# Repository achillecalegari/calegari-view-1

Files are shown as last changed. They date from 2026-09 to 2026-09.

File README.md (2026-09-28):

# Calegari View 1

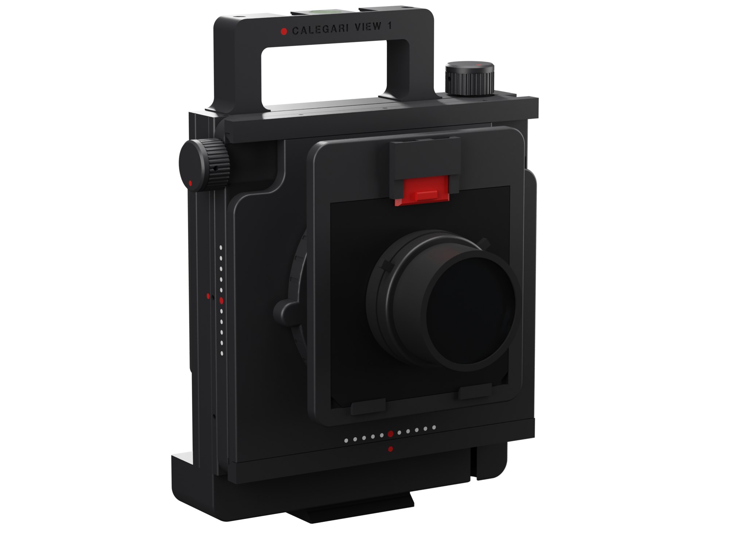
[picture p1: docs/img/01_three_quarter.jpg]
Calegari View 1


A rigid 6x7 architecture camera you can print at home. Screw-driven rise and shift on two axes, helicoid focusing, Mamiya RB67 film backs, large-format wide-angle lenses on Linhof Technika boards.

**[Project page](https://achillecalegari.github.io/calegari-view-1/)** · [Shopping list](docs/bom.md) · [Printing](docs/printing.md) · [Assembly](docs/assembly.md) · [Calibration and tests](docs/calibration.md) · [Using the camera](docs/using.md) · [Design notes](docs/design.md)

## Why I made it

I have wanted a view camera for years. The rigid kind, compact, built for architecture: you put it on the tripod, raise the lens a couple of centimetres and the verticals stay vertical, straight on the negative, with nothing to fix afterwards.

The problem is the price. A new Arca-Swiss or Silvestri costs thousands before you add a lens, and the used market is not much kinder. So I designed my own, around what I already had: a Bambu Lab P1S, the Mamiya RB67 backs you can find everywhere for little money, and a used large-format wide angle.

This repository is the whole camera: the files to print, the parametric model they come from, the shopping list with links, and step-by-step instructions written for someone who has never held a view camera. Every hole of every printed part is shown in a picture with a letter, and a table says what goes into it. Without back and lens, the parts cost about 350 EUR, much of it in packs of screws and inserts that will outlast the camera.

## What it is

| | |
|---|---|
| Format | 6x7 (56 x 69.5 mm); the gate also clears 6x8 |
| Back | Mamiya RB67 Pro, Pro-S, Pro-SD on a Graflok-type interface; Mercury Works Graflok 23 ground glass. The back turns a quarter turn for portrait, with a click at both positions |
| Lens | 65 mm large-format wide angle in Copal 0 (Super-Angulon 65/8, Nikkor-SW 65/4, Grandagon-N 65/4.5) on a Linhof Technika 99 x 96 board |
| Movements | rise and fall +/-25 mm, lateral shift +/-25 mm, on printed dovetail ways with gibs; M6 lead screws, 1 mm per turn, hard stops, zero detents |
| Focus | M65 helicoid 17-31 on a metal flange, 116 mm focus ring with a tab and a hidden infinity stop, infinity to 0.47 m |
| Tripod | one Arca-Swiss plate under the body; the camera stays upright for portrait, only the back turns |
| Lens change | every lens on its own board: a spring latch, no tools, ten seconds; printed shims put every lens at infinity on the same stop |
| Handle | one top handle with the engraved name, two ISO 518 accessory shoes and a bull's-eye level; the rise knob sits on the body top beside it |
| Size | 185 x 247 mm front (170 mm body, handle and knobs included), 161 mm deep with back and lens |
| Weight | about 1.2 kg without back and lens (about 830 g of printed ASA, 360 g of metal); about 2.1 kg ready to shoot (estimate) |

The body, the Y plate and the lens panel are flat slabs that slide face to face on printed dovetail ways, like the standards of a technical camera. Every plate covers the opening of the one behind it with at least 13 mm of black velvet at every shift position: that is how it stays light-tight without a bellows. The back sits on a round rotator that turns in the body's rear face, sealed by a labyrinth and a ring of velvet: for vertical pictures you turn the back, and the tripod, the level and the knobs stay where they are. No screw head shows on the front or the sides.

| | | |
|---|---|---|
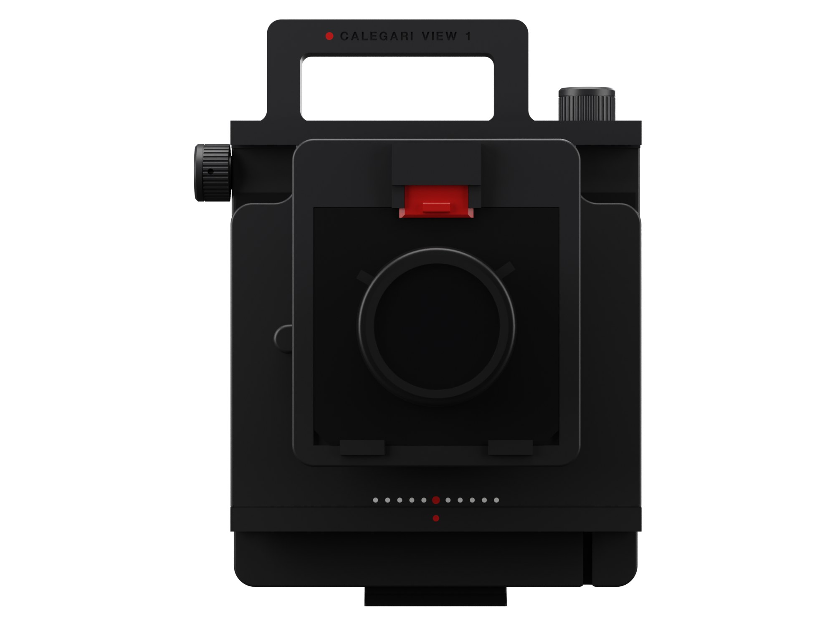
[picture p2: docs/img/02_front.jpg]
front
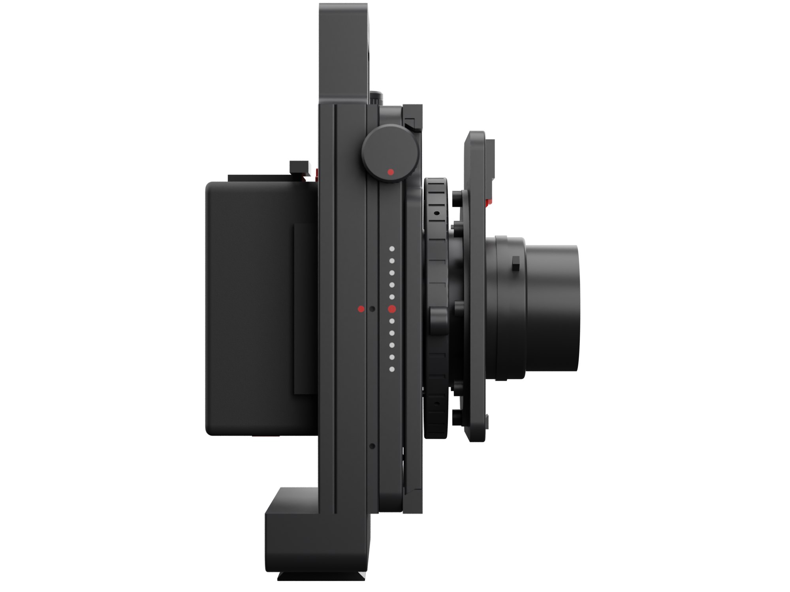
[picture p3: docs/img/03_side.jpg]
side
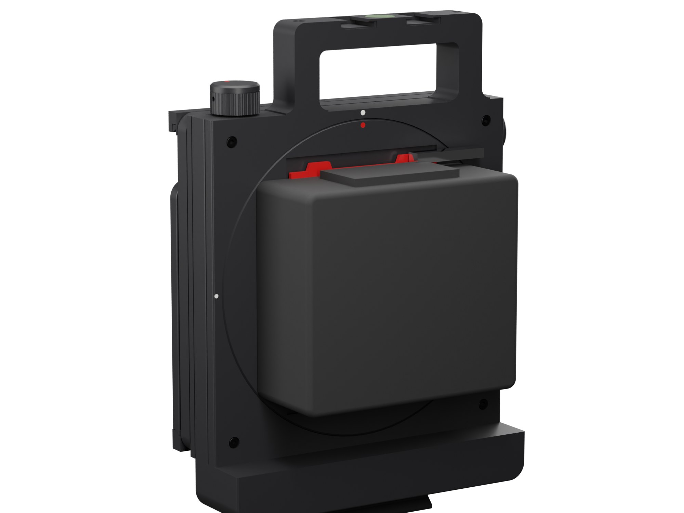
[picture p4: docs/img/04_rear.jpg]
rear
|  |  |  |
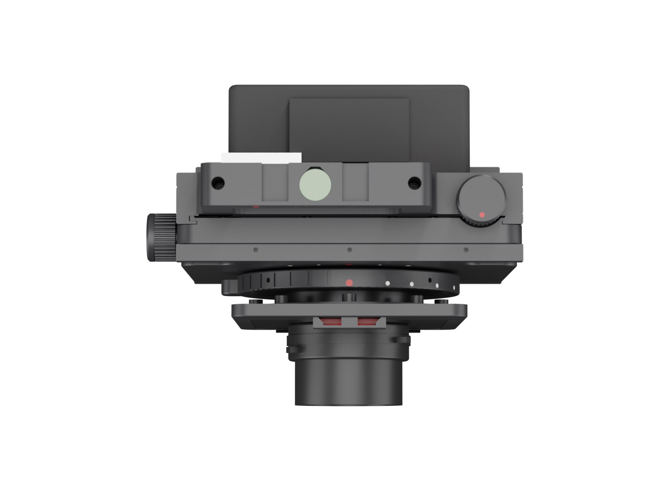
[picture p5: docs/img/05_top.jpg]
top
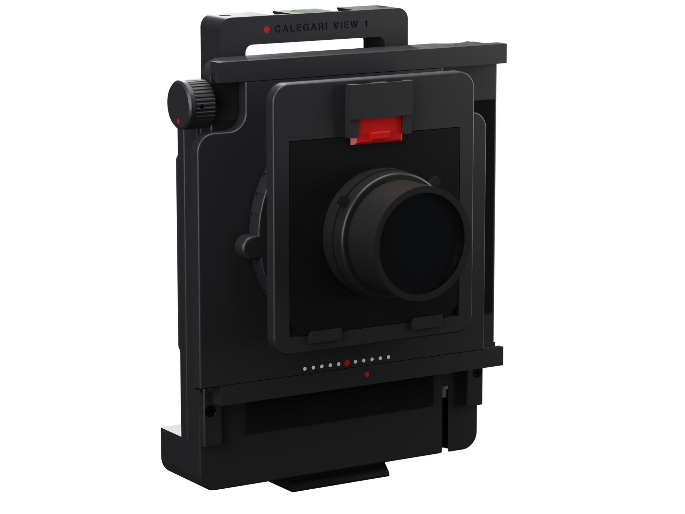
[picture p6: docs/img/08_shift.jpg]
rise and shift
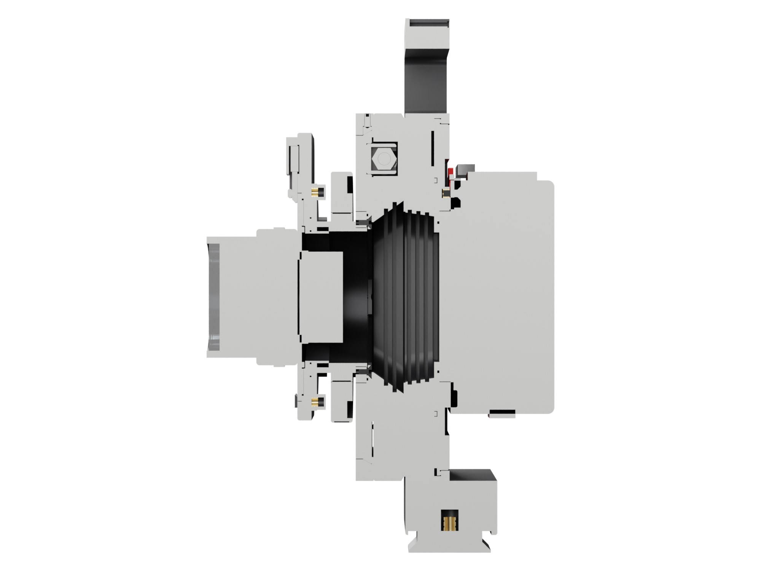
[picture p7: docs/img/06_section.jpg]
section
|  |  |  |

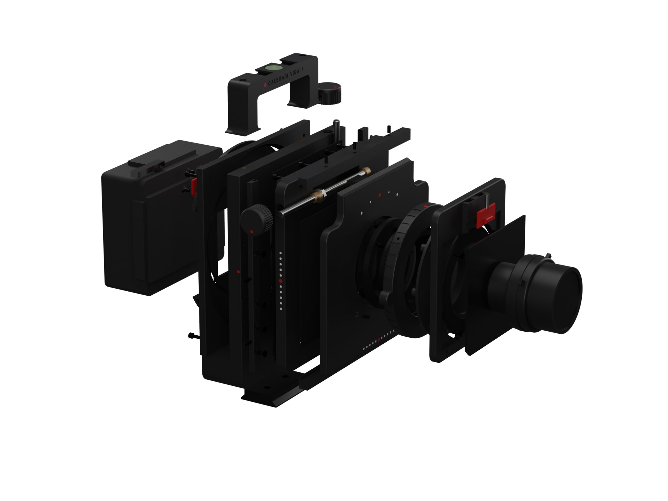
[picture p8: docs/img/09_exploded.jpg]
exploded


## Status

The design is complete and checked in software, not yet proven in the hand.

- `cad/check.py`: no interference between any of the components, screws against the bottom of their holes included, at home and at the four shift extremes, with the Graflok blade and the board latch both closed and open, with the back in landscape, in portrait and halfway between. Every printed part is a single solid.
- `cad/seal_check.py`: the velvet seal is at least 13 mm wide at both sliding interfaces, at every shift position in 5 mm steps.
- `cad/optics_check.py`: a ray trace from the lens to the corners of the frame, with the back in landscape and in portrait. Single movements up to 25 mm are clean at f/22 and f/8 at infinity. Combined rise and shift are clean up to 19 + 19 mm at infinity at f/22, 17 + 17 at f/8, 13 + 13 at 0.7 m and 9 + 9 at the closest focus (0.47 m): the 61 mm bore of the helicoid's rear stub is the limit.
- `print/PRINTABILITY.txt`: overhangs and bridges of every part in its print orientation. No part needs supports.
- Before the first print the design went through three rounds of independent review: mechanics, light and optics, printability, assembly and use. What changed is in the [design notes](docs/design.md).

What only the first physical build can prove is listed in [calibration and tests](docs/calibration.md). It starts with about four hours of test prints: the shrinkage of your ASA, the rotator on your RB67 back, and slices of the dovetail ways to slide by hand. They come before the body.

## The model

Everything is generated from Python with [build123d](https://github.com/gumyr/build123d). All dimensions live in `cad/params.py`: change a value (a lens with a different flange distance, a helicoid that turns a different angle, a tighter or looser fit) and rebuild the whole camera.

```bash
python -m venv .venv && .venv/bin/pip install -r requirements.txt
cd cad
../.venv/bin/python check.py          # interference, single-solid and clamp checks
../.venv/bin/python seal_check.py     # velvet seal widths over the whole shift range
../.venv/bin/python optics_check.py   # ray trace: vignetting at shift, aperture and focus (about 15 minutes)
../.venv/bin/python export.py         # STEP, oriented STL, AMS inlays, P1S plates, test prints
../render/gen_all.sh                  # product and overview images in docs/img (needs Blender)
../render/figures.sh                  # figures for every guide, docs/img/asm, cal, use and bom (needs Blender)
../.venv/bin/python plate_figs.py && ../render/figures.sh $(ls ../out/figs | grep ^p_)   # the print plates
../.venv/bin/python ../render/diagrams.py   # the flat calibration diagrams
```

The STEP files in `print/step` open in Fusion, FreeCAD or any CAD.

## Credits

The RB67 interface was measured from two open designs that take the same backs: [Super-67](https://github.com/DamienHazard/Super-67) by Damien Hazard, and the [RB67 pinhole body](https://www.thingiverse.com/thing:7270507) by bogdanbogvzyan, tested with Pro-S and Pro-SD backs. Lens data come from the Schneider, Nikon, Rodenstock and Fujinon catalogues and the Mercury lens database; Graflok 23 figures from Mercury Camera's guide.

## License

[CC BY-NC-SA 4.0](LICENSE). Build it, change it, share it with credit; do not sell it.

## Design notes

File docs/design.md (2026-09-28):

# Design notes

[Back to the project](../README.md)

## Architecture

The camera is a stack of flat slabs on the optical axis, from the film forward:

Exploded view

1. **Rotator** (printed): the round seat of the back. The back's nose pocket, the fixed bottom rail that hooks the back and releases the Pro-S dark-slide interlock, and the red clamp blade with two tongues. It turns a quarter turn for portrait.
2. **Rear frame** (printed): screwed to the body with four M3, it holds the rotator's flange over a ring of velvet.
3. **Body** (printed, one piece, 170 mm square): the round seat of the rotator with a labyrinth ridge, the stepped gate, the two vertical dovetail rails, the rise screw, and the Arca plate underneath.
4. **Y plate** (printed): rises and falls between the vertical rails, carries the two horizontal dovetail rails and the shift screw.
5. **Lens panel** (printed): shifts left and right, carries a metal M65 flange.
6. **Optics on the flange:** the helicoid, the printed adapter ring, the Technika board holder and the lens.

Section

The light seal is the flatness of these faces. Each plate covers the opening of the one behind it, and the band of black velvet between them is at least 13 mm wide at every shift position (`cad/seal_check.py`, swept every 5 mm). The thin flanges of the dovetail rails set the 0.8 mm gap and the velvet is compressed in it, so the velvet never carries load.

## Choices and why

| Choice | Why |
|---|---|
| 6x7 with RB67 backs | backs are common and cheap; the Graflok-type interface is simple enough to print; the gate also clears 6x8 |
| 65 mm lenses in Copal 0 | 33 mm equivalent on 6x7, cheap used, image circles of 153 to 170 mm for large shifts |
| Technika 99 x 96 boards | the most common board: lenses often come mounted on one, and it swaps with 4x5 field cameras |
| One board per lens, spring latch | a lens changes in ten seconds without tools; the red latch slides in a printed dovetail, held by two screws from the back, so nothing shows on the front; printed shims under the shutter (0.4 to 1.2 mm) let every lens reach infinity on the same stop |
| Metal M65 flange on the lens panel | a printed thread carrying the lens and the focusing torque was the weakest point of the first design |
| Printed adapter ring as the calibration part | if infinity is out of reach, reprint a thinner 20-minute part instead of a plate |
| Printed dovetail ways with a gib | the way view cameras have always done it: nothing to buy, nothing to align, play taken up by three grub screws. The rails print as separate parts, so the sliding flanks come from the printer's perimeters, not from stair-stepped layers; test coupons prove the fit on your printer before the big parts |
| Front standard assembled on the bench, then slid in from the top | the Y plate's front overhangs the vertical rails (the shift screw passes over them), so it goes in like a drawer; the rise nut turret is screwed on afterwards through the plate |
| M6 threaded rod and brass nut, 1 mm per turn | fine control, self-locking under gravity, parts from any hardware shop; the nut floats 0.5 mm so the rod never binds. The rise rod ends in a plain M6 nut and washer, fixed on the bench and hidden under the camera. The shift rod shows nothing on the left: it ends in a blind seat, and a washer and a nut locked inside the channel hold it against the knob side. No hardware in sight on the front or the sides |
| All small hardware in M3 | one insert size (M3 x 3 x 5) for every insert, socket heads in three lengths, countersunk in two (only where a head must sit flush: the flange, the Graflok blade, the thin vertical rails and the board holder), one grub size. Four assortments and an M6 set buy the whole camera; three hex keys build it |
| Shift nut turret keyed into the lens panel | the hard stops push on the pocket walls, not on the glue |
| O-ring drag instead of lock wheels | lock wheels moved the composition as you tightened them; constant drag holds the plate and never shifts it |
| Ball-plunger detents | you feel zero without looking; the rise and shift plungers sit in through holes, so they are set from behind and then sealed; the third one clicks the back at landscape and portrait |
| Rise and fall +/-25, the same as lateral shift | the base under the body is 25 mm tall so that at full fall the Y plate stays clear of a clamp's jaws; the two scales read the same way |
| Rotating back instead of an L bracket | for portrait the camera stays on its plate: the level, the handle and the knobs keep their meaning and the tripod head does not have to flop over. The rotator turns in the body's rear face on a velvet ring held by a screwed rear frame; a labyrinth (a ridge on the body in a groove of the rotator) keeps light out while it turns; a POM ball plunger clicks at landscape and portrait, and a grub screw in an arc groove stops it just past both. Plunger and grub go in from the front, under the Y plate, so nothing shows |
| Square body, 170 mm | the rotator needs a circle of 165 mm around the back, and a square body is the calmest shape around a circle; the window gets 12 mm corners so the labyrinth fits around it |
| One top handle, bolted, as deep as the body | feet flared into the body, 9 mm of finger room to the rise knob beside it; nothing overhangs the film back's advance lever; room on top for two ISO 518 accessory shoes and a bull's-eye level, and on its front for the engraved name |
| One bull's-eye level | a tubular vial reads one direction only; the one that keeps verticals vertical is front to back. The camera never goes on its side, so one level serves both orientations |
| Hidden infinity stop | a pin on the lens panel runs in a groove under the focus ring and meets one solid block at infinity; you set it by turning the ring on the helicoid, no adjusting screw |
| Recessed dot scales, red only for zeros, infinity and release controls | print cleanly in multi-material; red means "this is the reference" or "this lets go" |

## Design reviews

The design went through three rounds of independent review before the first print: mechanics and tolerances, light and optics, printability, and assembly and use by someone who has never built a camera. Each finding was measured in the CAD, fixed, and checked again. The main ones:

| Area | Found | Fix |
|---|---|---|
| RB67 interface | the dark slide could not come out; the latch bars had no tongues; nothing released the Pro-S interlock | Graflok seat rebuilt on the scheme of a body tested with Pro-S and Pro-SD, dark-slide passage open to the right |
| Mechanics | industrial linear guides were overkill and made the build long | printed dovetail ways with gibs, test coupons |
| Assembly | the Y plate could not go on once the rails were fixed; the rod nuts could not be tightened inside the camera | the plate slides in from the top; the rise end nut is fixed on the bench, the shift thrust nut before the lens panel goes on |
| Assembly | the board holder's screws were unreachable under the focus ring | they now go in from the front, under the board, into eight inserts in the adapter |
| Mechanics | the Graflok wheel did not turn its screw; screws too long in six places; the detent balls never touched the plate | screw head glued in the wheel; every screw length checked against its hole; balls 1.0 mm proud with a 0.3 mm seat |
| Mechanics | the shift hard stop loaded a glued joint | the turret sits in a 2.5 mm pocket |
| Optics | the lens panel bore cut the corner at large combined shifts | flare lobes on the diagonals; single movements reach 25 mm clean at infinity |
| Optics | the ray trace left out the helicoid's rear stub, whose 61 mm bore is the narrowest opening | stub modelled (5.2 mm, the lens panel relieved behind the flange); combined movements are clean to 19 + 19 at infinity (f/22), 17 + 17 at f/8, 13 + 13 at 0.7 m, 9 + 9 at the closest focus (0.47 m) |
| Light | screw holes and a detent hole could carry light around the velvet | velvet discs over the turret screws, the detent moved outside both velvets, black paint in the flange's unused holes, light-trap grooves in the seat and the flange pocket |
| Printing | knife edges, a hood printed in the air, thin walls under inserts | chamfers and lands on every bed edge that mates, a hood bridging rail to rail, thicker walls |
| Use | tubular levels could not show the tilt that bends verticals | a bull's-eye level on the handle |

## Automated checks

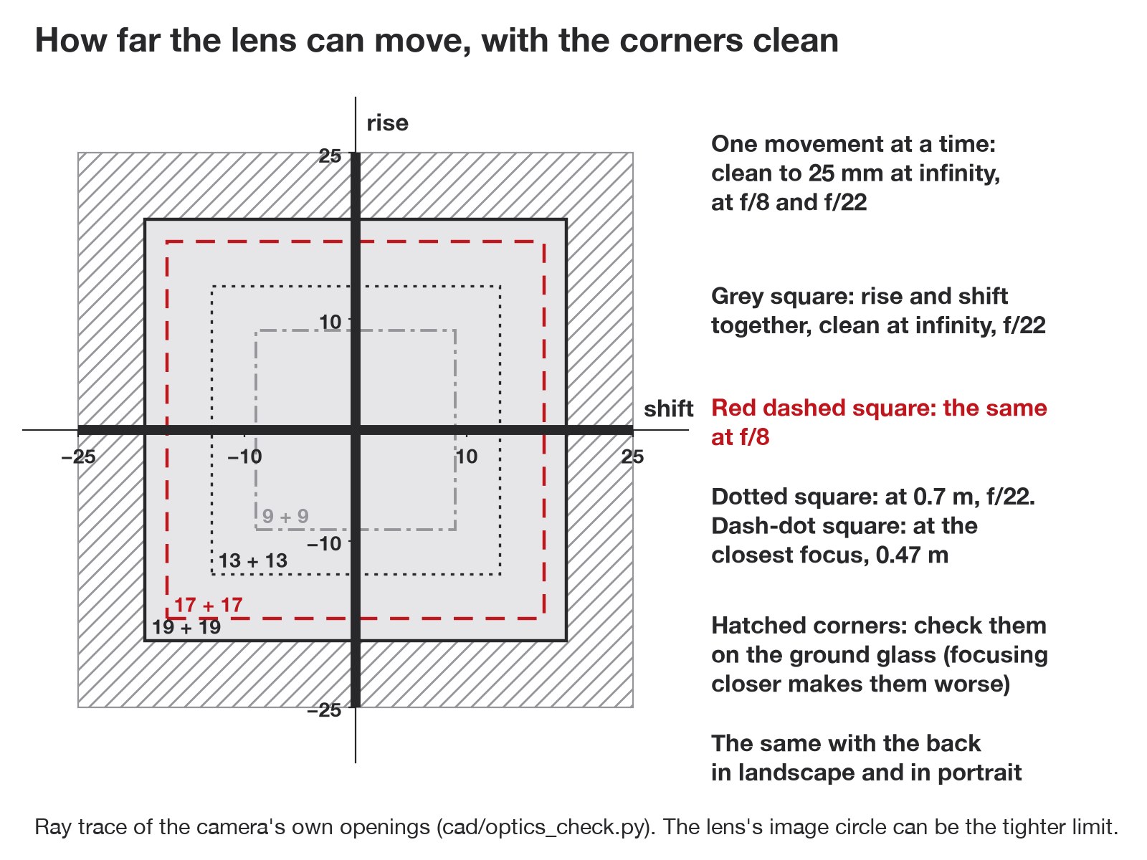
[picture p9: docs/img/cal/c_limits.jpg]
Shift limits from the ray trace


| Script | What it proves |
|---|---|
| `cad/check.py` | every printed part is one solid; no two parts intersect (threshold 0.3 mm3) at home and at the four shift extremes, with the blade and the board latch closed and open, with the back in landscape, in portrait and halfway, including every screw against the bottom of its hole |
| `cad/seal_check.py` | minimum width of the velvet band around the light path at both sliding interfaces, at every shift position in 5 mm steps |
| `cad/optics_check.py` | rays from the lens pupil to the four corners of the frame, through every part, at the shift, aperture and pupil positions listed in the script, with the back in landscape and in portrait |
| `cad/export.py` | `print/PRINTABILITY.txt`: overhangs and bridges of every part in its print orientation |

## Open points

- **RB67 interface.** It is derived from reference designs and has not yet been fitted on a real back. The RB67 model used by the checks has no lips or slots, so the back-to-rotator fit is not part of the automated check: it is test print #1 ([calibration](calibration.md#1-before-printing-the-body-test-prints)).
- **Wind-stop coupling.** Not implemented: after each frame, press the back's own release lever, as on the Mamiya Press. A plunger at the top-left corner of the rotator is the planned v2 feature (M7 in the calibration list).
- **Lens tilt.** The board can be squared in rotation through the holder's arc slots, but it cannot be adjusted in tilt. Parallelism relies on flat prints: check it with the procedure in calibration.
- **Focus scale.** It is correct only once `HELI_ROT` and `FOCUS_DIR` are measured on your helicoid.

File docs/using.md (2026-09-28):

# Using the camera

[Back to the project](../README.md)

A first-timer's guide, from the bag to the negative. If a word is new, [the camera in five minutes](calibration.md#the-camera-in-five-minutes) explains it.

## What to bring

- The camera, with a lens on its board in the holder.
- The ground glass and one or more RB67 backs, loaded, dark slides in.
- A loupe (4x to 8x), a dark cloth, a cable release that screws into the shutter.
- A light meter, or a meter app on the phone.
- A tripod with an Arca-Swiss clamp.
- Other lenses on their own boards, rear caps on.

## 1. Set up

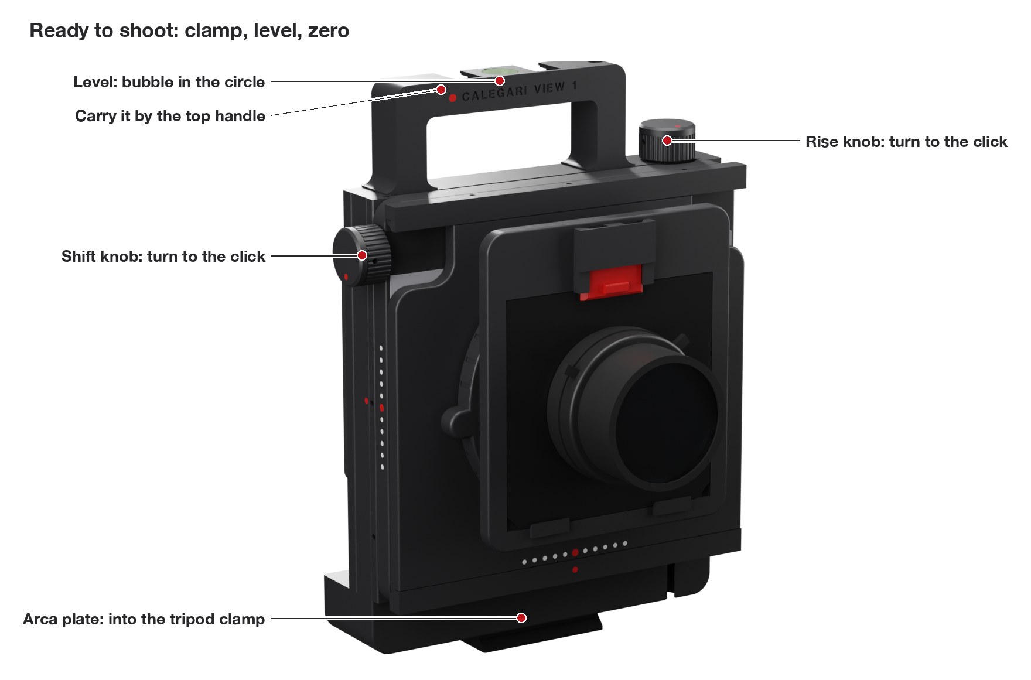
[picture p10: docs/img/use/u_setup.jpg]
Ready to shoot


1. **Clamp the camera** by its Arca plate. It stays upright for vertical pictures too: you turn the back, not the camera. Carry it by the top handle.
2. **Level it.** Adjust the tripod head until the bubble on top of the handle is in the middle of its circle. It reads both directions, and it stays right when you turn the back. The one that matters most is front to back: a camera tilted up or down makes the vertical lines of a building lean. This is the whole point of the camera, so do not skip it.
3. **Set both movements to zero.** Turn each knob until it clicks.
4. **Horizontal or vertical.** Take hold of the back (or the ground glass) with both hands and turn it a quarter turn: anticlockwise from landscape to portrait, as you look at it from behind. It clicks at both ends and stops just past them. The red dot on the back's rim sits on the big white dot at the top for landscape, on the small one on your left for portrait. The rise knob still raises the lens, whichever way the picture is.

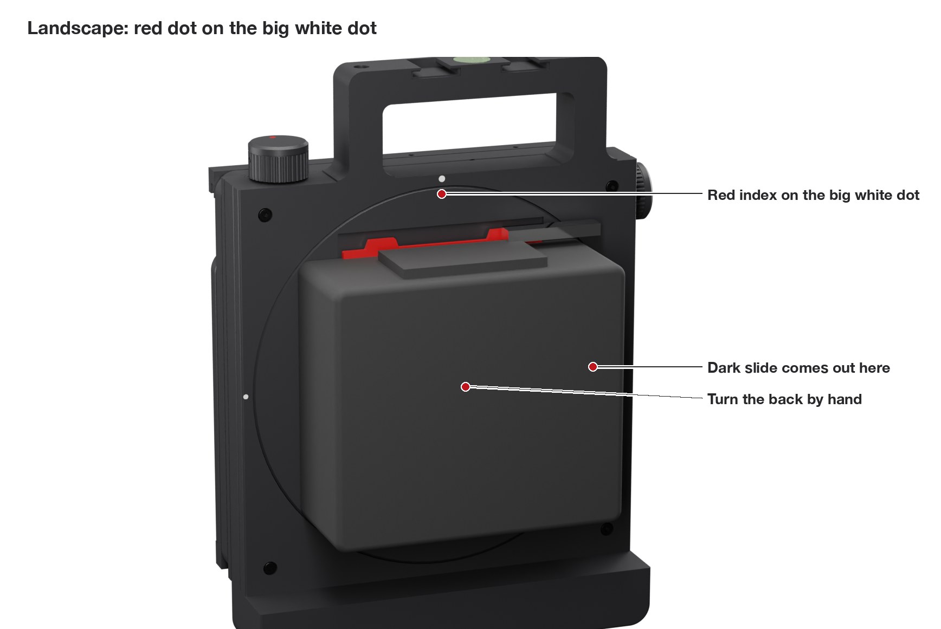
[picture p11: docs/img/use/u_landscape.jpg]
Landscape


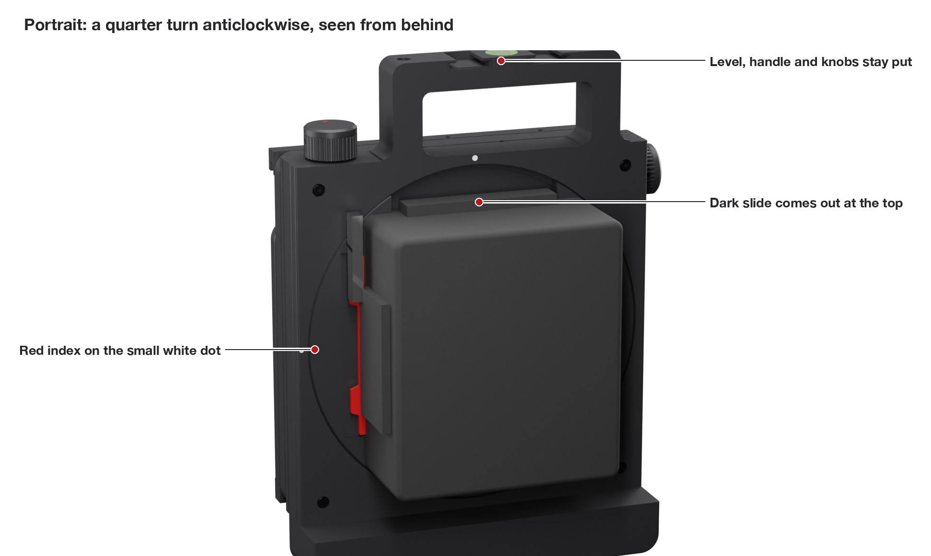
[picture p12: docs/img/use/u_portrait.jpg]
Portrait


## 2. Compose on the ground glass

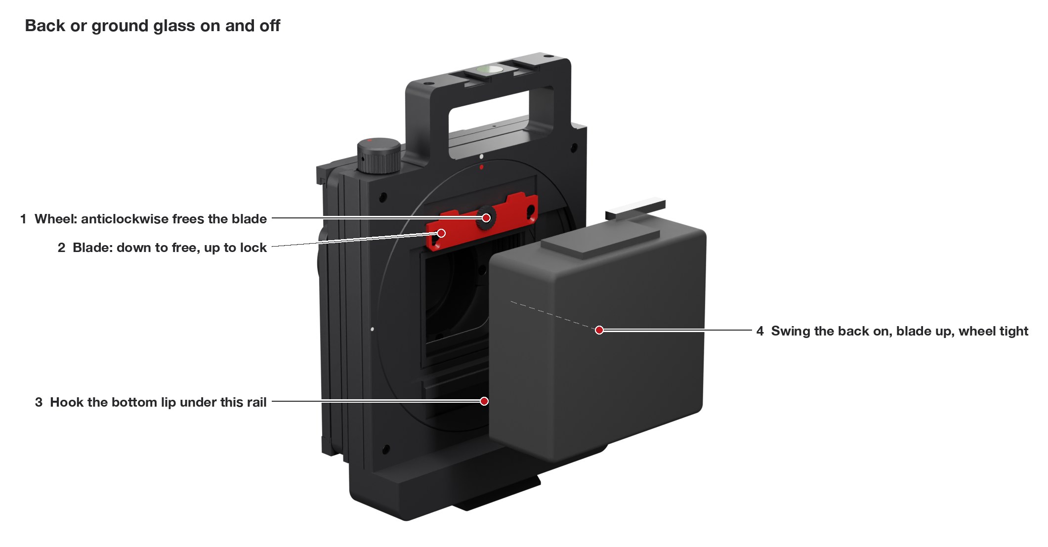
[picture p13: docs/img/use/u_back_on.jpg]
Back or ground glass on and off


1. **Ground glass on.** If a back is mounted, check its dark slide is in, then take it off: loosen the wheel, slide the red blade down, lift the back off the bottom rail. Mount the ground glass the same way in reverse.
2. **Open the shutter.** Set the speed dial to **T** or **B** and fire, or push the *press focus* lever. Turn the aperture to its largest opening.
3. **Look.** Cloth over your head and the camera. The image is upside down and mirrored left to right: after ten minutes you will stop noticing. The glass shows a little more than the film: compose inside the 6x7 marks (the Mercury glass has them; with another glass, mark the 69.5 x 56 mm frame with a fine pen during calibration).
4. **Use the movements instead of pointing the camera.** The top of the building is cut off? Do not tilt the camera up: turn the top knob to raise the lens (rise). Too much of the left side? Turn the side knob to shift the lens sideways. The picture slides across the glass while the verticals stay vertical.

**Reading the movements.** Each knob turn moves the lens 1 mm; the red dot on the knob top helps count turns. For bigger moves, read the dots on the plates:

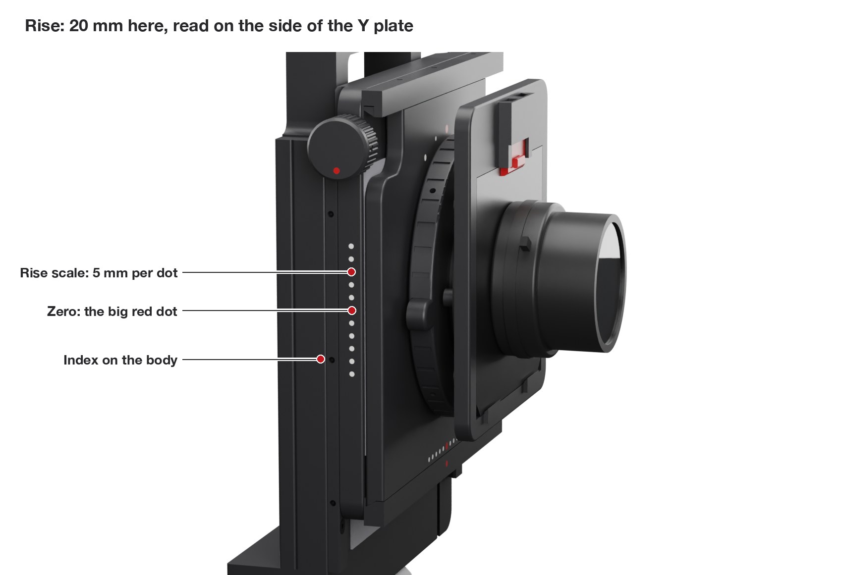
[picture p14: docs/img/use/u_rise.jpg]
Rise


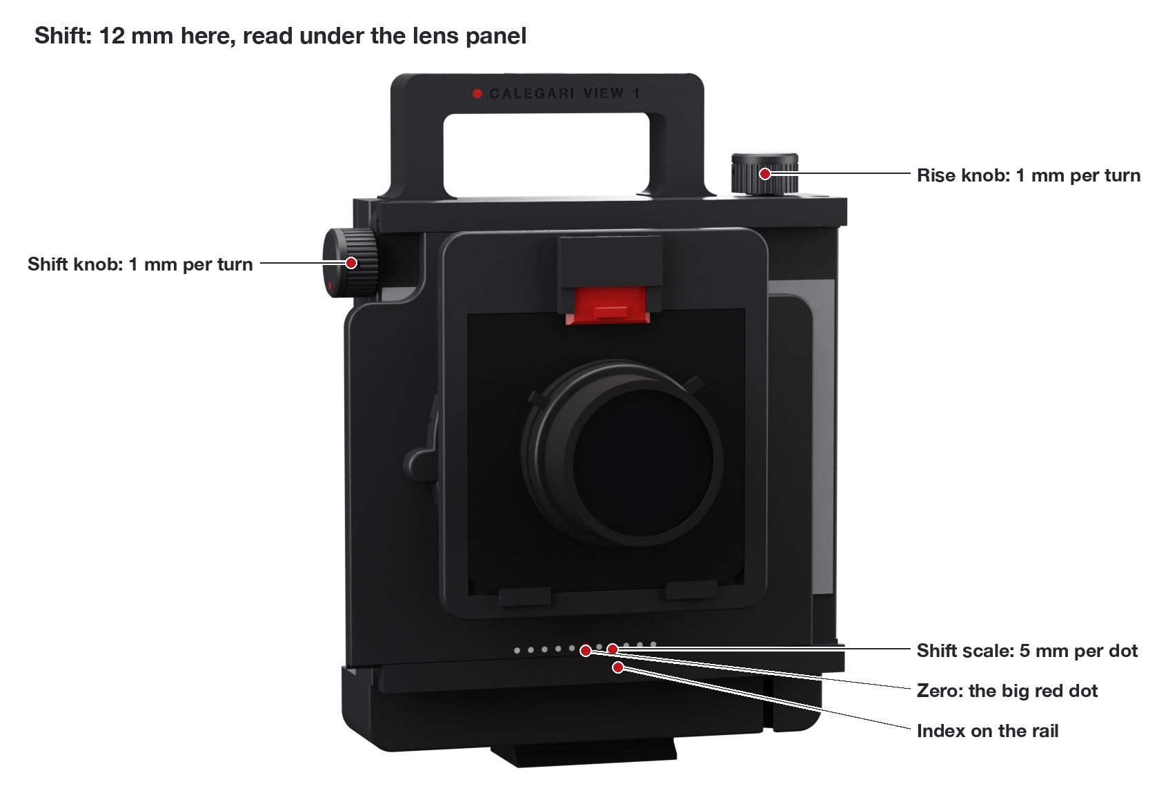
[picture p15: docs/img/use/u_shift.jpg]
Shift


- **rise and fall:** the dots on the right edge of the Y plate (as you stand behind the camera) pass a red dot on the body. Every dot is 5 mm; the big one is zero.
- **shift:** the dots along the bottom of the lens panel's front pass a red dot on the bottom rail, again 5 mm apart; the big red one is zero.

**How far can you go?** 25 mm in every direction, one movement at a time. Rise and shift together reach about 19 + 19 at infinity (17 + 17 at f/8), 13 + 13 at 0.7 m, 9 + 9 at the closest focus (0.47 m), and less with a lens with a smaller image circle: see [the limits](calibration.md#9-limits-worth-knowing). To check, look into each corner of the ground glass from a hand's width away, toward the lens: if you see the whole round aperture, the corner is covered.

## 3. Focus

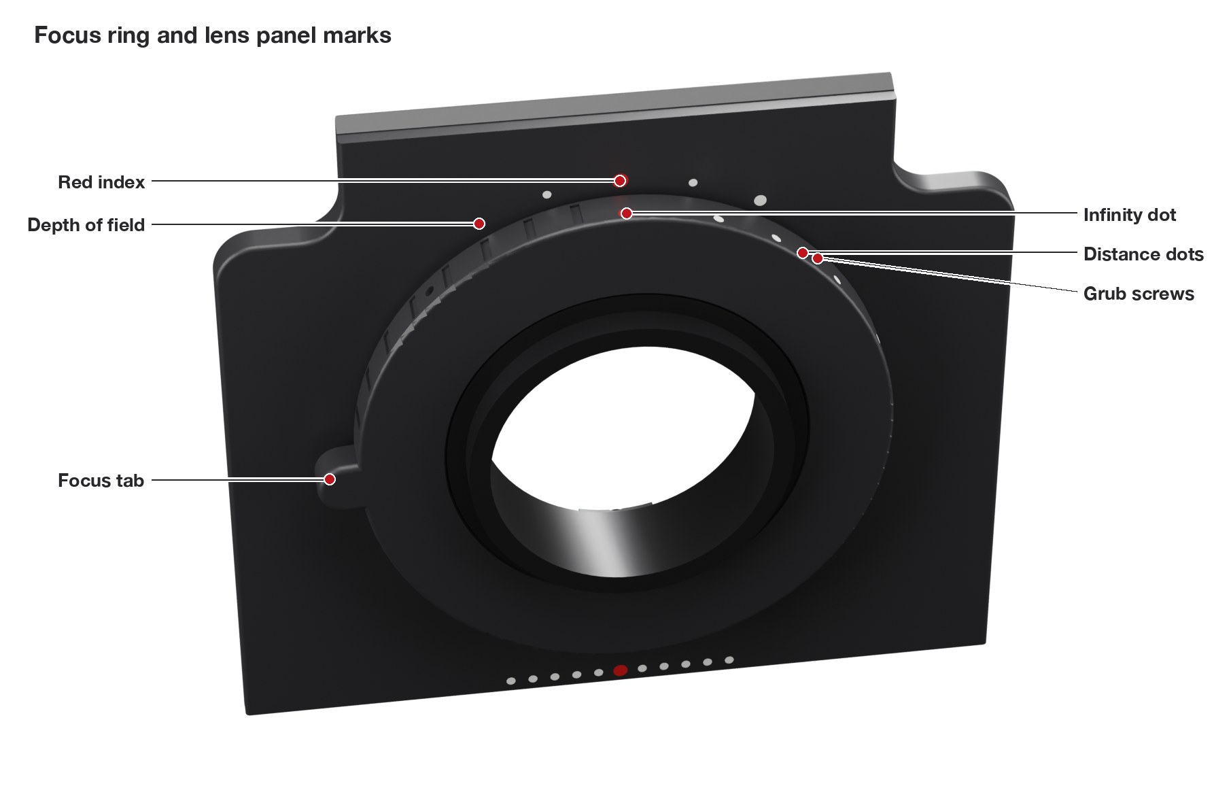
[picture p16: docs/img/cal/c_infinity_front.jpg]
Focus ring and marks


- **With the ground glass.** Put the loupe on the glass over the part that matters most and move the focus lever until it is sharp. Go past and come back.
- **Without it.** Move the lever until the white distance dot you want faces the red dot on the lens panel (the big red dot is infinity; the white ones are 5, 3, 2, 1.5, 1 and 0.7 m). The pairs of white dots either side of the red one show what is sharp: the small pair at f/11, the big pair at f/22.

## 4. Take the picture

1. **Close the shutter.** Set the speed you metered (out of T or B), and release the press-focus lever if you used it. The shutter must be closed before the next step.
2. **Set the aperture** you metered, **cock** the shutter lever, screw in the cable release.
3. **Swap the ground glass for the back.** Wheel loose, blade down, glass off. Hook the back under the bottom rail, swing it on, blade up, wheel tight. Push the back with your hand: it must not move.
4. **Pull the dark slide** out: toward the right in landscape, upward in portrait. Keep it in a pocket, not on the ground.
5. **Fire** with the cable release, without touching the camera.
6. **Push the dark slide back in.** Only now can the back come off.
7. **Advance the film.** Press the back's wind-stop release by hand, then turn its advance lever until it stops. The camera does not do this for you.

## 5. Change the lens (ten seconds)

Each lens stays on its own board; you change the board, not the lens.

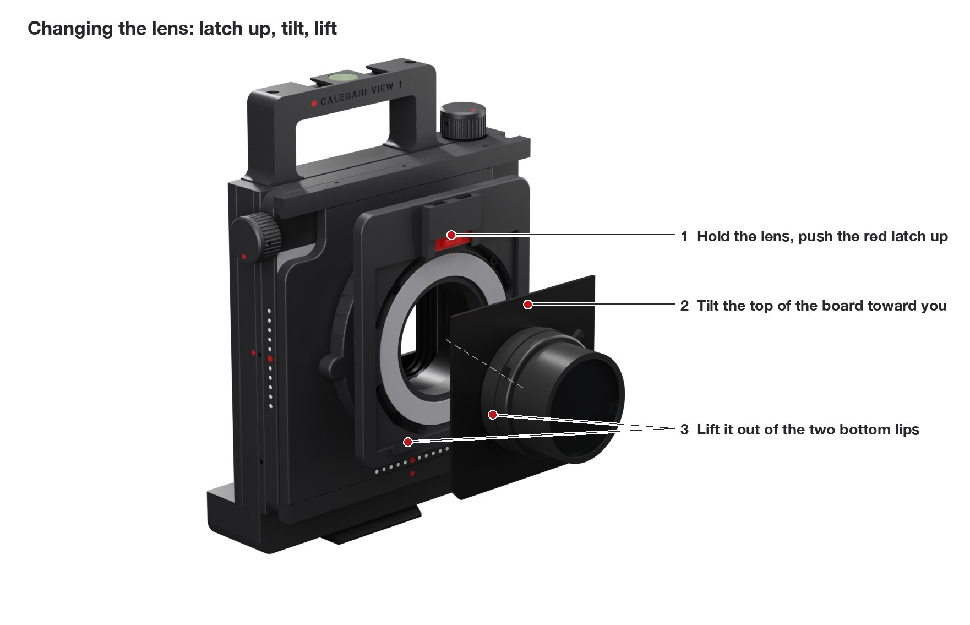
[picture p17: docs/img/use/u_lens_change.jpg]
Changing the lens


1. **Protect the film.** Close the shutter. If a back is on, its dark slide must be in.
2. **Hold the lens.** Put one hand around the lens first: with the latch up, only the two bottom lips hold the board, and the lens's weight tips it forward.
3. **Unlatch.** Push the red latch above the board up with your thumb.
4. **Lift out.** Tilt the top of the board toward you and lift it out of the two lips at the bottom. Put the rear cap on it.
5. **Put the other one in.** Rear cap off, bottom edge under the two lips, lift the latch with your thumb, press the top in and let the latch go: it drops over the board.
6. **Check.** The board does not move when you push it.

If every board has its shim (see [calibration, section 4](calibration.md#4-more-lenses-one-stop-for-all-of-them)), infinity is still on the stop and the distance dots still read right. Without shims, focus on the ground glass.

## 6. Pack up

- Movements back to zero (the knobs click), focus to infinity.
- Dark slides in, backs off or on as you like.
- Lens cap on, or the board out and capped.
- The top handle is also where a strap and the dark cloth hang from.

## 7. Care

- The dovetails like a light spray of dry PTFE once a year, spread by running each plate end to end. If a plate starts to rock, turn its three gib grub screws in a little, evenly.
- Keep the velvet clean: a strip of tape lifts dust from it.
- ASA does not mind a hot car or the sun, but do not clean it with acetone.
- If a knob gets stiff or loose over time, see [calibration, section 8](calibration.md#8-if-something-is-wrong).

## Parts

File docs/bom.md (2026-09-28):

# Shopping list

[Back to the project](../README.md)

Everything to buy for one camera, with links (checked on 2026-09-27 and 28; prices are what the page showed, VAT included, shipping extra). Several listings sell a family of sizes: pick the size in the **Spec** column. Shops come and go: the spec is what matters, the link is one place that had it.

Most items come in packs: the quantities below are what the camera uses.

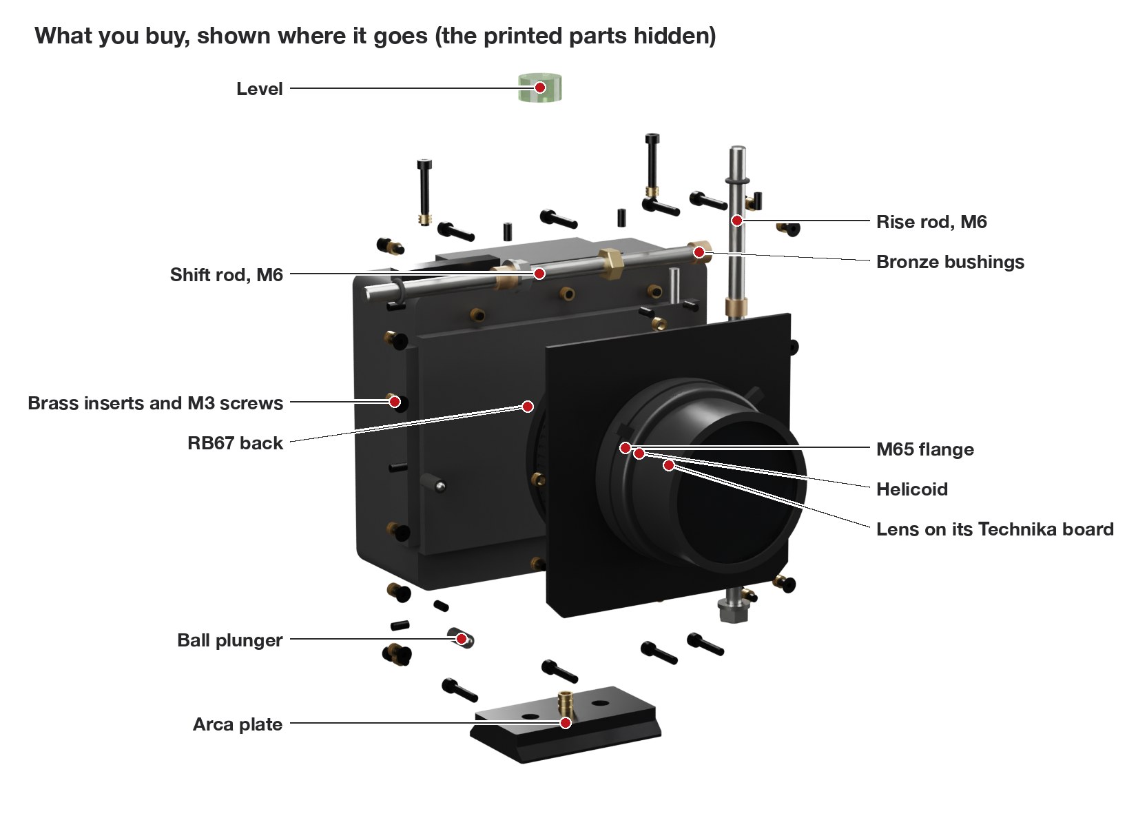
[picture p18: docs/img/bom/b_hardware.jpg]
What you buy, shown where it goes


The AliExpress column is a cheaper second source, found on 28/09/2026. AliExpress blocks automated page checks, so those links were matched from the listing titles, not from the product pages: open each one and pick the variant written next to it before ordering. The inserts' outer diameter matters most (the holes are drawn for the sizes in the Spec column).

## Drive

The two movements slide on printed dovetail ways: there are no linear guides to buy.

| Item | Spec | Qty | Link | AliExpress | Price seen | Notes |
|---|---|---|---|---|---|---|
| M6 threaded rod | stainless A2, DIN 976, 1 m | 1 | [Amazon.it](https://www.amazon.it/dp/B09MMFZBV2) | [AliExpress](https://it.aliexpress.com/item/1005006143432046.html): M6 x 500 (or two of 300) | 7.61 EUR | select M6; cut 178 mm (rise) and 138 mm (shift), deburr the ends |
| M6 hex nut, brass | 10 mm across flats | 2 | [Amazon.it](https://www.amazon.it/dp/B0F6V4BLQG) | [AliExpress](https://it.aliexpress.com/item/32854183955.html): M6 | 11.29 EUR / 15 | the two drive nuts |
| M6 hex nut, stainless | DIN 934, A2 | 4 | [Amazon.it](https://www.amazon.it/dp/B0B6BYB1CN) | [AliExpress](https://it.aliexpress.com/item/1005006277948812.html): M6 | 10.19 EUR / 50 | two pressed into the knobs, two end the rods (the shift rod's thrust nut, the rise rod's end nut) |
| M6 washer | DIN 125, A2 | 2 | [Amazon.it](https://www.amazon.it/dp/B087QLYDLB) | [AliExpress](https://it.aliexpress.com/item/4000174460068.html): M6 | pack of 50 | one under each end nut |
| Self-lubricating bushing | 6 x 8 x 6 mm, sintered bronze or wrapped | 4 | [Amazon.it](https://www.amazon.it/dp/B0C3H8R1YG) | [AliExpress](https://it.aliexpress.com/item/1833939865.html): 0606 (composite) | pick 6x8x6 | pressed into the ends of the two screw channels |
| M5 ball spring plunger | M5 x 10 or 12, hex socket at the back, POM (plastic) ball; a steel ball also works | 3 | [Amazon.de](https://www.amazon.de/dp/B0CD1XP9H9) | [AliExpress](https://it.aliexpress.com/item/32993163855.html): M5 x 10 | 12.20 EUR / 30 | the rise and shift zero clicks, and the click of the rotating back at landscape and portrait. A POM ball clicks softer and never marks the printed plate: search "POM ball plunger M5" |
| O-ring | NBR 70, 6 x 1.5 mm | 2 | [Amazon.it](https://www.amazon.it/dp/B0F7DXPHTC) | [AliExpress](https://it.aliexpress.com/item/1005004891402236.html): OD 9 (= 6 x 1.5) | pick 6 x 1.5 | knob drag |
| Compression spring | 4 mm OD x 15 mm, light | 1 | [Amazon.it](https://www.amazon.it/dp/B0CTJVH96W) | [AliExpress](https://it.aliexpress.com/item/1005009455656166.html): OD 4, L 15 | pick 4 mm x 15 mm | board latch |
| Dry PTFE lubricant | spray, dries to a film | 1 | [Amazon.it](https://www.amazon.it/dp/B07C7H4PLS) | buy locally | 400 ml | a light coat on the dovetails; candle wax also works |

## Fasteners and inserts

All the small hardware is M3 stainless, and one insert fits every hole that has one: four assortments cover the camera.

| Item | Spec | Qty | Link | AliExpress | Price seen | Notes |
|---|---|---|---|---|---|---|
| Heat-set insert M3 | 3 mm long, 5 mm OD ("M3 x 3 x 5") | 29 | [Amazon.it](https://www.amazon.it/dp/B0FQTNZ6TP) | [AliExpress](https://it.aliexpress.com/item/1005004856964661.html): M3 x 3, check OD 5 | 7.99 EUR / 50 | every insert in the camera; the holes are drawn for this size |
| M3 socket head kit | ISO 4762, stainless, 4 to 20 mm | 1 | [Amazon.de](https://www.amazon.de/dp/B0DPWZ53X4) | [AliExpress](https://it.aliexpress.com/item/32810872544.html): stainless | 8.39 EUR / 1160 | uses x 10 (6: rear frame, rise turret), x 16 (8: horizontal rails), x 20 (2: top handle) |
| M3 countersunk kit | ISO 10642, stainless, 6 to 30 mm | 1 | [Amazon.de](https://www.amazon.de/dp/B0GFDNBLK2) | [AliExpress](https://www.aliexpress.us/item/2255799859561116.html): M3 x 6 and x 8 | 8.99 EUR / 1292 | uses x 6 (6: flange and Graflok blade), x 8 (14: vertical rails, board holder, Graflok wheel) |
| M3 x 6 grub screw | stainless, cup or cone point | 16 | [Amazon.it](https://www.amazon.it/dp/B09BMYYF9H) | [AliExpress](https://it.aliexpress.com/item/1005010543403767.html): M3 x 6 | assortment | gib strips (6), knobs (2), focus ring (4), stop pin (1), board latch (2), stop of the rotating back (1) |

## Tripod and levels

| Item | Spec | Qty | Link | AliExpress | Price seen | Notes |
|---|---|---|---|---|---|---|
| Arca-Swiss plate | 60 x 38 x 10 mm, aluminium, with a 1/4" slot | 1 | [Amazon.it](https://www.amazon.it/dp/B0C6F573TH) | [AliExpress](https://it.aliexpress.com/item/32832491053.html): PU60, check the slot | 14.99 EUR / 2 | under the body; remove the rubber pad; one screw in the middle, the pocket stops it turning. The camera never goes on its side: the back turns |
| 1/4"-20 screw | socket or flat head, 1/2" (12.7 mm) | 1 | usually supplied with the plate | [AliExpress](https://it.aliexpress.com/item/1005001191062013.html): 1/2" | | |
| Heat-set insert 1/4"-20 | short, 6.4 mm | 1 | [Amazon.it](https://www.amazon.it/dp/B07YZSFMMD) | [AliExpress](https://it.aliexpress.com/item/1005008591642074.html): L 6 | pack of 20 | the Arca pocket |
| Bull's-eye level | 15 mm diameter, 8 mm high | 1 | [Amazon.it](https://www.amazon.it/dp/B07TSWKTZ1) | [AliExpress](https://it.aliexpress.com/item/32788502229.html): 15 x 8 | 5 pieces | on top of the handle; it serves both orientations |

## Light seal

| Item | Spec | Qty | Link | AliExpress | Price seen | Notes |
|---|---|---|---|---|---|---|
| Black adhesive velvet | self-adhesive velour, about 1 mm | 1 roll | [Amazon.it](https://www.amazon.it/dp/B005FWUK44) | [AliExpress](https://it.aliexpress.com/item/1005001719038195.html): check 0.9 to 1.2 mm | 12.97 EUR | pieces V1, V2 and the ring V5 of the rotating back, cut with the templates in `print/templates`; measure it: it must be 0.9 to 1.2 mm to be compressed in the 0.8 mm gap |
| optical flocking (global) | Protostar Hi-Tack | 15" | [Protostar](https://www.fpi-protostar.com/hitack.htm) | | 0.50 USD / inch | better light absorption, ships from the US |
| Adhesive felt | black, 1 mm, A4 | 1 | [Amazon.it](https://www.amazon.it/dp/B089NZG3Q3) | [AliExpress](https://it.aliexpress.com/item/1005006910004507.html): black; check 1 mm | 11.39 EUR / 10 | rings V3 and V4 in the board holder, cut with `print/templates/V3_V4_felt_rings.svg` |

## Optics and back

| Item | Spec | Qty | Link | AliExpress | Price seen | Notes |
|---|---|---|---|---|---|---|
| Lens flange | RafCamera, M65 x 1 female, 79 mm, 5 mm, 8 holes (4 x M3) | 1 | [RafCamera EU](https://raf.camera/products/lens-board-lens-flange-with-m65x1-female-thread-79mm-8-screw-holes-m2-5-m3) · [US](https://rafcamera.com/board-m65x1f-8holes) | the AliExpress M65 flanges are 4 mm thick: not a drop-in | 33.00 EUR / 27.50 USD | |
| Focusing helicoid | M65 x 1 to M65 x 1, 17 to 31 mm | 1 | [RafCamera EU](https://raf.camera/products/m65x1-focusing-helicoid-with-17-31mm-extension-range) · [AliExpress](https://it.aliexpress.com/item/1005007466119142.html) | [AliExpress](https://it.aliexpress.com/item/1005007466119142.html): m65-m65 17-31 | 70.80 EUR / 39.29 EUR | on AliExpress pick "m65-m65 17-31". No listing states whether the front rotates: check it on arrival |
| Lens board | Linhof Technika 99 x 96, flat, Copal 0 hole (35 mm) | 1 | [Ausgeknipst](https://ausgeknipst.de/en/products/graflex-4x5-lens-board-for-copal-00-0-1-2-3-compur-models-copy) | [AliExpress](https://it.aliexpress.com/item/1005004990862138.html): Copal #0 | 24.95 EUR | pick "Copal #0 35 mm"; often comes with the lens |
| Film back (example) | Mamiya RB67 Pro-S 120, 6x7 | 1 | [Kamerastore](https://kamerastore.com/en-eu/products/mamiya-120-6x7-pro-s-roll-film-holder-mamiya-rb67-t127062) | | 329 EUR (restored) | much cheaper unrestored on eBay |
| or (example) | Mamiya RB67 Pro 120 (no interlocks) | 1 | [Kamerastore](https://kamerastore.com/en-eu/products/mamiya-120-6x7-pro-roll-film-holder-mamiya-rb67-t128950) | | 249 EUR (restored) | |
| Ground glass | Mercury Works Graflok 23 6x9, RS-0 | 1 | [Mercury Works](https://mercuryworks.store/products/graflok-23-6x9-ground-glass-back) | | 75 USD | sold out on the day of checking |
| Lens (example) | Schneider Super-Angulon 65/8, Copal/Compur 0 | 1 | [Kamerastore](https://kamerastore.com/en-eu/products/schneider-kreuznach-65mm-f8-super-angulon-technika-shutter-large-format-t151355) | | 262 EUR | cheapest; dim ground glass at f/8 |
| or (example) | Nikon Nikkor-SW 65/4, Copal 0 | 1 | [eBay](https://www.ebay.it/itm/287544040830) | | 449.99 USD | two stops brighter |
| or (example) | Rodenstock Grandagon-N 65/4.5 | 1 | [eBay](https://www.ebay.it/itm/820154272059) | | 399 EUR | two stops brighter |

The ground glass is sold out at Mercury at the time of writing. Any Graflok 23 ground glass back should fit the same way; check it with the test print ([calibration, section 1](calibration.md#1-before-printing-the-body-test-prints)).

## Filament and consumables

| Item | Spec | Qty | Link | AliExpress | Price seen | Notes |
|---|---|---|---|---|---|---|
| Filament | Bambu Lab ASA, 1 kg: black, plus red and white | 1 or 2 black, small amounts of red and white | [Bambu Lab EU](https://eu.store.bambulab.com/products/asa-filament) | | 24.99 EUR each | about 830 g black plus 120 g of tests; a few grams of red and white |
| Threadlocker | Loctite 243, medium, 10 ml | 1 | [Amazon.it](https://www.amazon.it/dp/B0D8L2RR6S) | buy locally: fakes are common | 15.15 EUR | the two nuts that end the rods; metal to metal only: anaerobic threadlockers can crack ASA |
| Epoxy | UHU Plus Endfest 300, 2 parts | 1 | [Amazon.it](https://www.amazon.it/dp/B000KJP0QK) | buy locally | 10.90 EUR | bonds the shift nut turret, the level and the wheel screw; seals the rise and shift plungers |
| Threadlocker, low strength | Loctite 222 | 1 | [Amazon.it](https://www.amazon.it/dp/B00AGG6Y30) | buy locally: fakes are common | 10 ml | helicoid into the flange, Graflok blade guide screws (into brass inserts), the infinity stop pin |

## Cost

| Group | About |
|---|---|
| Drive: rod, nuts, bushings, plungers, O-rings, spring, PTFE lubricant | 80 EUR |
| Inserts and screws | 45 EUR |
| Arca plate, level, velvet, felt | 45 EUR |
| Metal flange and helicoid (AliExpress helicoid) | 70 EUR |
| Lens board | 25 EUR |
| ASA (black; red and white optional) | 25 to 75 EUR |
| Threadlockers and epoxy | 35 EUR |
| **Camera without back, ground glass and lens** | **about 350 EUR** |

Much of it is packs of screws, inserts and nuts that will outlast the camera: what the camera itself consumes is closer to 170 EUR. The back, the ground glass and the lens are extra: 150 to 350 EUR for a back, 75 USD for the ground glass, 260 to 450 EUR for a lens.

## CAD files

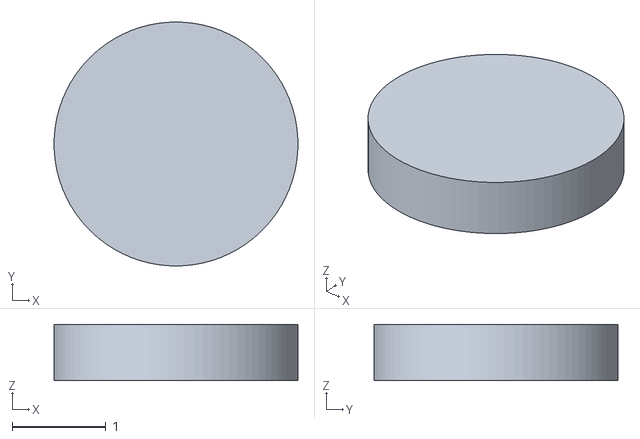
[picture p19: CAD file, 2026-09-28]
print/inlays/rotator__red.stl
2.60 x 2.60 x 0.6

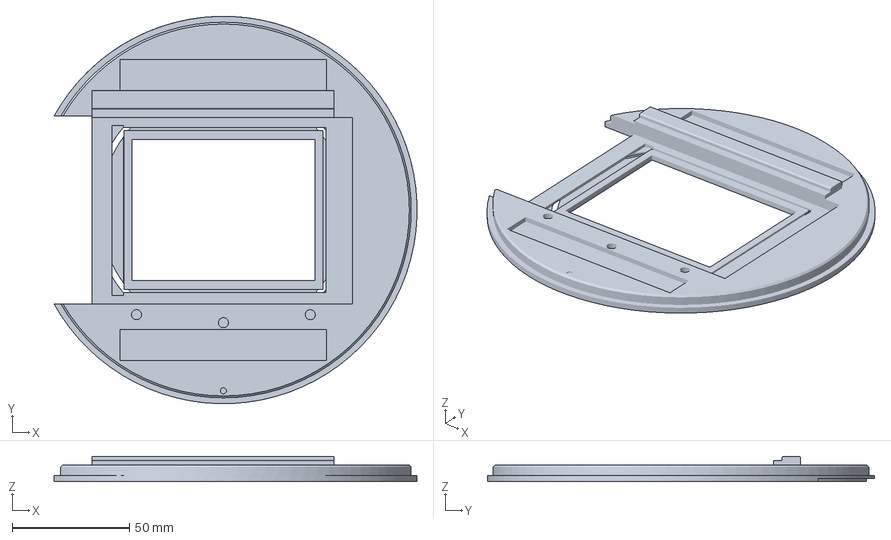
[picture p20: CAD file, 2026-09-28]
print/plates/plate_05_black.3mf
154.6 x 165.0 x 10.8 mm

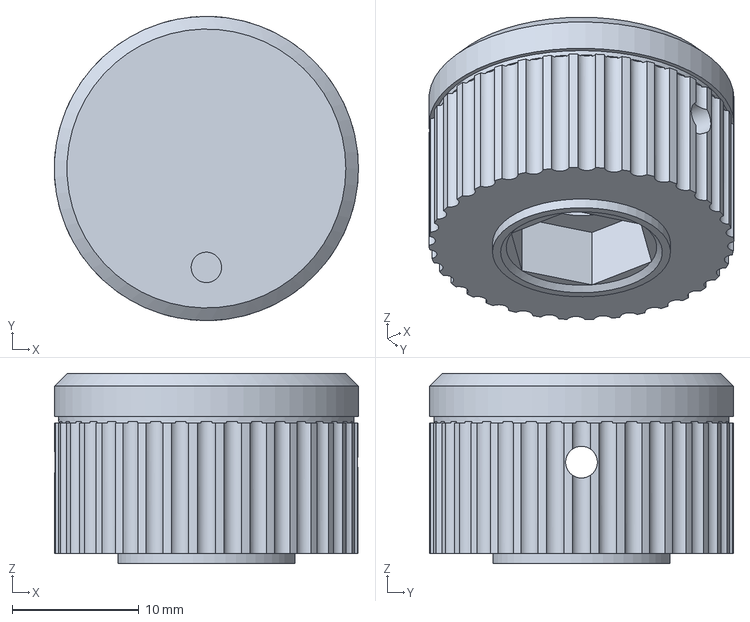
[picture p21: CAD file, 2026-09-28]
print/step/knob.step
24.0 x 24.0 x 15.0 mm

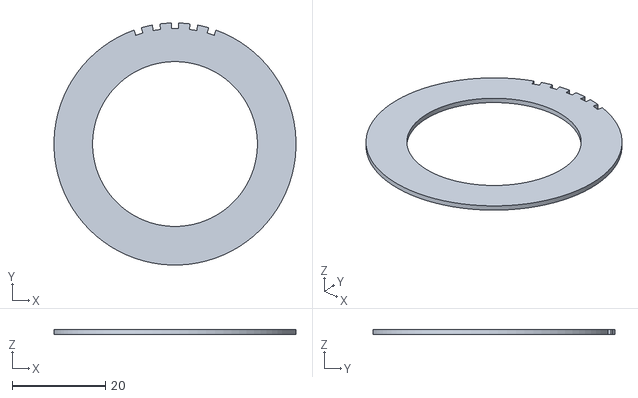
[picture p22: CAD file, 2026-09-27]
print/stl/copal0_shim_1.0mm.stl
52.0 x 52.0 x 1.00

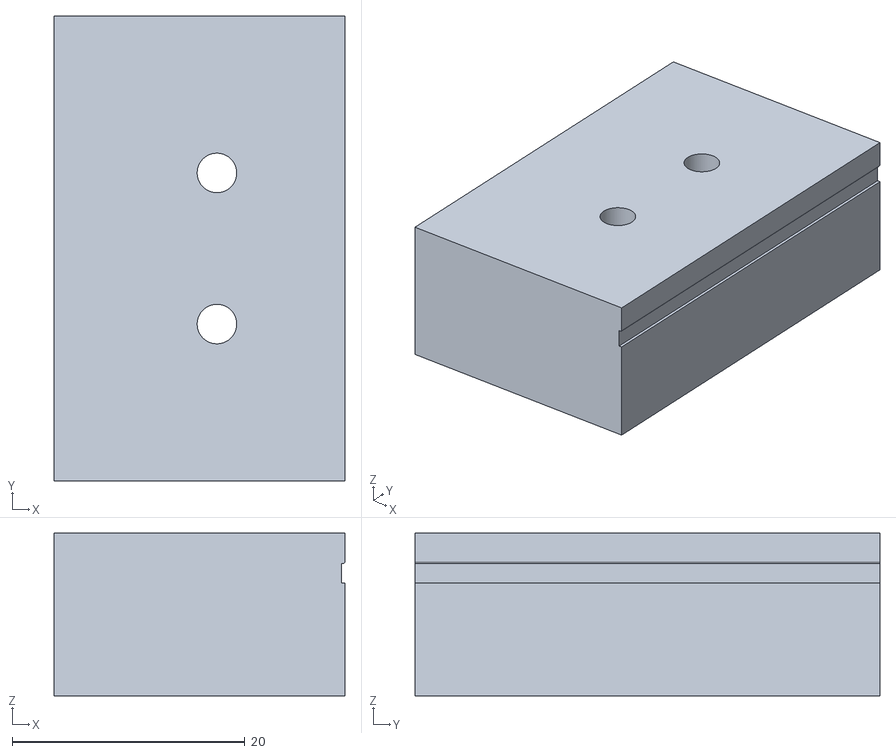
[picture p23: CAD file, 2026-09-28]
print/test/coupon_lip_y_left.stl
25.0 x 40.0 x 14.0

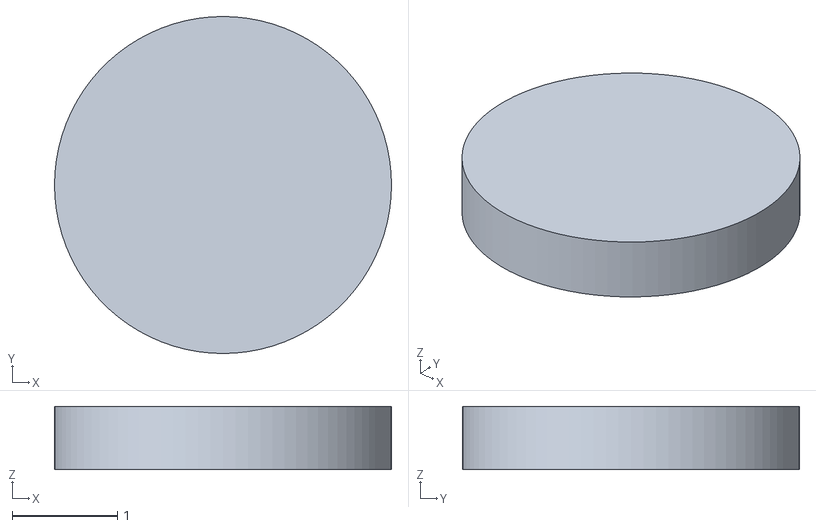
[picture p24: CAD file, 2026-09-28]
print/inlays/top_handle__red.stl
3.20 x 3.20 x 0.6

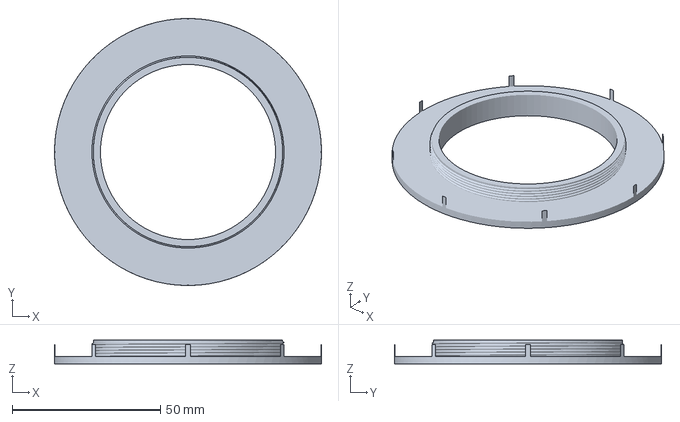
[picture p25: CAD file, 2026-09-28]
print/plates/plate_00c_test_thread_0.12mm_layers.3mf
90.0 x 90.0 x 8.00 mm

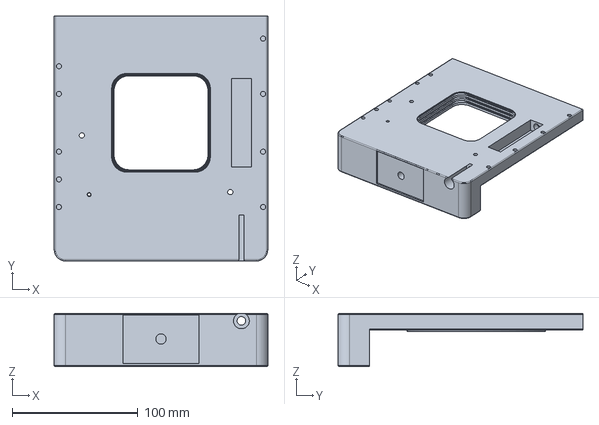
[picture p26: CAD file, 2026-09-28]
print/step/body.step
170.0 x 195.0 x 42.5 mm

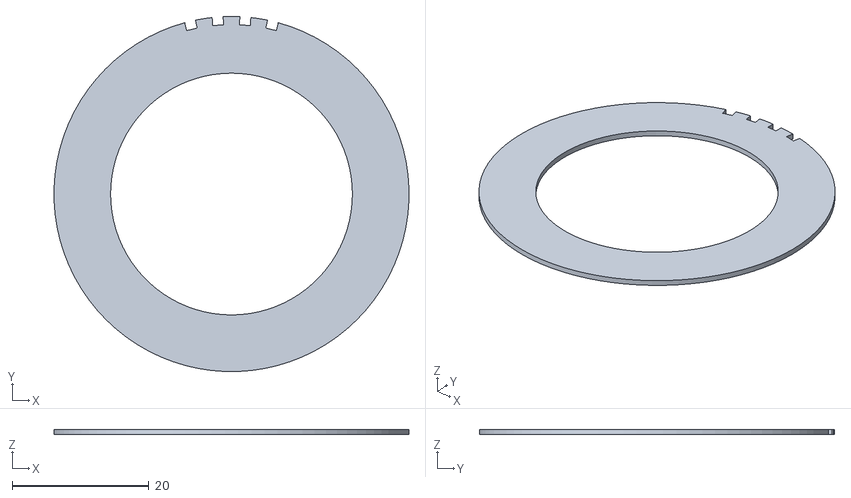
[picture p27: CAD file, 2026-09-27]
print/stl/copal0_shim_0.8mm.stl
52.0 x 52.0 x 0.8

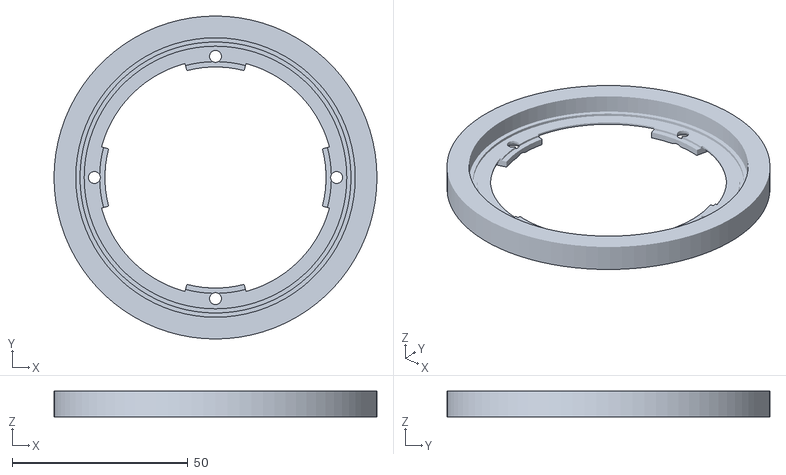
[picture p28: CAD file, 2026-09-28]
print/test/flange_pocket_coupon.stl
92.0 x 92.0 x 7.40

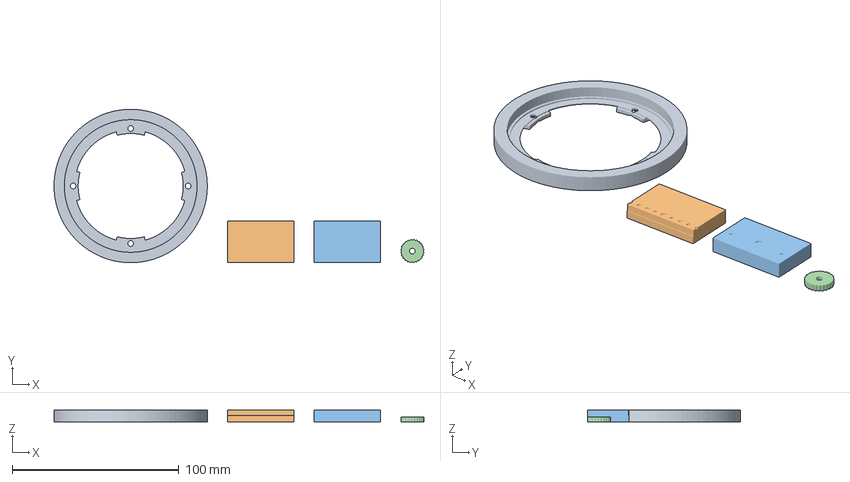
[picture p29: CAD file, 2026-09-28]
print/plates/plate_00b_test_2.3mf
221.9 x 92.0 x 7.40 mm
flange_pocket_coupon
coupon_lip_x_bottom
coupon_lip_x_top
graflok_wheel

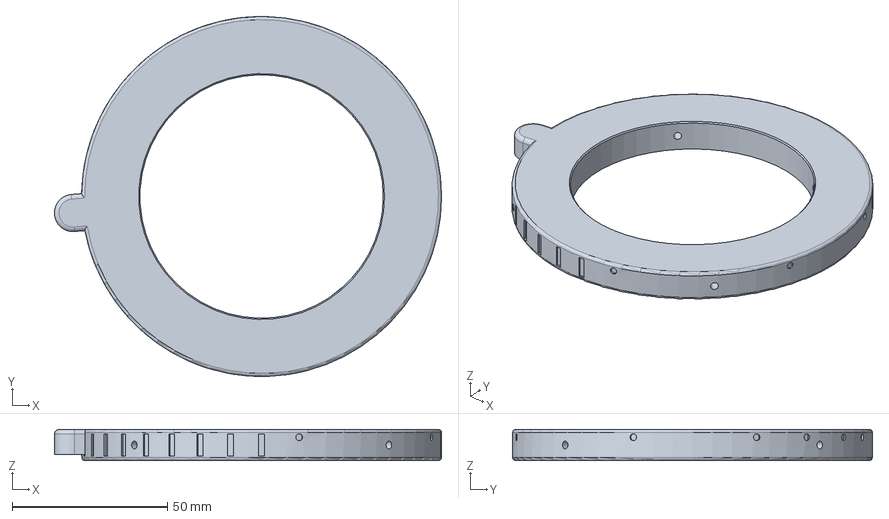
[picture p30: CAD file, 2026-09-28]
print/step/focus_ring.step
124.8 x 116.0 x 10.0 mm

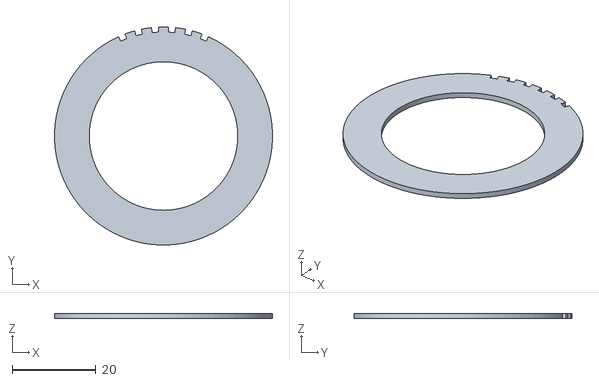
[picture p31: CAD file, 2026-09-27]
print/stl/copal0_shim_1.2mm.stl
52.0 x 52.0 x 1.20

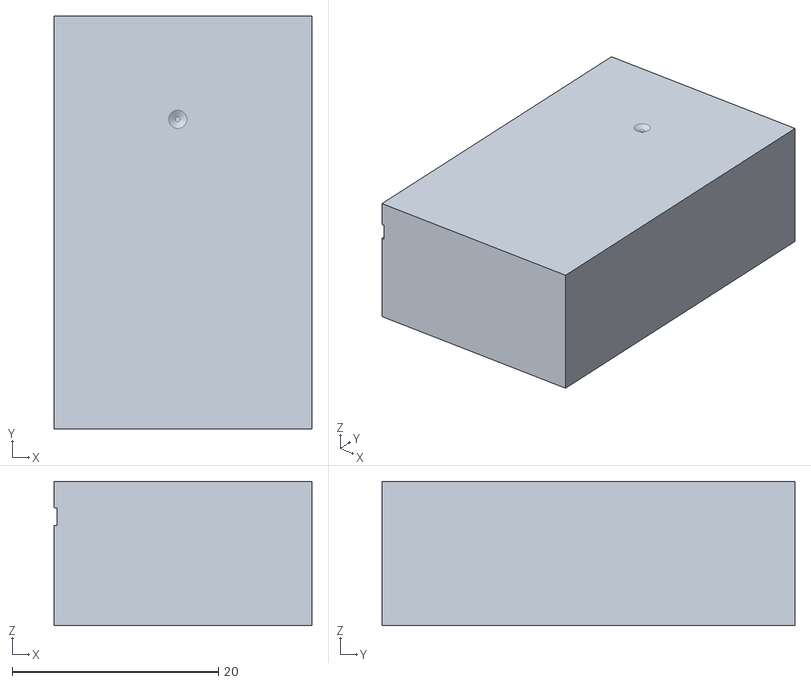
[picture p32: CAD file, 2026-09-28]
print/test/coupon_lip_y_right.stl
25.0 x 40.0 x 14.0

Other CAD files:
print/inlays/way_x_fixed__red.stl
print/inlays/x_plate__white.stl
print/plates/plate_06_black.3mf
print/step/way_y_gib.step
print/inlays/bezel__white.stl
print/inlays/knob__red.stl
print/inlays/x_plate__red.stl
print/plates/plate_00a_shrink_gauge.3mf
print/plates/plate_00b_test_1.3mf
print/plates/plate_01_black.3mf
print/plates/plate_02_black.3mf
print/plates/plate_03_black.3mf
print/plates/plate_04_black.3mf
print/plates/plate_07_black_0.12mm_layers.3mf
print/plates/plate_07_shims_0.2mm_layers.3mf
print/plates/plate_red_1.3mf
print/step/adapter_ring.step
print/step/bezel.step
print/step/board_holder.step
print/step/gib_x.step
print/step/gib_y.step
print/step/graflok_blade.step
print/step/graflok_wheel.step
print/step/holder_latch.step
print/step/rotator.step
print/step/top_handle.step
print/step/way_x_fixed.step
print/step/way_x_gib.step
print/step/way_y_fixed.step
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

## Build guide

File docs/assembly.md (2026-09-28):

# Assembly

[Back to the project](../README.md)

This guide assumes you have never built anything like it. Each of the nine steps is split into short sub-steps. Every picture shows what is already built in place and only the parts of that sub-step pulled out along the way they go in, with a dashed line to where they go; the red letters match the table under the picture. Follow the steps in order: the order was checked part by part, and some screws cannot be reached later.

Allow a day for the first build: about five hours of work, plus waiting for epoxy and threadlocker to cure.

## Words used in this guide

- **Front** is the lens side, **rear** is the film side.
- **Photographer's left and right** are as you stand behind the camera looking at the ground glass. A picture taken from the front shows them mirrored: the photographer's left is on the right of the picture.
- **Insert** means a brass heat-set insert: a small threaded sleeve melted into the plastic so a metal screw has metal threads to bite. Sizes are written M3 x 3 (thread x length).
- **Proud** means sticking out above a surface; **flush** means level with it.
- The **Y plate** moves up and down (rise and fall). The **lens panel** moves left and right (shift) and carries the lens. Together they are the **front standard**.
- A **dovetail way** is a printed rail with a slanted edge; the plate's slanted edge (its **lip**) slides under it. One rail of each pair is fixed; the other holds a **gib strip**, a thin printed bar pushed by three grub screws to take up the play.

## Before you start

1. **Print and check the parts.** Everything in [printing](printing.md), including the checks under *After printing*.
2. **Do the tests first.** Section 1 of [calibration](calibration.md) tells you whether your RB67 back fits and whether the dovetails slide, before you spend a day assembling.
3. **Sort the hardware.** Put a strip of masking tape on the table and lay out the screws by size. Every step starts with a *You need* list.
4. **Clean the holes.** Pull out any stringing with a hook or a drill turned by hand.

### Tools

| Tool | Used for |
|---|---|
| Soldering iron with heat-set tips for M3 and 1/4" | inserts |
| Hex keys 1.5, 2 and 2.5 mm, one of them long (at least 30 mm of shaft) | grub screws, countersunk and socket-head M3 screws |
| M3 and M5 taps with a small tap wrench | threads cut into the plastic |
| 8 mm drill bit (turned by hand) | reaming the bushing seats |
| 10 mm spanner | the M6 nuts |
| A small vice or a clamp, a flat piece of wood | pressing bushings and nuts |
| Steel ruler or straightedge, caliper | flatness and heights |
| Feeler gauge 1.0 mm (or ten sheets of 80 g printer paper) | ball plunger height |
| Sharp scissors, a new craft blade | velvet and felt |
| Loctite 243 and 222, two-part epoxy, isopropyl alcohol, cotton buds, black acrylic paint | as listed in the steps |

### Five techniques you will use

**1. Heat-set inserts.** This is most of the work, so practise on a test coupon first.

1. Set the iron to 230 C (ASA). Put the right tip on and let it heat for a minute.
2. Drop the insert into the hole with its **narrow end down**. It sits on the rim of the hole.
3. Put the tip into the insert and let it sink under its own weight plus a light push, straight down, for 5 to 10 seconds. Do not force it: if it does not move, wait.
4. Stop when the insert is 0.2 mm below the surface. Pull the tip straight out.
5. While the plastic is still soft, press a cold flat steel part (the side of a spanner) on the insert for five seconds: it comes out square and never proud.
6. Check: lay the straightedge across the hole. It must rock on nothing. An insert standing proud of a sliding face or of the back's seat leaks light or tilts the back.

Every insert in the camera is the same M3 x 3 x 5, 29 of them, plus one of 1/4" for the Arca plate. The 1/4" ones take 15 to 20 seconds: go slowly and keep the iron vertical.

**2. Tapping a thread into the plastic.** Used for the three ball plungers (M5) and for every M3 hole without an insert: the grub holes, the stop of the rotating back, the eight holes in the base of the horizontal rails and the two latch holes of the board holder. The holes are printed at the right size.

1. Put the tap in the wrench and start it straight, looking from two sides.
2. Turn half a turn in, a quarter turn back, and repeat. The plastic chips must break off.
3. Go only as deep as the hole. Blow the chips out.

**3. Pressing.** Bushings and the knob nuts are press fits. Use the vice or a clamp, never a hammer: ASA cracks. Put a flat piece of wood on the printed side.

**4. Threadlocker.** Anaerobic threadlockers attack ASA and can crack it. Use them only where metal meets metal: Loctite 243 on the two nuts that end the rods (steel on steel), Loctite 222 on the helicoid thread and on the Graflok blade screws (steel into brass inserts). One small drop, never on the plastic.

**5. Velvet and felt.** The camera has no bellows: light is kept out by sliding faces 0.8 mm apart with self-adhesive velvet between them. The pieces are V1, V2 (with two small discs), the ring V5 of the rotating back, and the felt rings V3 and V4.

1. Print the templates in `print/templates/` at 100 %. Measure the 100 mm bar on the sheet: if it is not 100 mm, fix the printer scaling first.
2. Tape the template on the back of the velvet (the paper side), and cut through both with scissors for the outer edge and a craft blade against a ruler for the window.
3. Measure the velvet thickness with the caliper, pressing lightly: it must be 0.9 to 1.2 mm.
4. Degrease the plastic with alcohol. Peel off the backing, align one edge, and lay the velvet down from that edge like a screen protector. Press it all over with your thumb.
5. The velvet must never cover a ball plunger, a rail, or a hole a screw still has to reach (except where this guide says so).

---

## 1. Body

**You need:** the body, 15 M3 inserts, one 1/4"-20 insert, one M5 ball plunger, two 6 x 8 x 6 bushings, the M3 and M5 taps, epoxy.

### 1a. Inserts in the rear face

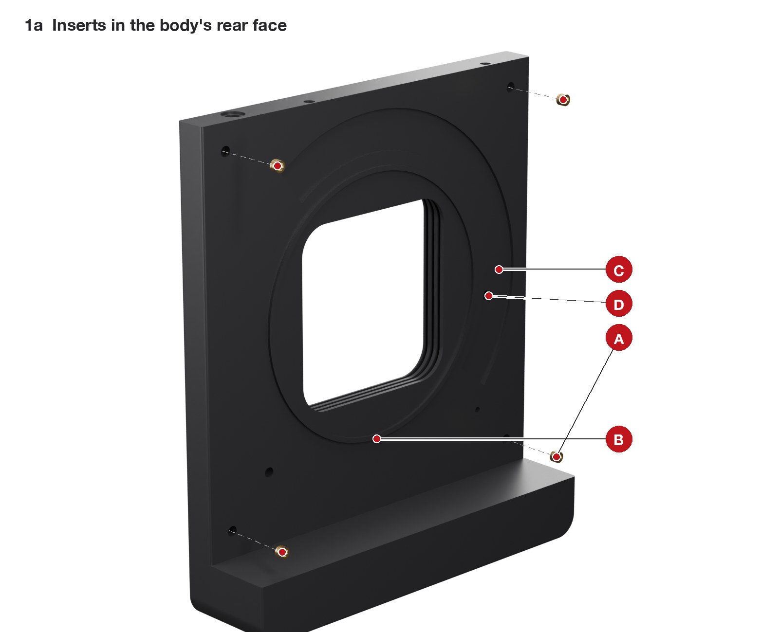
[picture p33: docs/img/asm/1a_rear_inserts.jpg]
1a


| | What | Qty | How |
|---|---|---|---|
| **A** | M3 x 3 insert | 4 | in the four corners of the rear face, for the rear frame |
| **B** | nothing | | the round ridge of the light trap: the rotator's groove runs over it. Keep it clean and sharp |
| **C** | nothing | | the curved pocket on the photographer's right: the dark-slide handle and the back's hooks turn in it |
| **D** | the back of the rise plunger | | you set its height from here in 1c |

Lay the body front face down on a towel and press the four inserts A. Check with the straightedge: the rear face is the reference for the film plane, so no insert may stand proud.

### 1b. Inserts along the front edges

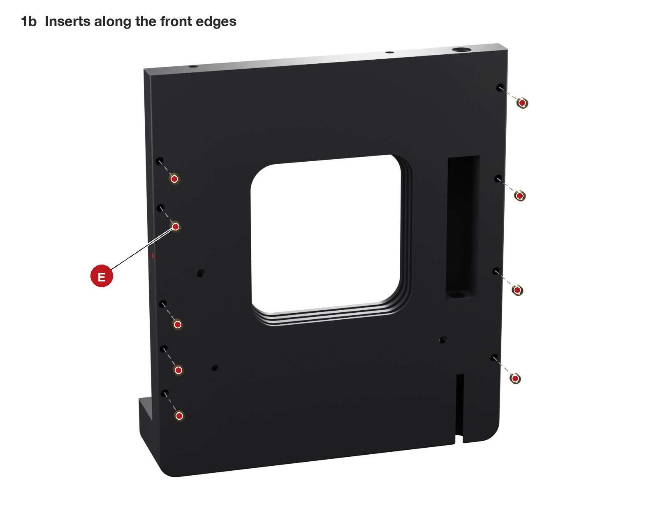
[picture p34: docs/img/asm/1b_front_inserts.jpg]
1b


| | What | Qty | How |
|---|---|---|---|
| **E** | M3 insert | 9 | along the two side edges of the front face: 5 on the photographer's right (left in the picture), 4 on the left |

Turn the body over and press the nine inserts E. They carry the vertical rails in step 4.

### 1c. Rise plunger and bushings

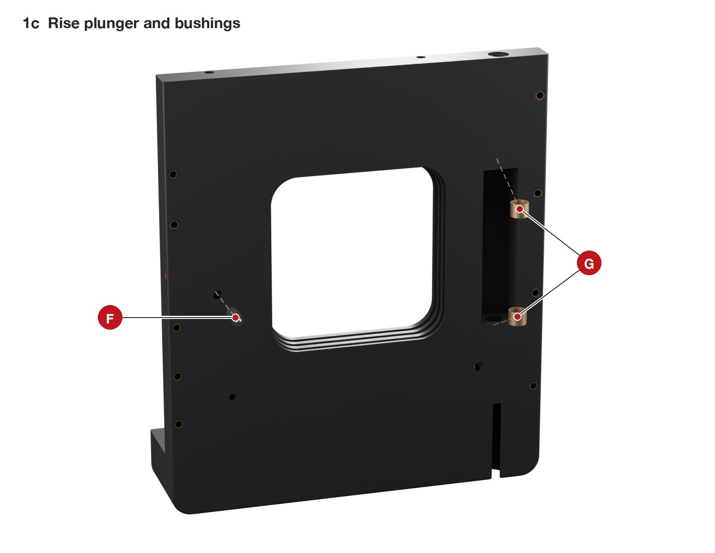
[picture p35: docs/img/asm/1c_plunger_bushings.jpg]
1c


| | What | Qty | How |
|---|---|---|---|
| **F** | M5 ball plunger (POM ball) | 1 | tap M5 through, screw in from the front, set from behind (D) |
| **G** | bronze bushing 6 x 8 x 6 | 2 | one in each end wall of the screw channel |

1. **F.** Tap M5 through the small hole beside the window. Screw the plunger in from the front, ball toward you, until its hex is inside. From behind (D), turn it with a hex key until the ball stands **1.0 mm** proud of the front face: lay the feeler gauge on the face next to it and a ruler across both, and stop when the ball touches the ruler. A small drop of epoxy on the thread at the back, scraped flush with the floor of the curved pocket C (the back's hooks sweep over it), locks the plunger and seals the hole.
2. **G.** Ream the two bushing seats with the 8 mm drill turned by hand. Drop a bushing into the screw channel and push it sideways into the round seat in the end wall until it is flush; a 6 mm bolt through its bore keeps it square. Do the other one the same way.
3. **For step 2.** Near the bottom corners of the front face are two more holes that go through to the rear: tap M5 through the one on the photographer's left (right as you look at the front), and M3 into the narrow rear end of the one on the photographer's right, reaching through its wide bore. They take the click and the stop of the rotating back in 2d; the rotator will cover their rear ends.

### 1d. Handle inserts on top

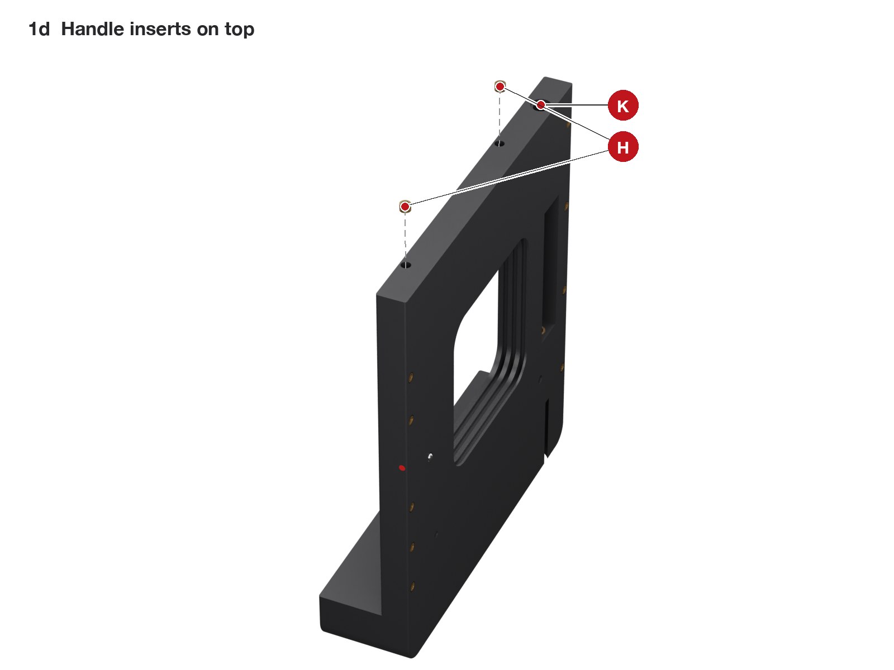
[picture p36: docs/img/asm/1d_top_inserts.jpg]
1d


| | What | Qty | How |
|---|---|---|---|
| **H** | M3 insert | 2 | in the top face, for the top handle |
| **K** | nothing yet | | the rise rod comes out here (6f) |

### 1e. Tripod insert underneath

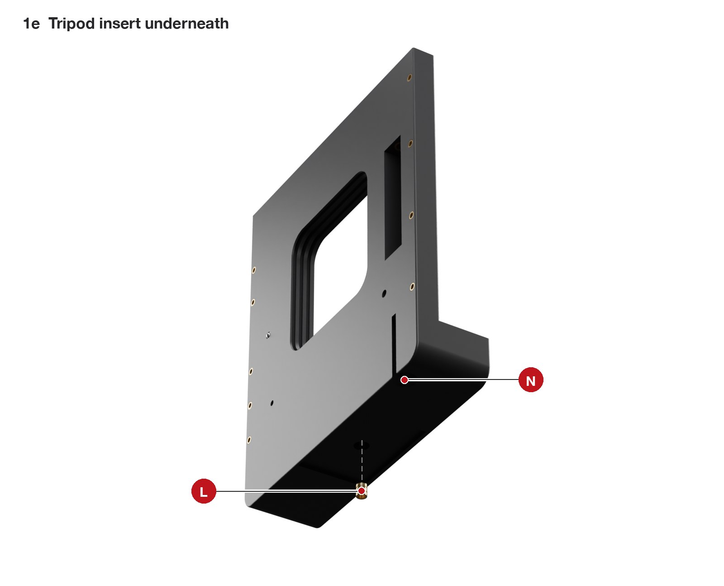
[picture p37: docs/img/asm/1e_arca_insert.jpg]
1e


| | What | Qty | How |
|---|---|---|---|
| **L** | 1/4"-20 insert | 1 | in the middle of the Arca pocket |
| **N** | nothing yet | | the recess of the rise rod's end nut (6b) |

The 1/4" insert takes 15 to 20 seconds: go slowly and keep the iron vertical.

**Check.** No insert is proud on any face. Press the plunger ball with a fingertip: it springs back.

## 2. Rotating back and rear frame

The film back does not sit on the body: it sits on the **rotator**, a round plate that turns a quarter turn in the body's rear face. For vertical pictures you turn the back, not the camera, and the tripod, the handle and the level stay where they are. A **rear frame** screwed to the body holds the rotator's flange over a ring of velvet; a ball plunger clicks at the two positions and a grub screw stops it past them.

**You need:** the rotator, the blade, the wheel, the rear frame, 3 M3 inserts, 4 M3 x 10 socket heads, 2 M3 x 6 countersunk, 1 M3 x 8 countersunk, 1 M3 x 6 grub, one M5 ball plunger, velvet ring V5, a long hex key, Loctite 222, epoxy, dry PTFE.

If the rotator from the test plate fitted your back, use that one.

### 2a. Inserts in the rotator

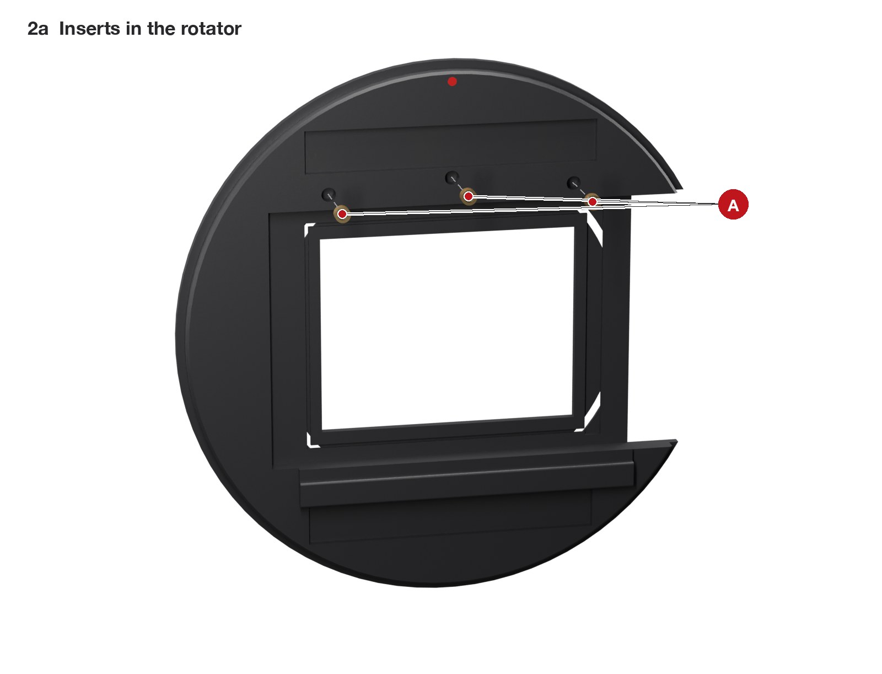
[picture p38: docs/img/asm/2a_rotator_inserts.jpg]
2a


| | What | Qty | How |
|---|---|---|---|
| **A** | M3 x 3 insert | 3 | in the shallow recess along the top of the rear face: two for the blade, the middle one for the wheel |

### 2b. Blade and wheel on the rotator

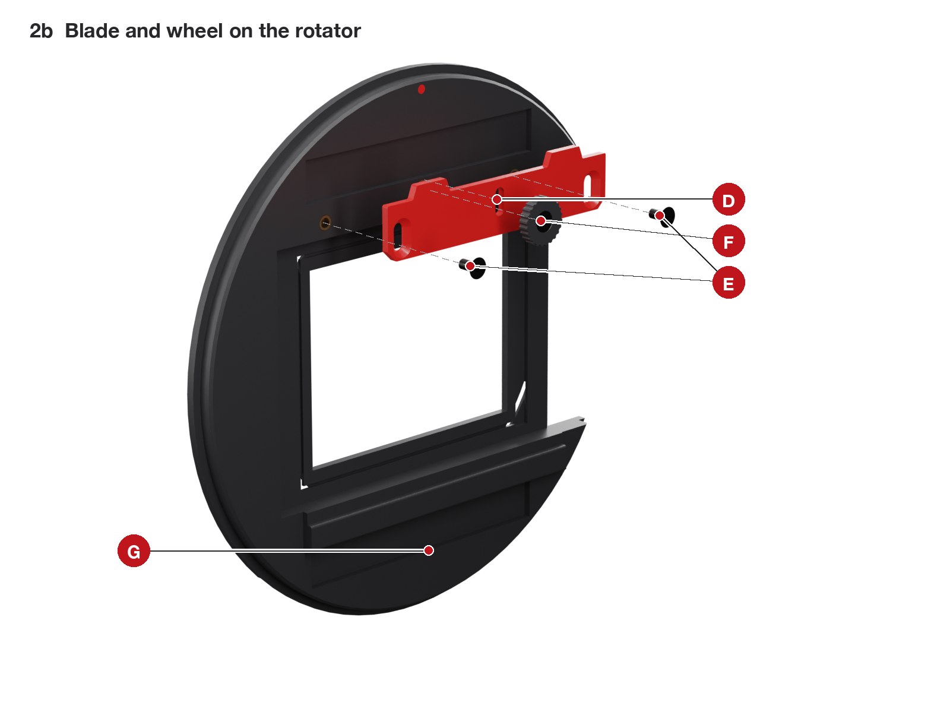
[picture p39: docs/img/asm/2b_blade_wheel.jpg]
2b


| | What | Qty | How |
|---|---|---|---|
| **D** | the red blade | 1 | in the recess, tongues pointing up |
| **E** | M3 x 6 countersunk | 2 | through the blade slots into the outer inserts, with Loctite 222 |
| **F** | wheel with an M3 x 8 countersunk | 1 | into the middle insert |
| **G** | nothing | | the fixed bottom rail: the back hooks under it |

1. **D and E.** Lay the blade in the recess. Put a small drop of Loctite 222 on the two screws E, screw them through the blade slots until they just touch, then back them off a quarter turn: the blade must slide up and down under its own weight. Leave the threadlocker to set for an hour: the screws then stay where they are.
2. **F.** Put a drop of epoxy in the cone at the back of the wheel and press the screw head into it, so the screw turns with the wheel. Once it has set, put the wheel over the U-slot of the blade and screw it in. Clockwise clamps the blade; anticlockwise frees it.

**Check.** With the wheel loose, the blade slides the full length of its slots. With the wheel tight, it does not move.

### 2c. Rotator, velvet ring and rear frame

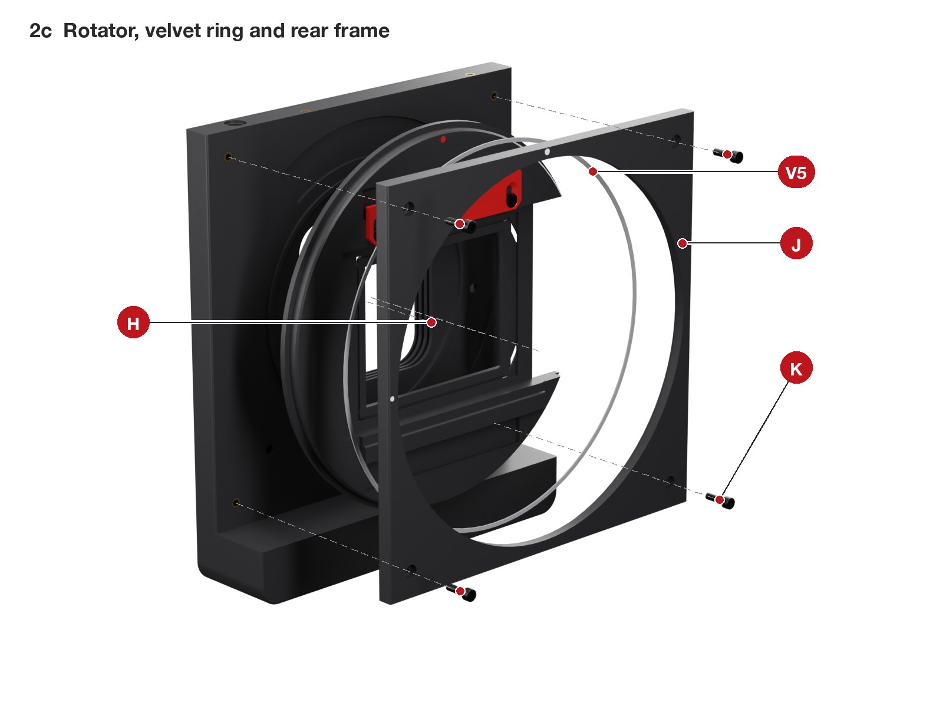
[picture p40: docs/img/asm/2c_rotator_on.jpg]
2c


| | What | Qty | How |
|---|---|---|---|
| **H** | the rotator | 1 | into the round seat in the body's rear face, red dot at the top |
| **V5** | velvet ring | 1 | on the floor of the step inside the rear frame |
| **J** | the rear frame | 1 | over the rotator's flange, the big white dot at the top |
| **K** | M3 x 10 socket head | 4 | through the frame's corners into the inserts A of 1a |

1. **H.** Lay the body front face down. Wipe a thin film of dry PTFE on the ring of the rear face and on the rotator's front face. Put the rotator in with its red dot at the top: the groove on its front face drops over the ridge B, and it turns freely.
2. **V5.** Cut the ring with `print/templates/V5_velvet_rotator_ring.svg` and stick it on the floor of the step inside the frame, velvet up.
3. **J and K.** Lay the frame over the rotator, its white dots on the photographer's left and at the top, and screw it down with the four screws K, a little at a time in a cross, until the heads sit in their counterbores.

**Check.** The rotator turns with an even, velvety drag and has no play front to back. If it binds, the velvet is too thick: peel V5 and use a thinner one.

### 2d. Click and stop, from the front

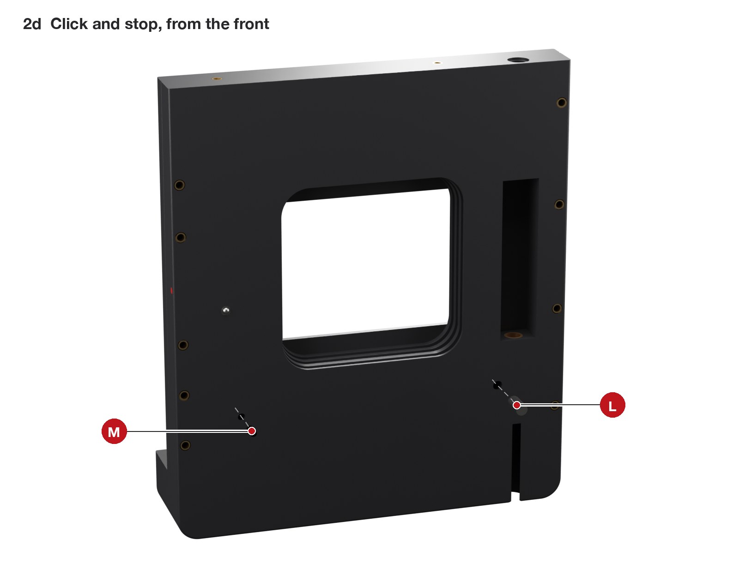
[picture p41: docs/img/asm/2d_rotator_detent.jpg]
2d


| | What | Qty | How |
|---|---|---|---|
| **L** | M5 ball plunger (POM ball) | 1 | in the hole at the bottom on the photographer's left (right in the picture) |
| **M** | M3 x 6 grub | 1 | in the hole at the bottom on the photographer's right (left in the picture) |

Stand the body on its bottom, front toward you. Both holes go through to the rotator.

1. **L.** Screw the plunger into its hole (tapped in 1c) from the front, ball first, with the rotator at landscape (red dot at the top). When the ball touches the rotator, give it half a turn more. Turn the rotator: it clicks into place at landscape and at portrait. Firmer click: a quarter turn more; lighter: a quarter turn back.
2. **M.** Drive the grub from the front with the long hex key until it touches the bottom of the groove in the rotator, then back it half a turn.

**Check.** Seen from behind, the back turns a quarter turn anticlockwise from landscape (red dot on the big white dot at the top) to portrait (red dot on the small white dot on the photographer's left), clicks at both, and stops hard just past each. The dark slide then comes out at the top.

## 3. Arca plate, top handle and level

**You need:** the Arca plate, one screw 1/4"-20 x 1/2" (plates often come with one), the top handle, 2 M3 x 20 socket heads, one 15 mm bull's-eye level, epoxy.

### 3a. Arca plate

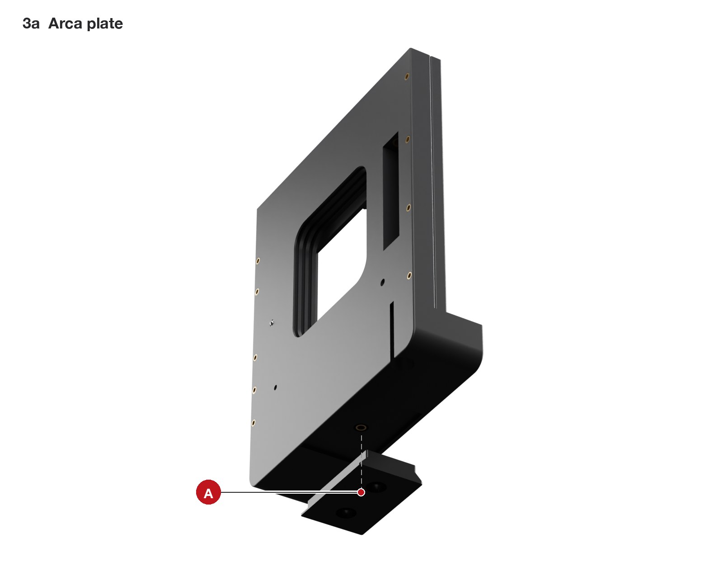
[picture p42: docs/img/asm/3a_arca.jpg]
3a


| | What | Qty | How |
|---|---|---|---|
| **A** | Arca plate | 1 | one 1/4"-20 x 1/2" screw into the insert L |

Remove any rubber pad from the plate. The pocket keeps it from turning, so one screw is enough. The camera always sits on this plate: for vertical pictures you turn the back (step 2), not the camera.

### 3b. Top handle

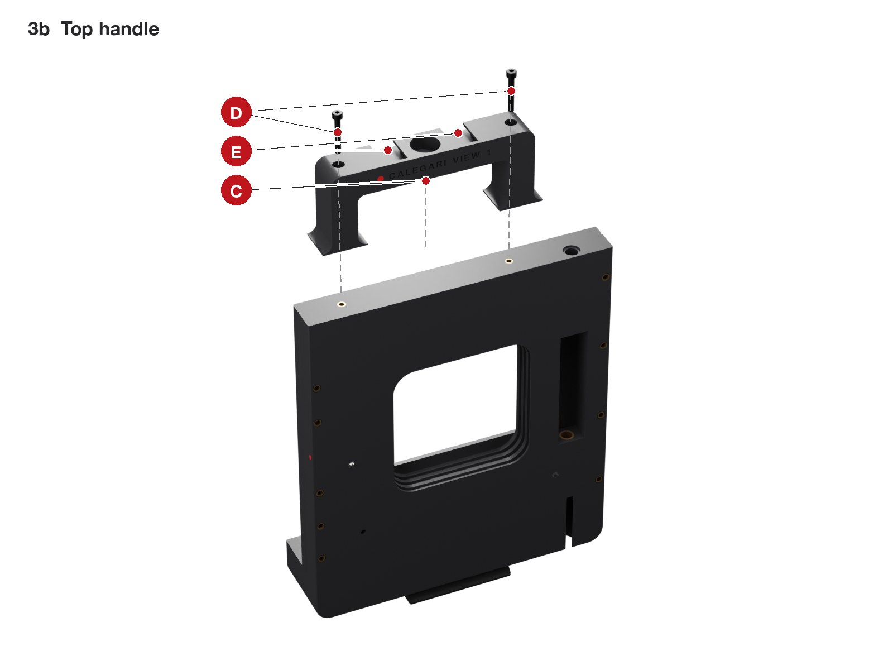
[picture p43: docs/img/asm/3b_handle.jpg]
3b


| | What | Qty | How |
|---|---|---|---|
| **C** | top handle | 1 | its two feet on the top face, over the inserts H |
| **D** | M3 x 20 socket head | 2 | down the long hole in each post, into H: use the long hex key |
| **E** | nothing | | two accessory shoes: slide a viewfinder, a meter or a level in from the back |

Tighten firmly: this handle carries the camera. A strap attaches to the bar between the posts (Peak Design Anchors, or any cord).

### 3c. The level

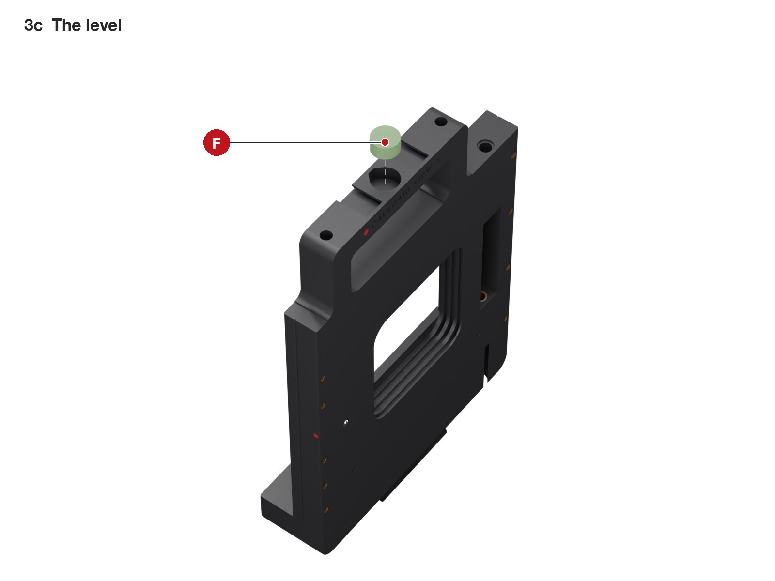
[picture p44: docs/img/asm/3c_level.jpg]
3c


| | What | Qty | How |
|---|---|---|---|
| **F** | 15 mm bull's-eye level | 1 | glued in the pocket on top of the handle |

Put the camera on a tripod on its Arca plate and level it with a phone level laid on top of the body, in both directions. Put a drop of epoxy in the pocket on top of the handle, press the bull's-eye in, and let the glue set without touching the camera. The same level serves both orientations: the camera never turns, the back does.

## 4. Vertical ways and body velvet

**You need:** the two vertical rails (the fixed one is plain; the gib one has three small holes on its outer face and a pocket along its inside), 9 M3 x 8 countersunk, the M3 tap, velvet piece V1.

### 4a. Vertical rails

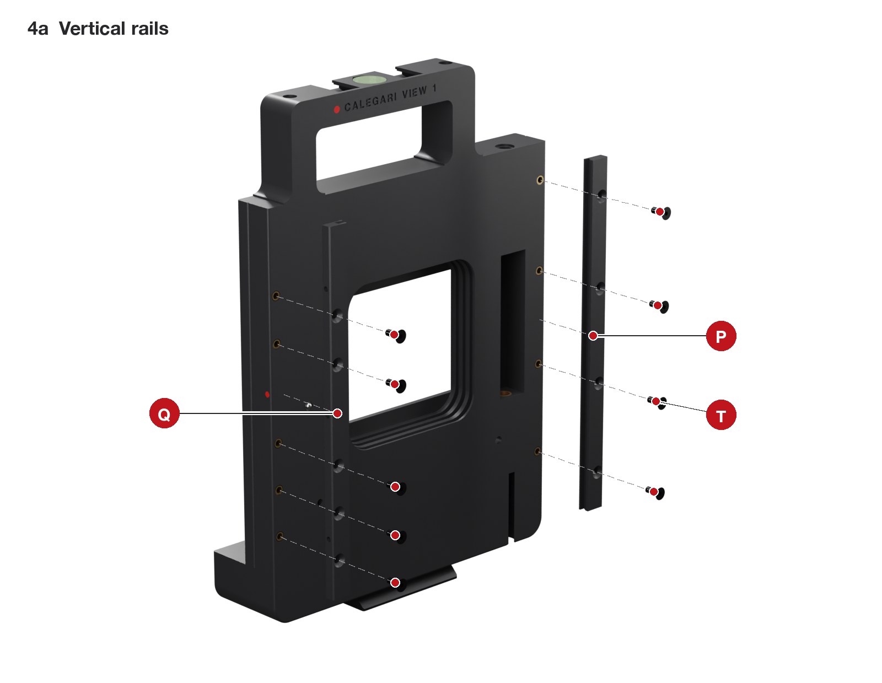
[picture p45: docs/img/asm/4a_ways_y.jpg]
4a


| | What | Qty | How |
|---|---|---|---|
| **P** | fixed rail | 1 | on the photographer's **left** edge (right in the picture), slanted side inward |
| **Q** | gib rail | 1 | on the photographer's **right** edge, its three small holes facing outward |
| **T** | M3 x 8 countersunk | 9 | through the rails into the inserts E: 4 in P, 5 in Q |

Tap M3 into the three small holes of Q first. The rails' round ends go to the top, where the body corner is round.

### 4b. Velvet V1 on the body front

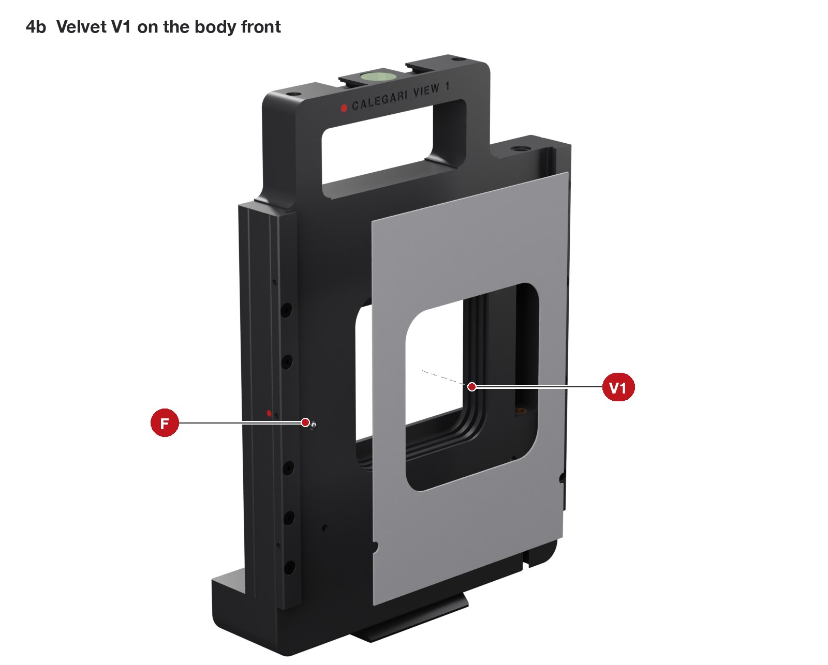
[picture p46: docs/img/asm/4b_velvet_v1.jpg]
4b


| | What | Qty | How |
|---|---|---|---|
| **V1** | velvet, cut from its template | 1 | around the window, between the rails |
| **F** | the plunger ball | | stays uncovered: the side of V1 marked *ball plunger side* goes toward it |
| **L, M** | the click and the stop of the rotating back (2d) | | stay uncovered: the two notches in the bottom corners of V1 go around them |

The velvet window is 0.3 mm larger than the body's window all round.

**Check.** Run a fingernail along the inside of both rails: no step, no burr.

## 5. Front standard, on the bench

**You need:** the Y plate, the lens panel, the two horizontal rails, the X gib strip, the shift nut turret, the metal M65 flange, 1 M3 insert, 1 brass M6 nut, 2 bushings, 1 M5 ball plunger, 4 M3 x 6 countersunk, 8 M3 x 16 socket heads, 4 M3 x 6 grubs (three for the gib, one for the knob), the 138 mm rod, an M6 washer and a stainless M6 nut (the thrust nut), O-ring, knob with its M6 nut, velvet V2, epoxy, Loctite 243, black paint.

The front standard is built as one unit on a clean flat table, then slides into the body in step 6.

### 5a. Y plate: bushings and shift plunger

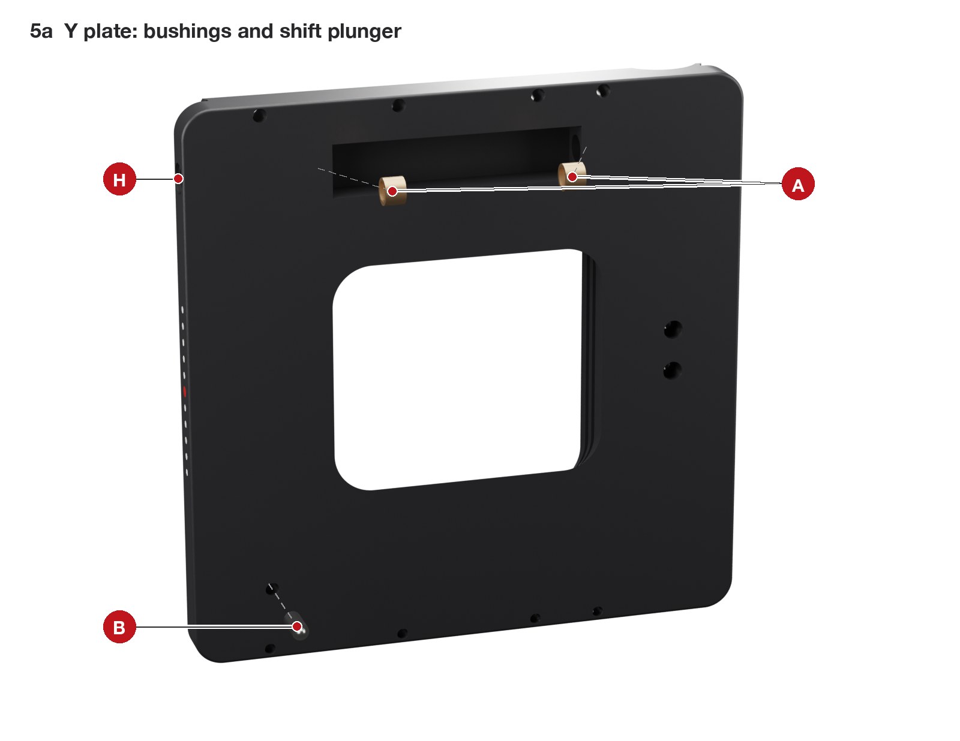
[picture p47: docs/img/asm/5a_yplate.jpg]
5a


| | What | Qty | How |
|---|---|---|---|
| **A** | bronze bushing 6 x 8 x 6 | 2 | one in each end wall of the top screw channel |
| **B** | M5 ball plunger (POM ball) | 1 | tap M5 through, screw in from the front, set from behind (C) |
| **H** | nothing yet | | the shift rod goes in here, and the knob sits here (5k) |

Ream and press the bushings as in 1c. The left seat is blind: nothing of the rod will show on that edge.

### 5b. Y plate from behind

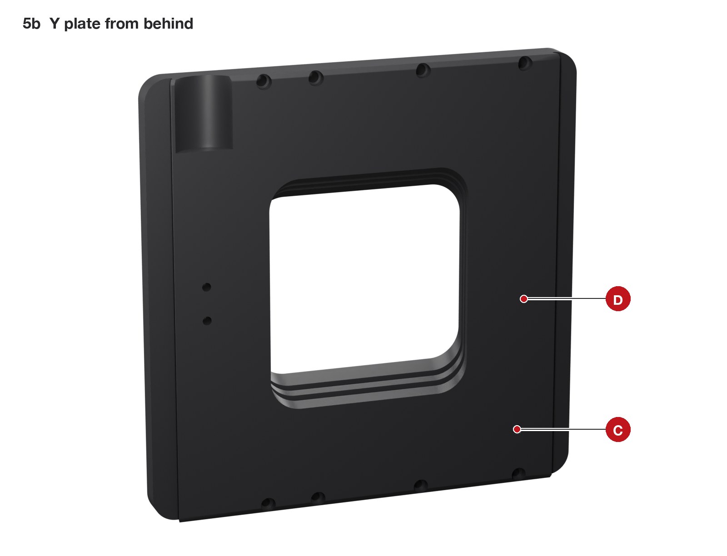
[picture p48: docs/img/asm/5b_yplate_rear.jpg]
5b


| | What | Qty | How |
|---|---|---|---|
| **C** | the back of the shift plunger | | set the ball 1.0 mm proud from here, then a drop of epoxy scraped flush |
| **D** | nothing | | the dimple of the rise detent |

### 5c. Velvet V2 on the Y plate

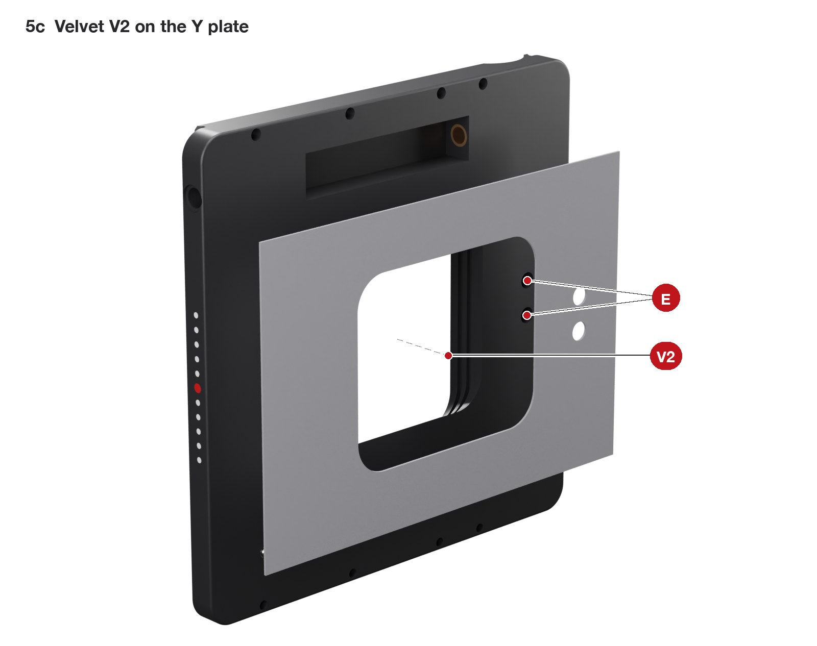
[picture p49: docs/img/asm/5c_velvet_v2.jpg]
5c


| | What | Qty | How |
|---|---|---|---|
| **V2** | velvet, cut from its template | 1 | on the Y plate front around the window |
| **E** | the two holes of V2 | | over the rise-turret screw holes; keep the two 7 mm discs for 6d |

### 5d. Lens panel: flange and stop insert

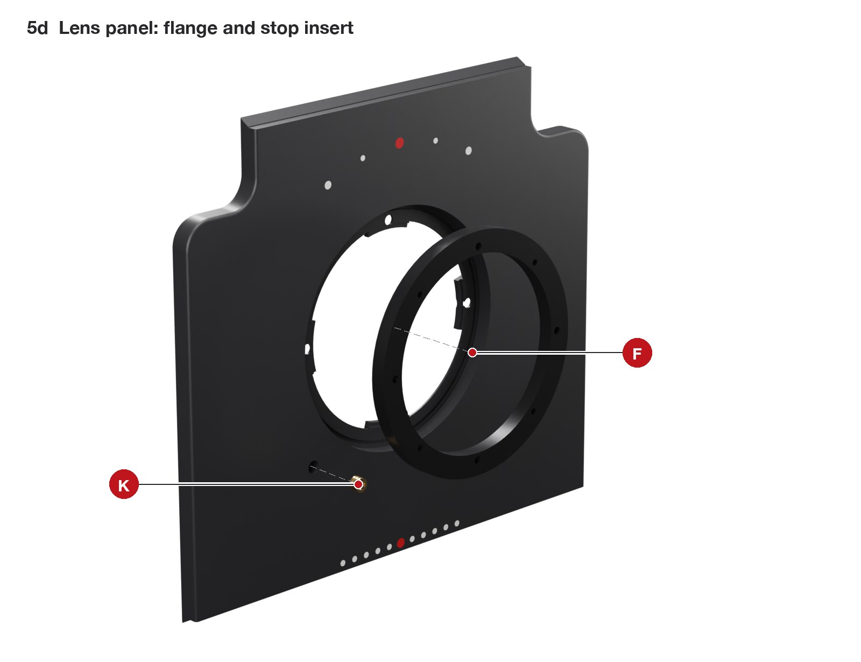
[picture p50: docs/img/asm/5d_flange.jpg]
5d


| | What | Qty | How |
|---|---|---|---|
| **F** | RafCamera M65 flange | 1 | dropped into the round pocket, flush |
| **K** | M3 insert | 1 | the infinity stop pin screws into it in 7a |

Turn the flange until its four threaded M3 holes sit over the four countersunk holes of the panel. Fill the flange's four unused holes with black paint: light would otherwise shine through them.

### 5e. Lens panel from behind: screws and turret

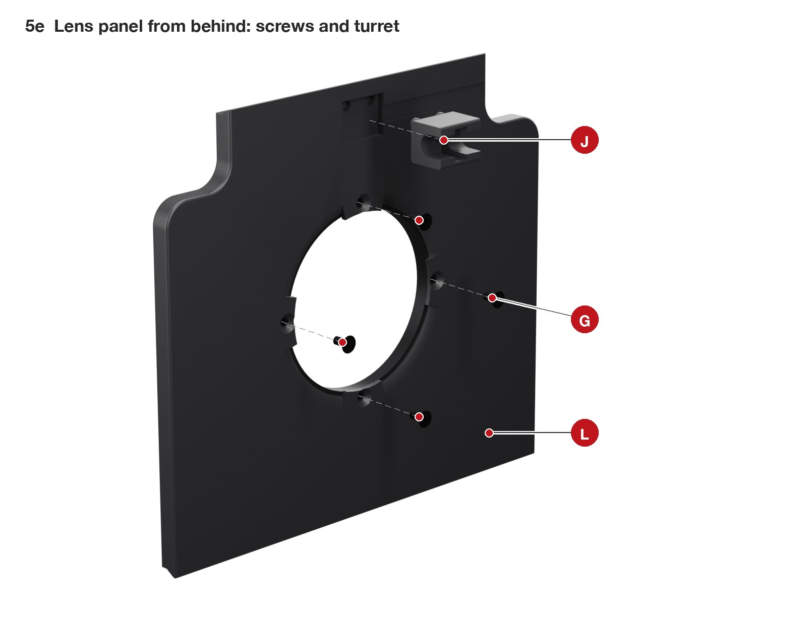
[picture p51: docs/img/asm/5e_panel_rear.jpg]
5e


| | What | Qty | How |
|---|---|---|---|
| **G** | M3 x 6 countersunk | 4 | from behind into the flange's M3 holes |
| **J** | shift nut turret | 1 | bonded with epoxy into its pocket, pegs into their holes |
| **L** | nothing | | the dimple of the shift detent |

Put a thin layer of epoxy on the top of the turret J, press it into its pocket and let it cure. The brass nut does not go in the turret: it goes on the rod in 5g. Look at the small conical dimple L: if the first printed layer closed it, open it with a 2.5 mm drill turned by hand, 0.4 mm deep.

### 5f. Tap the horizontal rails

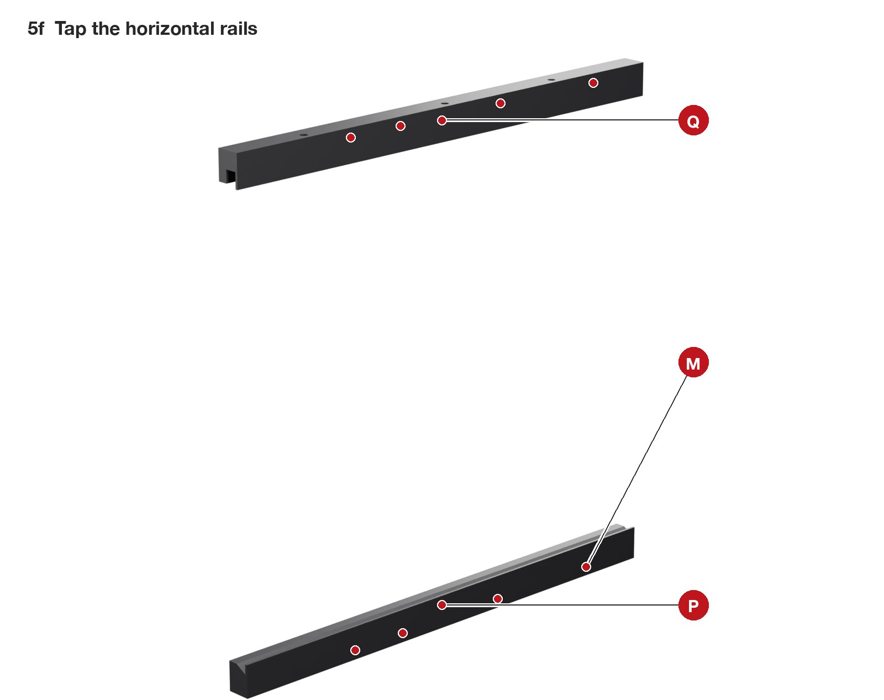
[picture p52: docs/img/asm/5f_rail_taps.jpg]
5f


| | What | Qty | How |
|---|---|---|---|
| **M** | M3 thread | 8 | tap the four holes in the base of each rail by hand, 6 mm deep: the rails are too slim for inserts |
| **P** | fixed rail | | the one with the red index dot |
| **Q** | gib rail | | tap M3 into its three small holes |

### 5g. Shift rod, thrust nut and drive nut

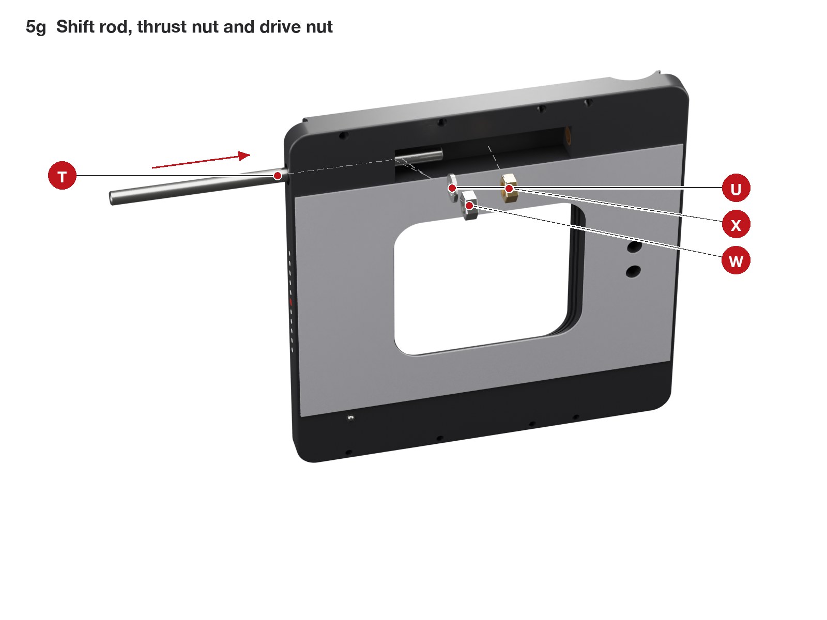
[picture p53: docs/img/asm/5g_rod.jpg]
5g


| | What | Qty | How |
|---|---|---|---|
| **T** | 138 mm rod | 1 | pushed in from the Y plate's **right** edge (photographer's right, H) |
| **U** | M6 washer | 1 | onto the rod inside the channel, first |
| **W** | stainless M6 nut (thrust nut) | 1 | next, with Loctite 243 |
| **X** | brass M6 nut (drive nut) | 1 | last |

Lay the Y plate front up. Push the rod in from the right edge, through the edge hole and the right bushing, into the channel. In the channel, thread onto its tip, one after the other, the washer U, the thrust nut W and the brass nut X: hold each one and turn the rod to feed it through. Push on until the tip stops at the bottom of the left seat, then pull the rod back 1 mm. Run the thrust nut back until it presses the washer against the bushing, finger tight, then put one drop of Loctite 243 where the rod comes out of the nut on the channel side: it wicks into the thread. Keep it away from the washer and the bushing. Let it set for an hour.

### 5h. Lens panel onto the Y plate

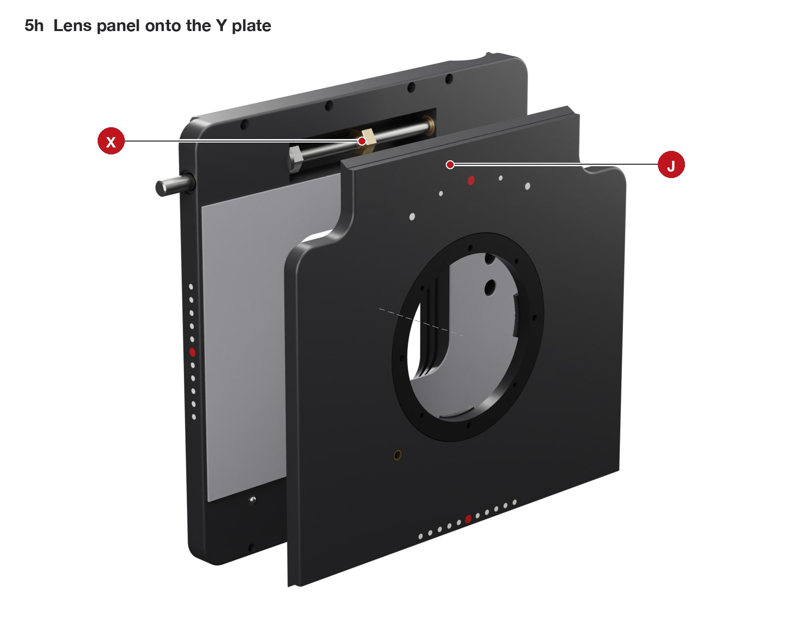
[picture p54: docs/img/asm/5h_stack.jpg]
5h


| | What | Qty | How |
|---|---|---|---|
| **J** | the turret under the lens panel | | drops into the channel, over the brass nut |
| **X** | brass nut | | in the middle of the channel, flats parallel to the channel sides |

Turn the brass nut to the middle of the channel, flats parallel to the channel sides. Lay the lens panel on the Y plate front, face up, its edges over the Y plate's edges: the turret is open underneath, so it drops into the channel over the rod and the nut. Hold the two plates together and turn them over, Y plate rear up.

### 5i. Horizontal rails, screwed from behind

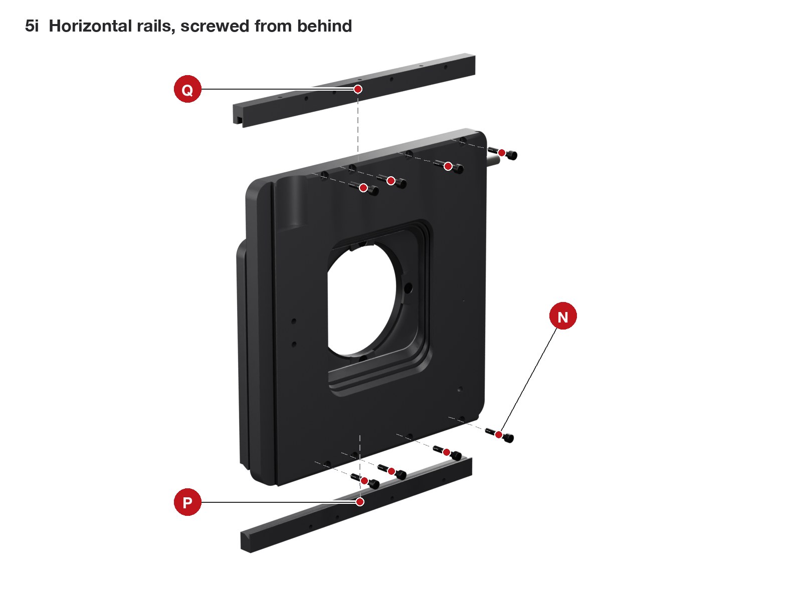
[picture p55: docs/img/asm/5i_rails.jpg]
5i


| | What | Qty | How |
|---|---|---|---|
| **P** | fixed rail | 1 | along the **bottom** edge, red index dot to the front |
| **Q** | gib rail | 1 | along the **top** edge, three small holes facing up |
| **N** | M3 x 16 socket head | 8 | from the Y plate rear into the tapped holes M |

Slide each rail in from its edge, between the two plates, until its holes line up with the Y plate's, and screw it from the rear.

### 5j. Gib strip and grub screws

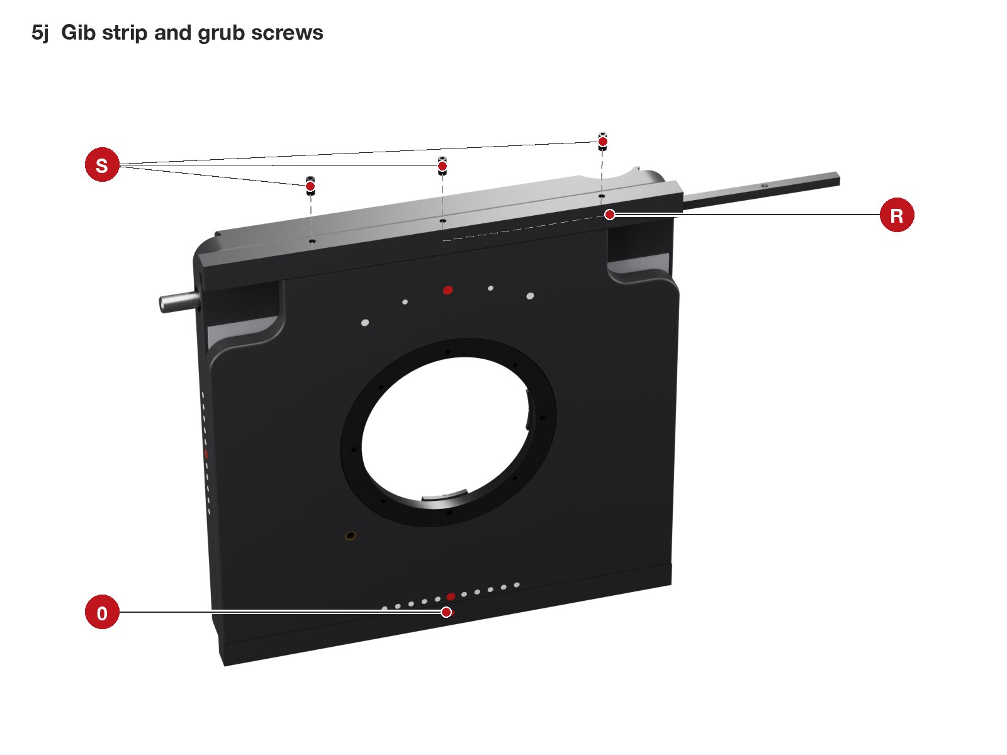
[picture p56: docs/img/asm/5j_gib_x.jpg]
5j


| | What | Qty | How |
|---|---|---|---|
| **R** | gib strip | 1 | slid into the pocket of Q from one end, dimples outward |
| **S** | M3 x 6 grub | 3 | through the top of Q, onto the dimples |
| **0** | nothing | | the shift index on the bottom rail |

Turn the stack face up. Tighten each grub a little at a time until the lens panel no longer rocks when you press its corners, then back each off an eighth of a turn. The panel must slide with an even, light drag over its whole travel. Give the dovetails a light spray of dry PTFE and slide the panel end to end a few times.

### 5k. Shift knob

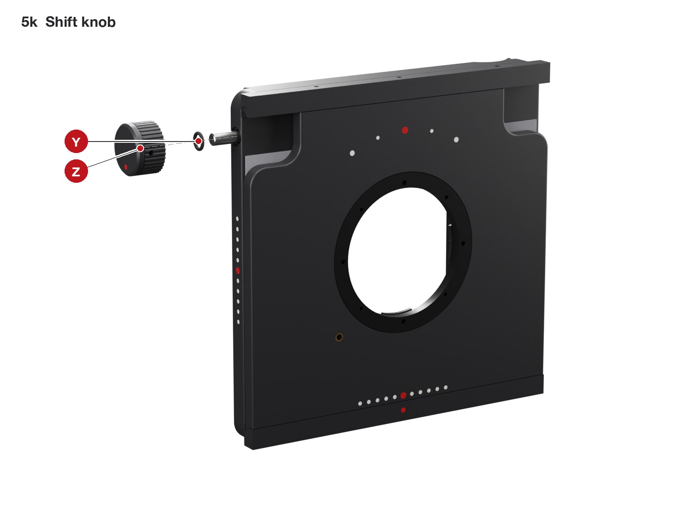
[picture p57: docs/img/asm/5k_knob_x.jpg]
5k


| | What | Qty | How |
|---|---|---|---|
| **Y** | O-ring 6 x 1.5 | 1 | in its seat around the rod at H |
| **Z** | knob with its M6 nut and grub | 1 | screwed onto the rod, locked with the grub |

Press a stainless M6 nut into the knob's hex pocket with the vice and tap M3 into the knob's small radial hole. Screw the knob onto the rod until it presses the O-ring lightly, and lock it with a grub. The right end wall of the Y plate is now held between the knob outside and the thrust nut inside.

**Check.** Turn the shift knob: 1 mm per turn, a click at zero, hard stops at 25 mm each side (on the right, the turret meets the thrust nut). The panel moves with an even drag and never rocks.

## 6. Front standard into the body, rise screw and knob

**You need:** the body from step 4, the front standard from step 5, the rise nut turret, 2 M3 inserts, 1 brass M6 nut, 2 M3 x 10 socket heads, the two 7 mm velvet discs, the Y gib strip, 4 M3 x 6 grubs (three for the gib, one for the knob), the 178 mm rod with a stainless M6 nut and an M6 washer (its end nut), O-ring, knob with its M6 nut and grub, Loctite 243, dry PTFE.

### 6a. Rise nut turret

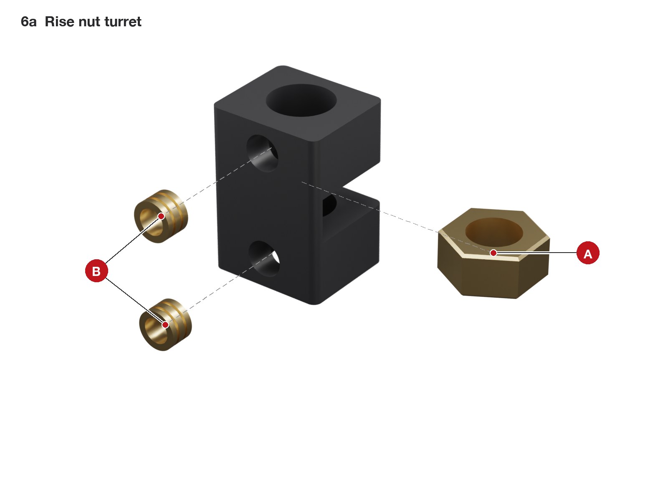
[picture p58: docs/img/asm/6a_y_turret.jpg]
6a


| | What | Qty | How |
|---|---|---|---|
| **A** | brass M6 nut | 1 | slid into the slot from the side, flats vertical |
| **B** | M3 insert | 2 | in the top face |

### 6b. Turret and rise rod into the body

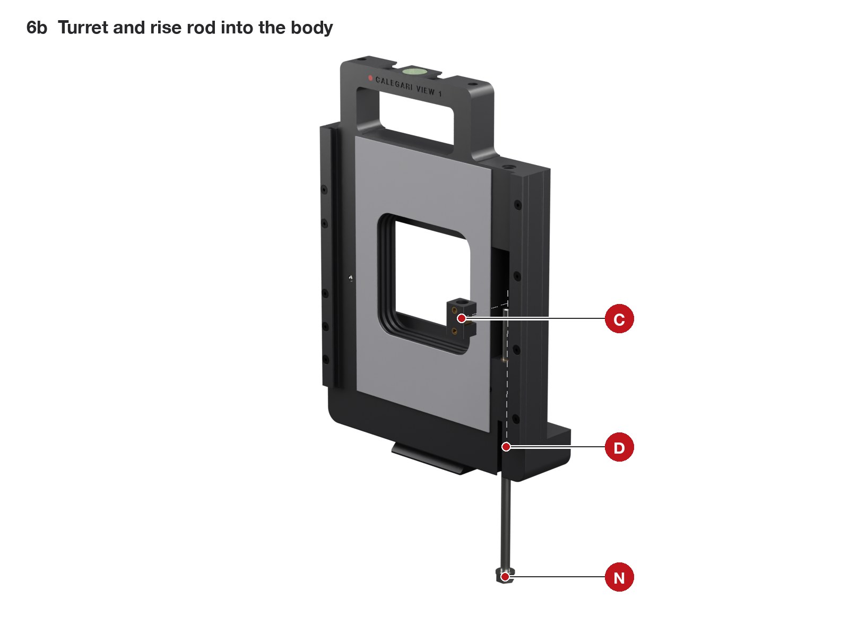
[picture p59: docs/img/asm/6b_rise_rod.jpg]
6b


| | What | Qty | How |
|---|---|---|---|
| **C** | the turret | 1 | into the screw channel on the body front |
| **D** | 178 mm rod with its washer and end nut | 1 | pushed up from below, through the bushings and the turret nut |
| **N** | the end nut | | sits in its recess under the body, the washer against the top of the recess |

On the bench, slip the washer onto one end of the rod and screw the nut on behind it with a drop of Loctite 243, about 1 mm of rod beyond the nut; let it set. Hold the body upright at the edge of the table, the corner under the rise channel overhanging (the end nut's recess opens in the bottom there), put the turret in the channel, and push the rod up from below through the bottom bushing, the turret nut (turn the rod to thread it through) and the top bushing, until the washer sits against the top of its recess. Turn the rod until the turret is in the middle of the channel.

### 6c. The front standard slides in from the top

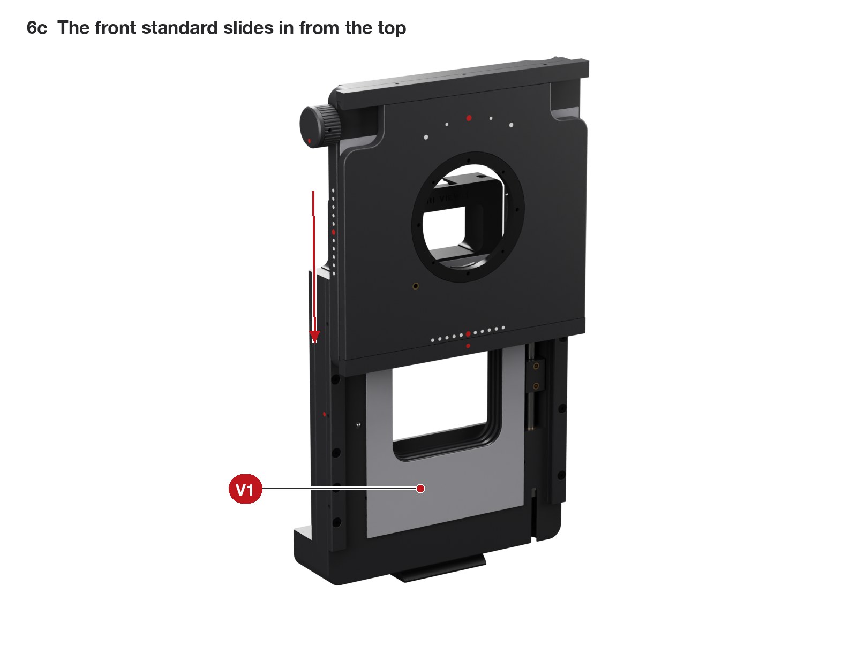
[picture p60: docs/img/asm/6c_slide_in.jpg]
6c


| | What | Qty | How |
|---|---|---|---|
| **V1** | the body velvet | | press its top edge flat with a finger as the plate passes |

Spray the vertical dovetails with dry PTFE. Hold the front standard upright above the body and lower it into the two vertical rails from the top: its slanted edges go under the rails. Slide it down slowly and stop when the Y plate is centred on the body.

### 6d. Turret screws and velvet discs

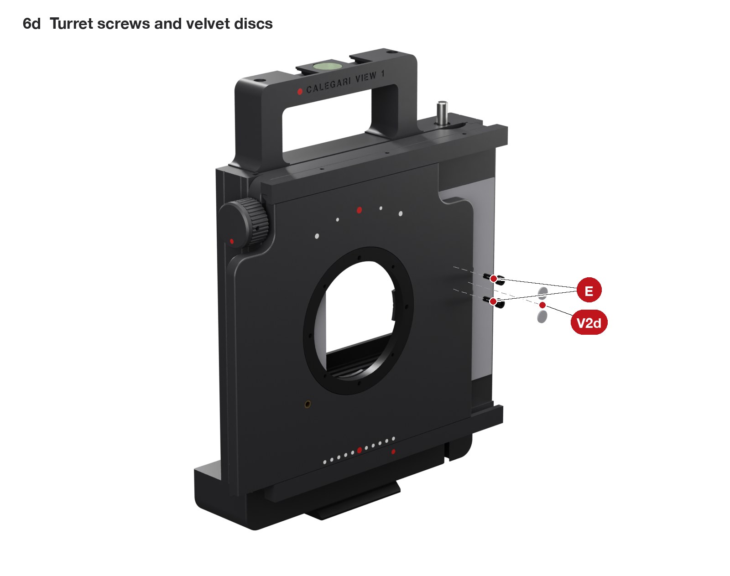
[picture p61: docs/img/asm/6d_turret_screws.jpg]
6d


| | What | Qty | How |
|---|---|---|---|
| **E** | M3 x 10 socket head | 2 | through the Y plate into the turret inserts B; the heads sit deep in the plate |
| **V2d** | 7 mm velvet disc | 2 | over each screw head: it closes the hole to light |

Shift the lens panel fully to the photographer's right: the two holes are now uncovered. Turn the rise rod until the turret's inserts are under them, then screw the turret to the Y plate.

### 6e. Gib strip and grub screws

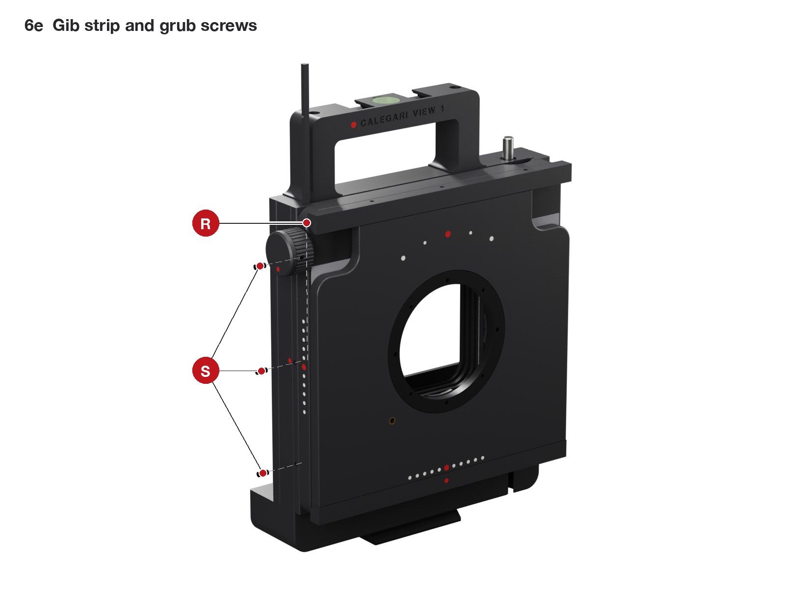
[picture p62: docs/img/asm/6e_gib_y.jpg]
6e


| | What | Qty | How |
|---|---|---|---|
| **R** | gib strip | 1 | slid into the pocket of the rail on the photographer's right, from the top, dimples outward |
| **S** | M3 x 6 grub | 3 | through the outer face of the rail |

Set it as in 5j: no rocking, an even light drag. The top grub sits behind the shift knob when the plate is near the middle: reach it with the plate at full fall.

### 6f. Rise knob

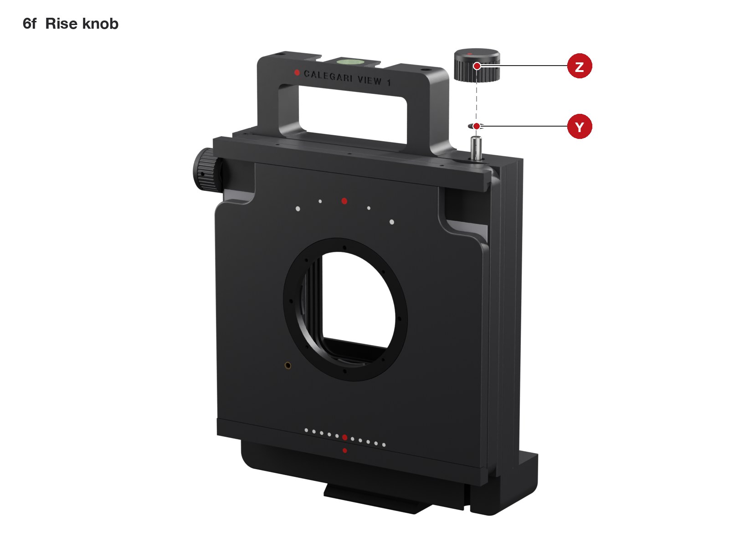
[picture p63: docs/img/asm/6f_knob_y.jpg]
6f


| | What | Qty | How |
|---|---|---|---|
| **Y** | O-ring 6 x 1.5 | 1 | in its seat on the top face, around the rod (K) |
| **Z** | knob with its M6 nut and grub | 1 | screwed onto the rod, locked with the grub |

Prepare the knob as in 5k. The rod turns with the knob until the plate reaches a hard stop: keep turning, and the knob then threads down onto the rod. Stop when it presses the O-ring lightly and lock it with the grub.

**Check.** Turn the rise knob: 1 mm per turn, a click at zero, hard stops at +25 and -25 mm. The plate stays where you leave it and never rocks.

## 7. Helicoid and focus ring

**You need:** the M65 helicoid, the focus ring, 5 M3 x 6 grubs (four for the ring, one is the stop pin), the M3 tap, Loctite 222.

### 7a. Stop pin and helicoid

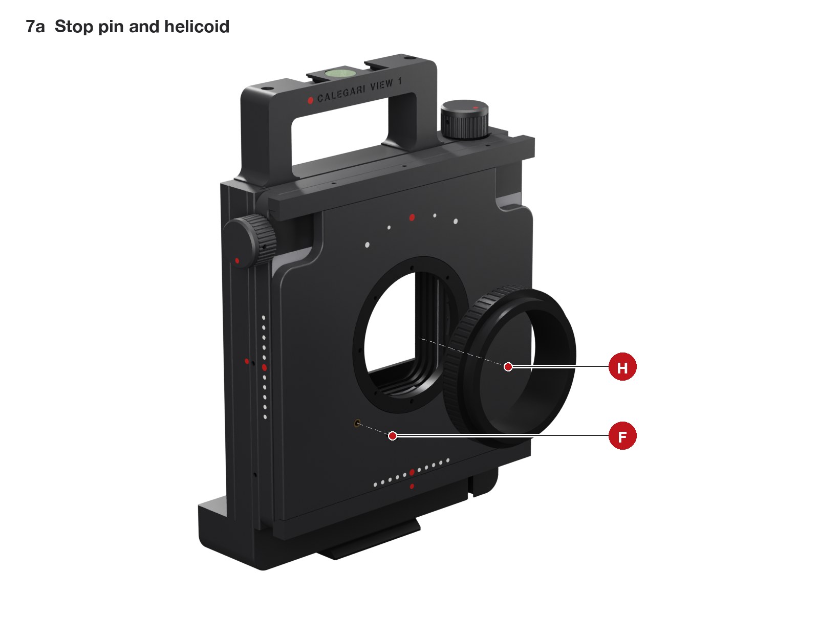
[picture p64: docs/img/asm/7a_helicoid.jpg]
7a


| | What | Qty | How |
|---|---|---|---|
| **F** | M3 x 6 grub: the stop pin | 1 | into the insert K of 5d until 3 mm stands proud; a drop of Loctite 222 |
| **H** | helicoid | 1 | its rear thread into the metal flange, one drop of Loctite 222 |

Screw the helicoid in until its shoulder seats. Hold its rear part and turn its focusing grip: the **front must not rotate**, it only moves in and out.

### 7b. Focus ring

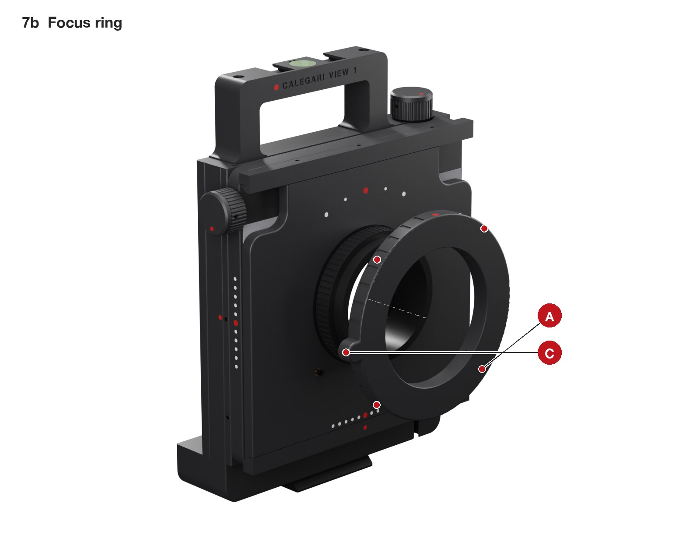
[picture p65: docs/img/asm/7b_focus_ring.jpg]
7b


| | What | Qty | How |
|---|---|---|---|
| **A** | M3 x 6 grub | 4 | tap M3 into the four radial holes; they clamp the ring on the helicoid |
| **C** | nothing | | the focusing tab |

Slide the ring over the helicoid's grip, groove side toward the camera, so the stop pin runs in the groove. Screw in the four grubs until they just touch: the ring is set during [calibration](calibration.md#3-infinity-teach-the-camera-where-infinity-is).

### 7c. The hidden stop

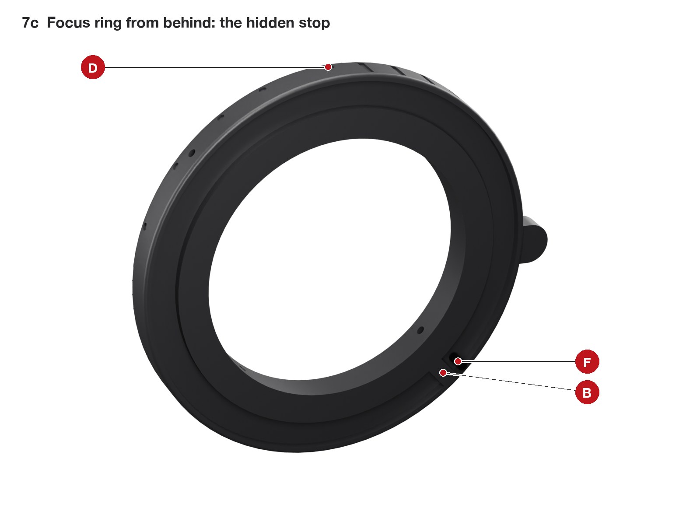
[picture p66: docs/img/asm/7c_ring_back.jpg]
7c


| | What | Qty | How |
|---|---|---|---|
| **B** | nothing | | the groove under the ring and its one solid block: at infinity the block rests on the pin |
| **F** | the stop pin | | runs in the groove |
| **D** | nothing | | the red infinity dot on the rim |

## 8. Adapter ring, board holder, lens board and lens

**You need:** the adapter ring, the board holder, the latch, 8 M3 inserts, 4 M3 x 8 countersunk, 2 M3 x 6 grubs, the 4 x 15 mm spring, felt pieces V3 and V4, the lens board and the lens.

### 8a. Inserts in the adapter ring

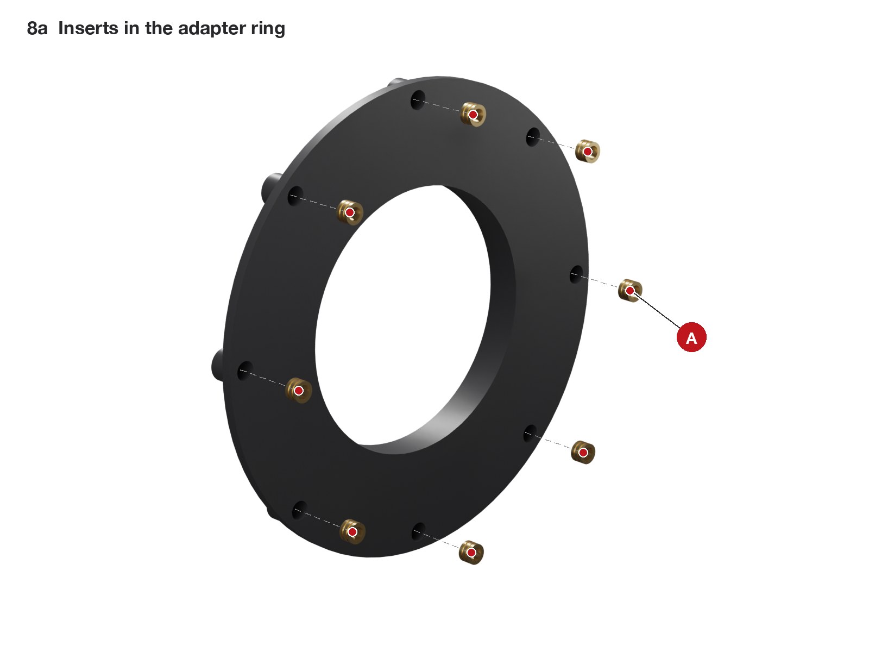
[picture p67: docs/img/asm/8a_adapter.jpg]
8a


| | What | Qty | How |
|---|---|---|---|
| **A** | M3 x 3 insert | 8 | in the bosses, pressed from the front face |

### 8b. Felt V3 behind the board holder

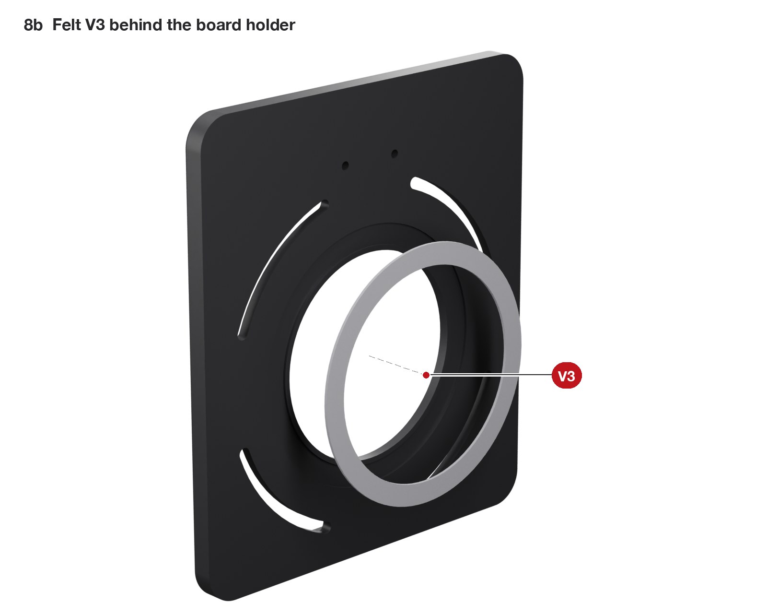
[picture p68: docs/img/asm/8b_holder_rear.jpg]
8b


| | What | Qty | How |
|---|---|---|---|
| **V3** | felt ring, cut from its template | 1 | in the round groove around the hole |

### 8c. Felt V4 and the spring

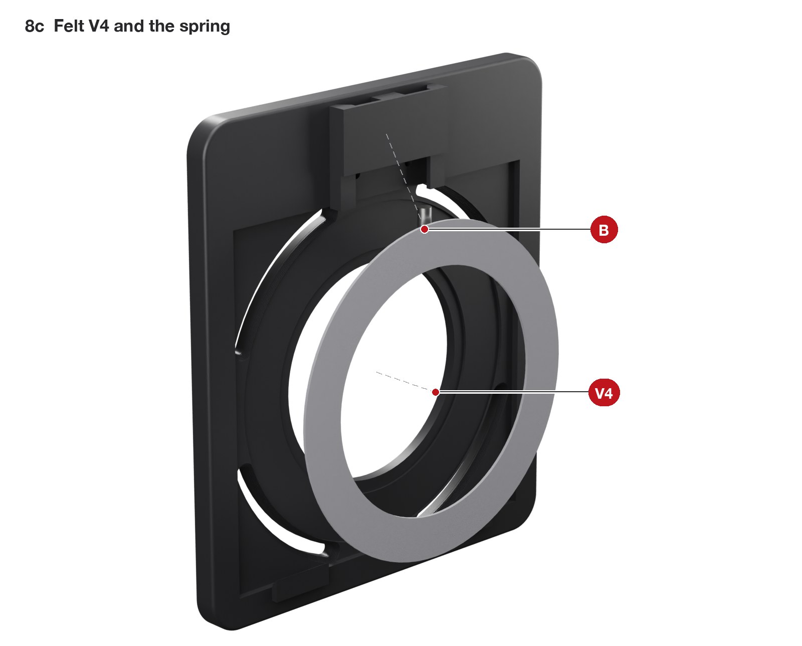
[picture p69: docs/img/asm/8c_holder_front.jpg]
8c


| | What | Qty | How |
|---|---|---|---|
| **V4** | felt ring | 1 | in the shallow round seat under the board |
| **B** | spring 4 x 15 | 1 | in its channel under the hood |

### 8d. Latch, held by two grubs from behind

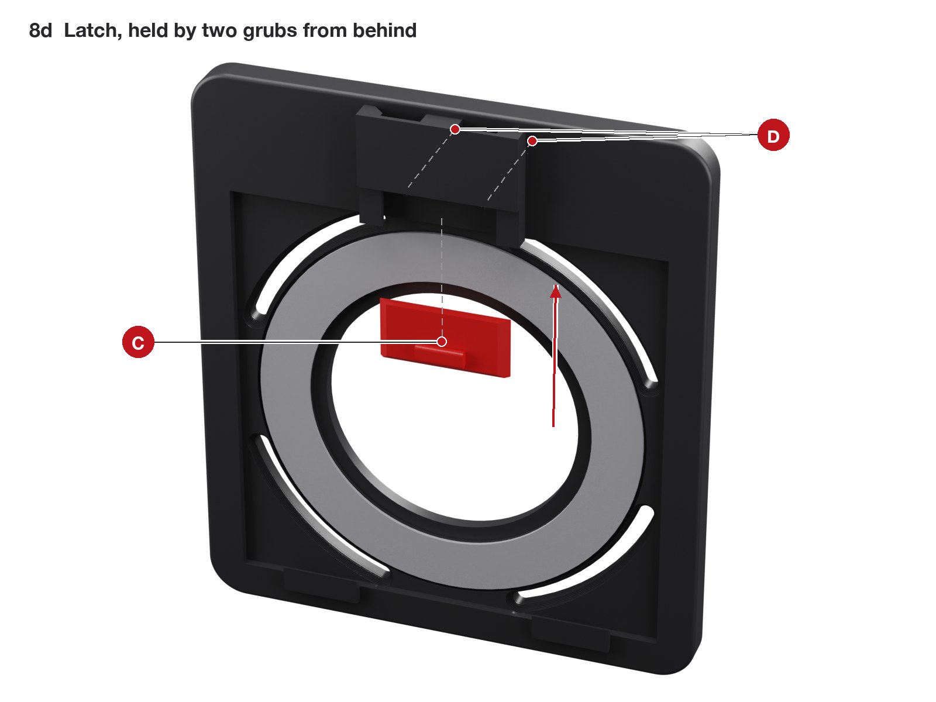
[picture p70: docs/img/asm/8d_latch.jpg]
8d


| | What | Qty | How |
|---|---|---|---|
| **C** | red latch | 1 | slid up into the dovetail between the rails, from below, flat face against the holder |
| **D** | M3 x 6 grub | 2 | tap M3 from the back of the holder, then turn the grubs in: their tips stand 1 mm proud and run in two grooves under the latch |

Slide the latch up into the dovetail from below and push it against the spring until its lower edge is level with the top edge of the board opening. Hold it there, turn the holder over and turn the two grubs D in from the back until they sit about 1.5 mm below the rear face: their tips now stand 1 mm proud in the grooves under the latch, and the groove ends stop it both ways. Pull the latch up with a thumbnail and let go: it snaps back down by itself. No screw shows on the front.

### 8e. Adapter and board holder onto the helicoid

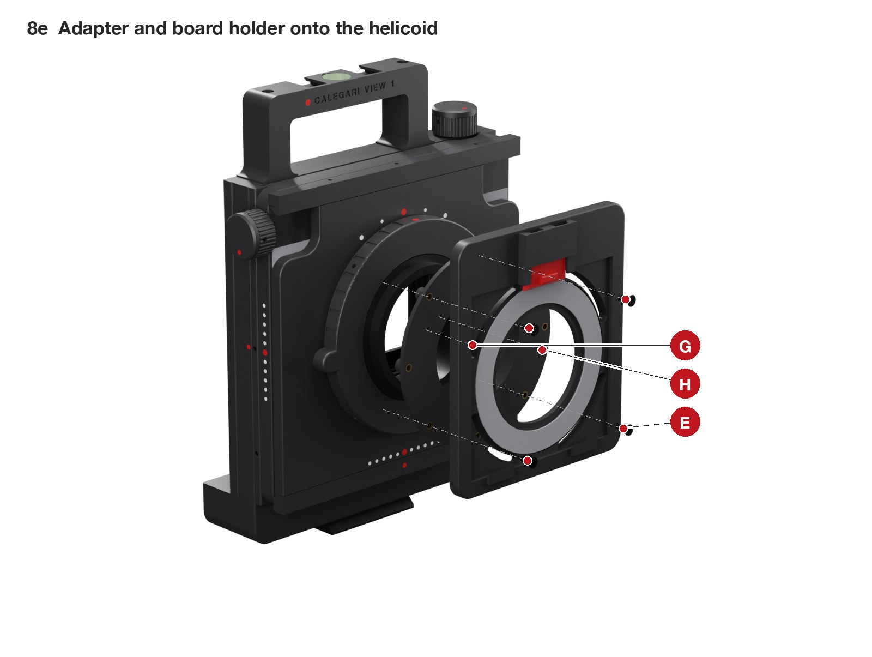
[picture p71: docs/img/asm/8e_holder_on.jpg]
8e


| | What | Qty | How |
|---|---|---|---|
| **G** | adapter ring | 1 | its male thread into the front of the helicoid, by hand, until its flange seats |
| **H** | board holder | 1 | laid on the adapter |
| **E** | M3 x 8 countersunk | 4 | through the holder's arc slots into whichever adapter inserts are under them; the heads sit flush under the board (use heads no wider than 6 mm) |

Leave the screws E loose, turn the holder until its edges are square with the lens panel, then tighten. They are under the board: you can reach them whenever the board is out.

### 8f. Lens board

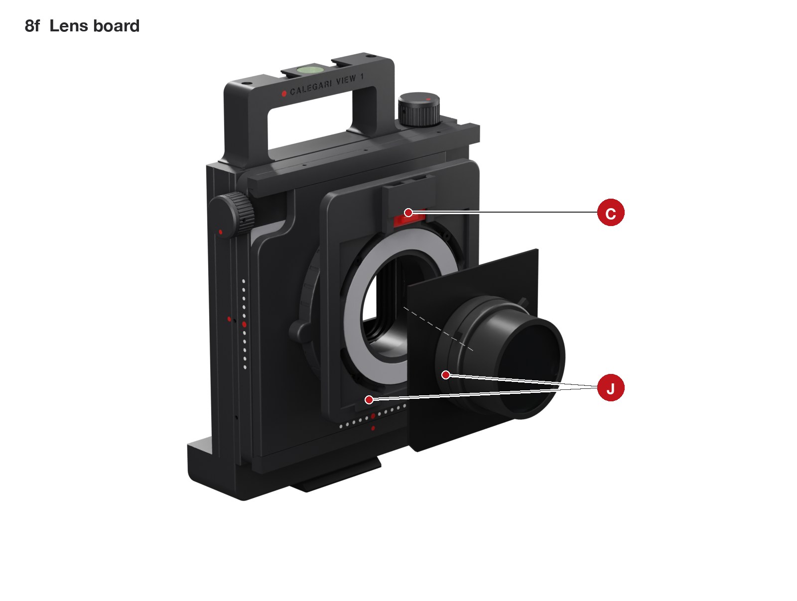
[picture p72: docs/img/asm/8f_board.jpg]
8f


| | What | Qty | How |
|---|---|---|---|
| **J** | the two bottom lips | | the board's bottom edge goes under them |
| **C** | the latch | | lift it with your thumb, press the board in, let it go: it drops over the board |

Screw the lens onto the board with its retaining ring, from behind. Hook the board's bottom edge under the lips J, lift the latch, press the top in and let the latch go.

**Check.** The board sits flat and does not rattle; the latch covers its top edge by 4 mm.

## 9. Film back

9a

| | What | Qty | How |
|---|---|---|---|
| **G** | the fixed bottom rail | | the back's bottom lip hooks under it; it also releases the Pro-S dark-slide interlock |
| **D** | the blade | | slides up into the two slots on top of the back |
| **F** | the wheel | | anticlockwise frees the blade, clockwise locks it |

1. **Loosen and lower.** Turn the wheel anticlockwise and slide the blade down.
2. **Hook the bottom.** Hook the back's bottom lip under the rail G.
3. **Seat the back.** Swing the back onto the seat: its nose goes into the recess.
4. **Lock.** Slide the blade up so its two tongues enter the slots in the top of the back, then tighten the wheel.
5. **Dark slide.** It comes out toward the photographer's right in landscape and at the top in portrait.
6. **Advance after each frame.** Press the back's own wind-stop release lever by hand: the camera has no automatic coupling (see [design notes](design.md#open-points)).

The ground glass goes on the same way. Now go to [calibration](calibration.md), then [using the camera](using.md).

## Hardware by step

| Step | Inserts | Screws | Other |
|---|---|---|---|
| 1 | M3 insert x 15, 1/4" insert x 1 | | M5 plunger, 2 bushings, epoxy |
| 2 | M3 insert x 3 | M3 x 10 socket x 4, M3 x 6 countersunk x 2, M3 x 8 countersunk x 1, M3 x 6 grub x 1 | M5 plunger, V5, Loctite 222, epoxy, dry PTFE |
| 3 | | M3 x 20 socket x 2, 1/4"-20 x 1/2" x 1 | bull's-eye level, epoxy |
| 4 | | M3 x 8 countersunk x 9 | V1 |
| 5 | M3 insert x 1 | M3 x 6 countersunk x 4, M3 x 16 socket x 8, M3 x 6 grub x 4 | flange, brass nut, 2 bushings, M5 plunger, rod 138 + M6 washer + M6 nut, O-ring, knob + M6 nut, V2, epoxy, Loctite 243, paint |
| 6 | M3 insert x 2 | M3 x 10 socket x 2, M3 x 6 grub x 4 | brass nut, rod 178 + M6 washer + M6 nut, O-ring, knob + M6 nut, 2 velvet discs, Loctite 243 |
| 7 | | M3 x 6 grub x 5 | helicoid, Loctite 222 |
| 8 | M3 insert x 8 | M3 x 8 countersunk x 4, M3 x 6 grub x 2 | spring, V3, V4 |

All the small hardware is M3 stainless: socket heads in three lengths (10, 16, 20), countersunk in two (6, 8), one grub (6) and one insert. One assortment of each covers the camera.

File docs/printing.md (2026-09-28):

# Printing

[Back to the project](../README.md)

Designed for a Bambu Lab P1S with AMS, but any enclosed printer with a 256 x 256 mm bed works. The largest part, the body with its tripod base, is 170 x 195 mm on the bed. Every part is already oriented and needs no supports.

## Order: calibrate, test, then print

About 50 hours of printing go into the camera. The first four hours tell you whether they will be well spent.

| Step | Plate | What it tells you |
|---|---|---|
| 1 | `plate_00a_shrink_gauge` | how much your ASA shrinks: set it in the slicer (below) before anything else |
| 2 | `plate_00b_test_1`, with the shrinkage set | the rotator (the back's seat) on your RB67 back and ground glass, the metal flange in its pocket, and ten 40 mm slices of the dovetail ways to slide by hand. See [calibration, section 1](calibration.md#1-before-printing-the-body-test-prints) |
| 3 | `plate_00c_test_thread_0.12mm_layers` | the printed M65 thread in your helicoid |
| 4 | change `cad/params.py` if a test asked for it, run `export.py` again | |
| 5 | plates 01 to 07 in black, the red plate, and the shims if you will use more than one lens | the camera |

The rotator, blade and wheel on the test plates are real parts, printed with the final shrinkage: if they fit your back, keep them and skip `plate_05` and the blade on the red plate (a black blade works as well as a red one). Print the rotator of the test plate with its red index dot, as below, if you mean to keep it.

## Shrinkage: calibrate it before anything else

ASA shrinks about 0.5 to 0.7 % as it cools. Uncompensated, that is 0.5 mm on the lens board pocket and on the flange pocket: the board or the flange would not go in, and the dovetails would bind. Bambu Studio compensates it per filament, but the value must be measured on your spool.

1. Print `plate_00a_shrink_gauge` in the ASA you will use, with the settings below.
2. Let it cool for ten minutes, then measure the outer size along X (the side with the tab) and along Y with a caliper.
3. Shrinkage (%) = measured / 100 x 100. For example 99.45 mm gives 99.45 %.
4. In Bambu Studio, open the filament (three dots next to it, *Edit*), set *Shrinkage* to that value and save the profile as "ASA - Calegari View".
5. Use that profile for every part. Reprint the gauge once: it should now measure 100.0 +/- 0.1 mm.

Plate 00a

## Material

**ASA.** It does not warp in a hot car, it resists UV, and printed on the textured plate it has a matte finish that reads like black paint. PLA is fine for fit tests, not for the camera. No fibre-filled filaments.

- Black ASA: about 830 g for the camera plus about 120 g of tests. Buy two 1 kg spools, or one if you are confident in the first print.
- Red ASA: a few grams (the Graflok blade, the board latch, the zero and infinity dots, the index of the rotating back).
- White ASA: a few grams, optional (the other scale dots, the landscape and portrait marks on the rear frame).

ASA gives off fumes while printing: keep the printer in a ventilated room.

## Settings

| Setting | Value |
|---|---|
| Nozzle | 0.4 mm stainless (stock) |
| Plate | textured PEI with a thin layer of glue stick |
| Chamber | door closed, top on; preheat 10 minutes with the bed at temperature |
| Temperatures | Bambu ASA profile (260 C nozzle, 100 C bed) |
| Part cooling | 20-30 % |
| Layer height | 0.16 mm; 0.12 mm for plate 06 (focus ring and adapter ring) and the thread coupon; 0.2 mm for the shims |
| Walls | 5 on the parts that close the dark chamber (body, rotator, rear frame, Y plate, lens panel, board holder, adapter ring); 4 elsewhere |
| Top and bottom layers | 6 |
| Infill | 30 % gyroid; 100 % for the knobs, turrets, rails, gib strips, blade, wheel, latch and shims |
| Elephant foot compensation | 0.15 mm (the Bambu default): the edges that mate are chamfered as well |
| Ironing | the body's rear face (the rotator runs on it) and the rotator's seat (the floor where the back's nose sits); both print as top surfaces |
| Seams | paint them where they do not matter: the body inside the bottom Arca pocket, the Y plate's bottom edge, the lens panel's photographer's-right edge, the rails and gibs at their ends, the knobs and the focus ring inside a flute, the handle at the inner foot |
| Supports | none |
| Brim | brim ears (corners only) on the body, the rear frame, the Y plate and the lens panel: ASA lifts at the corners. The plates leave 12 mm between parts for them |

Let each plate cool in the closed printer for ten minutes before opening the door: ASA warps if it cools in a draught.

## The plates

| Plate | Parts | Notes |
|---|---|---|
| `plate_00a_shrink_gauge` | 100 mm gauge | first |
| `plate_00b_test_1` | rotator, blade, ten dovetail coupons | the ASA you will use |
| `plate_00b_test_2` | flange pocket coupon, two lip coupons, Graflok wheel | |
| `plate_00c_test_thread_0.12mm_layers` | M65 thread coupon | 0.12 mm layers, like the adapter |
| `plate_01_black` | body with its tripod base | alone on the plate: about 20 hours |
| `plate_02_black` | rear frame, the four dovetail rails, the X gib strip, the shift nut turret, Graflok wheel | |
| `plate_03_black` | Y plate, Y gib strip, top handle, both knobs, rise nut turret | |
| `plate_04_black` | lens panel | |
| `plate_05_black` | rotator | skip it if the test rotator fits |
| `plate_06_black` | board holder | |
| `plate_07_black_0.12mm_layers` | focus ring, adapter ring | 0.12 mm layers for the M65 thread |
| `plate_red_1` | Graflok blade, board latch | red ASA |
| `plate_07_shims_0.2mm_layers` | five lens shims, 0.4 to 1.2 mm | 0.2 mm layers; only for more than one lens ([calibration, section 4](calibration.md#4-more-lenses-one-stop-for-all-of-them)) |

### What each plate looks like

The parts as `export.py` placed them on the 256 x 256 mm bed, already in their print orientation.

plate_00b_test_1

plate_00b_test_2

plate_00c_test_thread_0_12mm_layers

plate_01_black

plate_02_black

plate_03_black

plate_04_black

plate_05_black

plate_06_black

plate_07_black_0_12mm_layers

plate_red_1

plate_07_shims_0_2mm_layers

Single parts, oriented and dropped on the bed, are in `print/stl`; the same parts in assembly coordinates are in `print/step` for editing. The cutting templates for the velvet and felt (V1 to V5, and two 7 mm discs) are A4 SVG files in `print/templates`: print them at 100 %.

| Part | Orientation | Why |
|---|---|---|
| body | front face down | the front comes out flat and textured; the rear face, on which the rotator turns, is the top surface, ironed |
| rotator | front face down | the face that runs on the body comes off the bed flat; the seat of the back is a top surface, ironed; the bottom rail stands up |
| rear frame | rear face down | the white marks are on the bed; the step for the velvet ring prints on top |
| Y plate | front face down | the front is the flat sliding face; the dovetail lips print at 30 degrees |
| lens panel | rear face down | the rear is the sliding face; the flange pocket is on top |
| fixed rails | base down | the base and the bearing flange come off the bed flat |
| gib rails | on their outer face | the gib pocket prints as a wall, not as an overhang |
| gib strips | upside down | the flank ends in a small flat, not a knife edge |
| turrets | as modelled | the nut slots open on the bed |
| knobs | crown down | the knurl prints as walls, the red dot is on the bed |
| focus ring | front face down | the front and the dots print crisp |
| adapter ring | flange down | the thread and the bosses print upwards |
| board holder | rear face down | |
| top handle | front face down | the engraved name plate prints on the bed; the accessory shoes print as walls |

## Coloured dots

The scales are recessed dots, 2 to 3.4 mm across and 0.6 mm deep: no text or fine ticks, which do not print well in multi-material. Red marks the zeros and infinity, white the other positions.

**With the AMS, only where it is cheap.** The dots on a top or bed face need a few colour changes: the lens panel front (focus index, depth of field and shift scale), the bottom horizontal rail (shift index), the two knobs, the handle's name plate, the rotator's red index and the two white marks of the rear frame. Their inlays are in `print/inlays/`.

1. Import the part, for example `print/stl/x_plate.stl`.
2. Right-click, *Add part*, *Load*, and pick the matching file in `print/inlays/`, for example `x_plate__red.stl`. The coordinates match: it drops into the recesses.
3. Assign the part to the red (or white) filament.

**With paint, on the walls.** The dots on side walls (the rise scale on the Y plate edge and its index on the body, the distance dots on the focus ring rim) would cost dozens of colour changes and grams of purge. Print them black and fill them with a drop of acrylic paint, wiping the excess with a damp cloth. The same works for every dot if you have no AMS.

## Printability report

`print/PRINTABILITY.txt` lists, for every part in its print orientation, the downward-facing area steeper than 45 degrees and the largest downward span. The large "spans" in the report are rings and slots whose overhang is short (the stepped light baffles, the felt grooves, the thread flanks, the flare lobes behind the lens panel bore); the longest true bridge is the board holder's latch hood, 36 mm between two rails.

## After printing

- **Flatness.** Put a steel straightedge on both faces of the body, the rotator's front face, both faces of the Y plate and the lens panel rear. The gap under it must stay below 0.1 mm: these faces carry the light seal. Reprint a warped plate rather than shimming it.
- **Heat-set inserts.** Soldering iron with the right tip at about 230 C. See [assembly](assembly.md#five-techniques-you-will-use).
- **Threads to tap by hand.** M3 (2.5 mm holes) in the four radial holes of the focus ring, the two knobs, the six grub holes of the two gib rails, the eight holes in the base of the horizontal rails, the two latch holes of the board holder and the stop hole of the rotating back (only its narrow rear end); M5 in the three ball plunger holes (4.2 mm).
- **Bushing seats.** 8.1 mm horizontal holes for 8 mm bushings: horizontal holes print slightly small, so ream them with an 8 mm drill turned by hand.
- **Deburr** the dovetail flanks with a fine file if a layer sticks out, then give them a light coat of dry PTFE.

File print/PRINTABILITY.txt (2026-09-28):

part                 copies  material  overhang_area_mm2  largest_downward_span_mm
body                      1  blackbody               4146        80.9
bezel                     1  black                    81         5.9
rotator                   1  black                  1251        27.0
graflok_blade             1  red                       0         0.0
graflok_wheel             1  black                     0         0.0
y_plate                   1  black                  2808        82.6
y_turret                  1  black                    92         5.2
way_y_fixed               1  black                     0         0.0
way_y_gib                 1  black                    38         2.2
gib_y                     1  black                     0         0.0
way_x_fixed               1  black                    20         2.5
way_x_gib                 1  black                    46         1.7
gib_x                     1  black                     0         0.0
x_plate                   1  black                  1191        27.5
x_turret                  1  black                   134         5.3
focus_ring                1  black012                213        14.5
adapter_ring              1  black012                622        64.7
board_holder              1  black                  1728        74.0
holder_latch              1  red                      63         3.4
knob                      2  black                    49         2.4
top_handle                1  black                   464         4.4

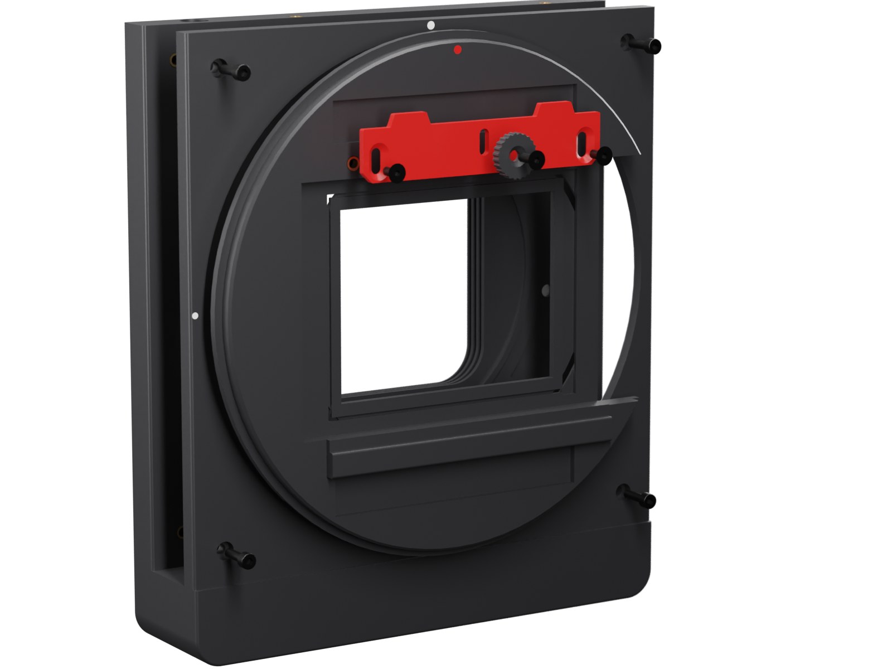
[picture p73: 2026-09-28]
docs/img/step_02.jpg

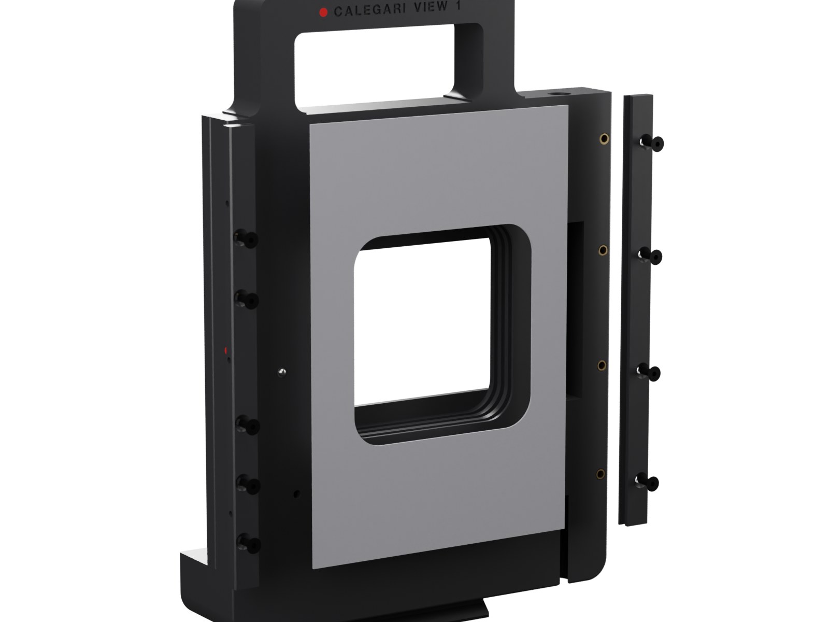
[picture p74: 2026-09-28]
docs/img/step_04.jpg

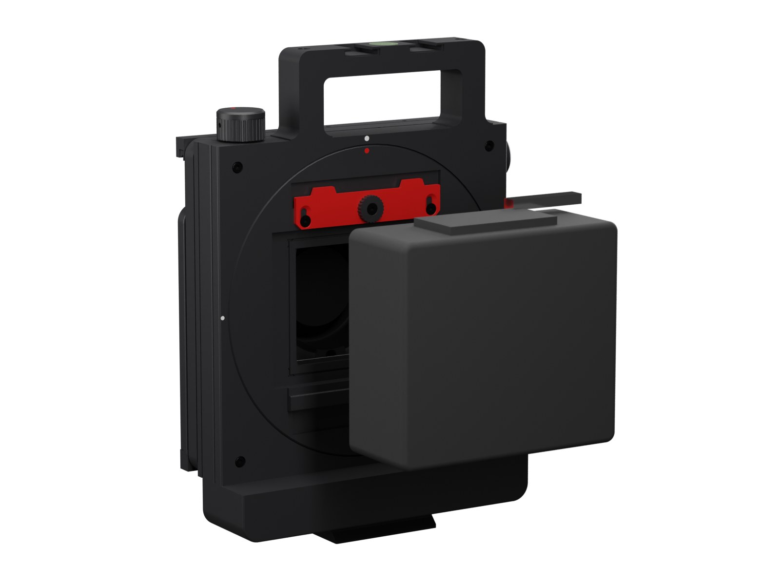
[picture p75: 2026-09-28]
docs/img/step_09.jpg

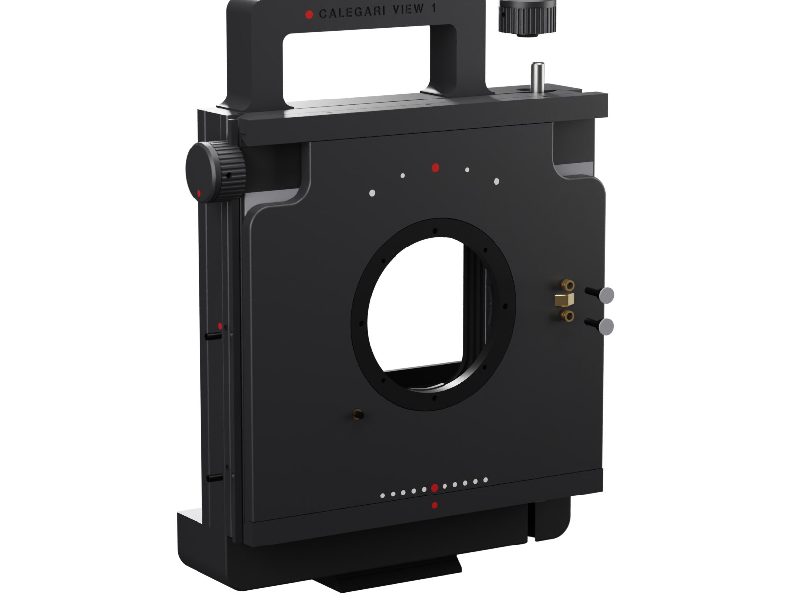
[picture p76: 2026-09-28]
docs/img/step_06.jpg

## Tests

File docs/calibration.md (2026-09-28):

# Calibration and tests

[Back to the project](../README.md)

You do not need to know view cameras to calibrate this one. This page explains every word the first time it appears, says what you are doing and why, and tells you what a good result looks like. The software already checked that the parts fit together and that the light path is sealed; what follows can only be checked with the real parts in your hands.

Take the sections in order. Section 1 happens before you print the big parts; the rest after [assembly](assembly.md).

## The camera in five minutes

If you have used only digital or 35 mm cameras, these are the pieces that are new.

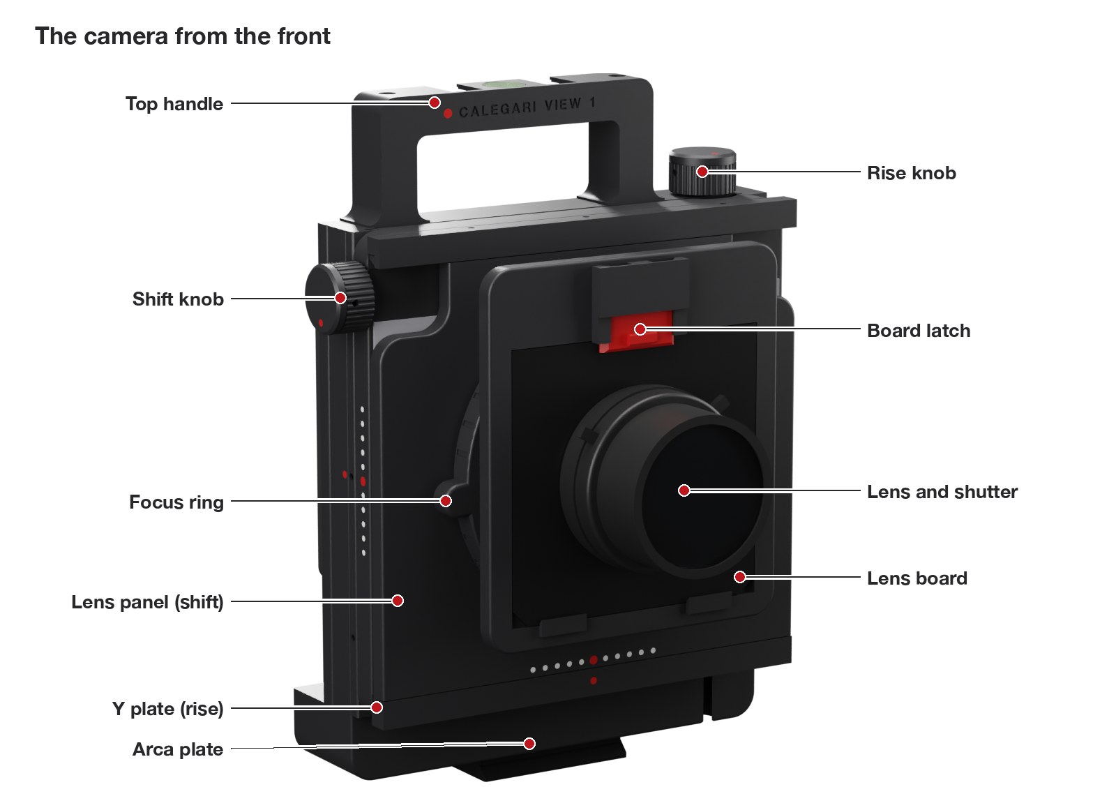
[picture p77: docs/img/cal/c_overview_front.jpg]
The camera from the front


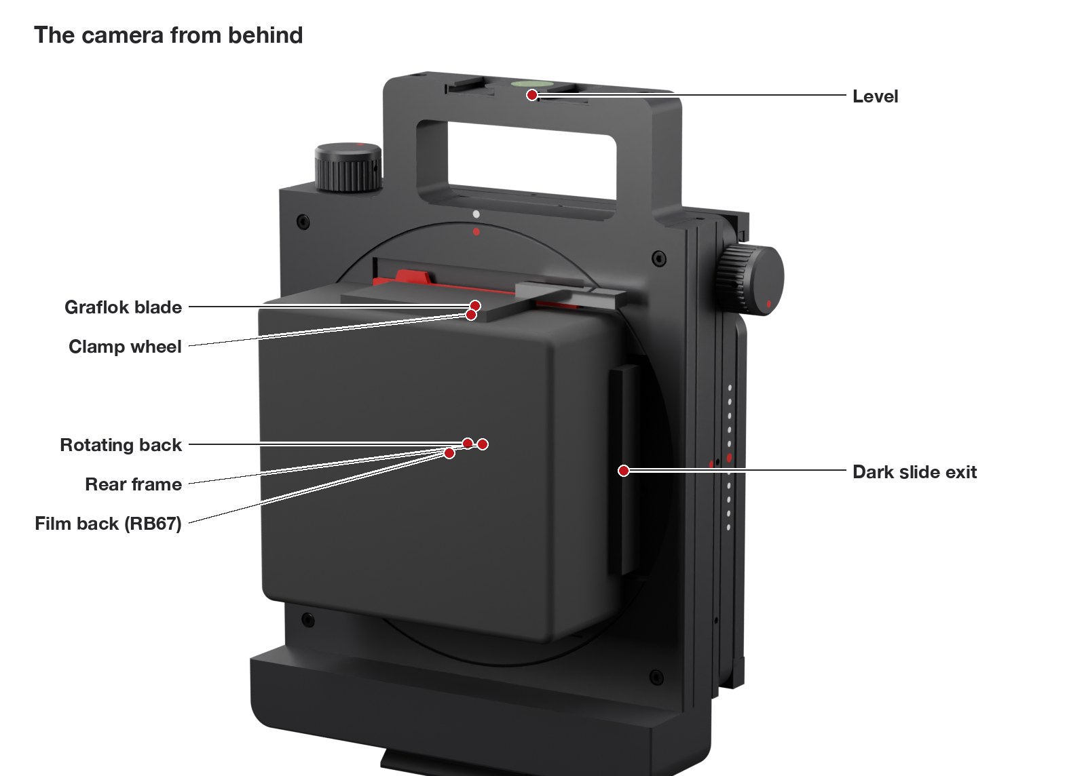
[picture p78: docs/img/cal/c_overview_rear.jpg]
The camera from behind


- **Lens and shutter.** Large-format lenses carry their own shutter, a little mechanism with the speeds and the aperture on it (*Copal 0* is its size). The camera body has no shutter and no electronics.
- **Lens board.** A flat metal plate (99 x 96 mm, the *Technika* size) with the lens screwed into it. Each lens lives on its own board; changing lens means changing board, which takes ten seconds.
- **Helicoid.** The focusing tube between the camera and the lens board. Turning it moves the lens forward and back. The printed **focus ring** with its lever sits on it.
- **Infinity.** Anything far away: mountains, buildings across a square. At infinity the lens is as close to the film as it will ever be. The **stop** is a pin on the lens panel that makes the focus ring stop exactly there, so you can find infinity without looking.
- **Film back.** A Mamiya RB67 roll film holder: it holds a 120 roll and takes ten 6 x 7 cm pictures. The **dark slide** is the thin metal sheet you pull out before exposing and push back afterwards; while it is in, the back can come off in daylight.
- **Graflok.** The standard way the back clamps to the camera: a hook at the bottom, a sliding blade with two tongues at the top.
- **Rotating back.** The back clamps to a round plate, the rotator, that turns a quarter turn in the body: landscape or portrait without turning the camera.

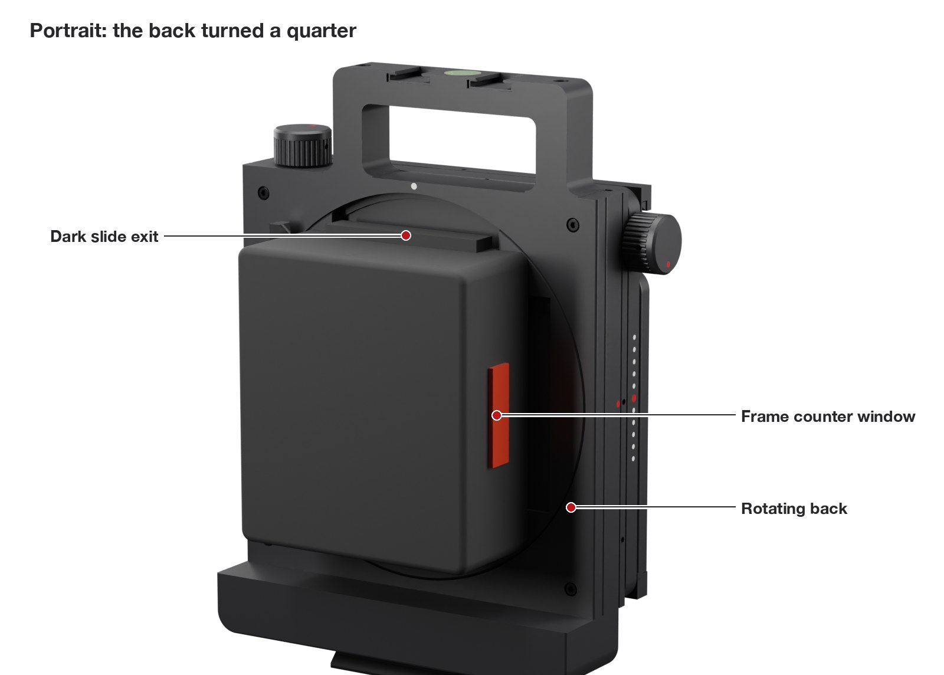
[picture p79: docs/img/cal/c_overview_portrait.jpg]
Portrait: the back turned a quarter

- **Ground glass.** A frosted glass in a frame, with the same shape as the film back. You clamp it on instead of the back to see the image, check the composition and focus. The image on it is upside down and mirrored: that is normal. A **loupe** (4x to 8x magnifier) laid on the glass shows fine focus, and a **dark cloth** over your head and the camera makes the dim image visible.
- **Shift.** Moving the lens up, down or sideways instead of pointing the camera. Keeping the camera level and moving the lens up (**rise**) is how architecture photographers keep vertical lines vertical. **Fall** is the opposite of rise. The **image circle** is how much picture the lens draws: the more it covers, the further you can shift.

## 1. Before printing the body: test prints

Software cannot check your own back, your ground glass, or how your printer makes a sliding fit. Print `plate_00a_shrink_gauge` and set the shrinkage (see [printing](printing.md#shrinkage-calibrate-it-before-anything-else)), then `plate_00b_test_1` and `plate_00c_test_thread_0.12mm_layers` in the ASA you will use. About four hours in all.

### Does my back fit?

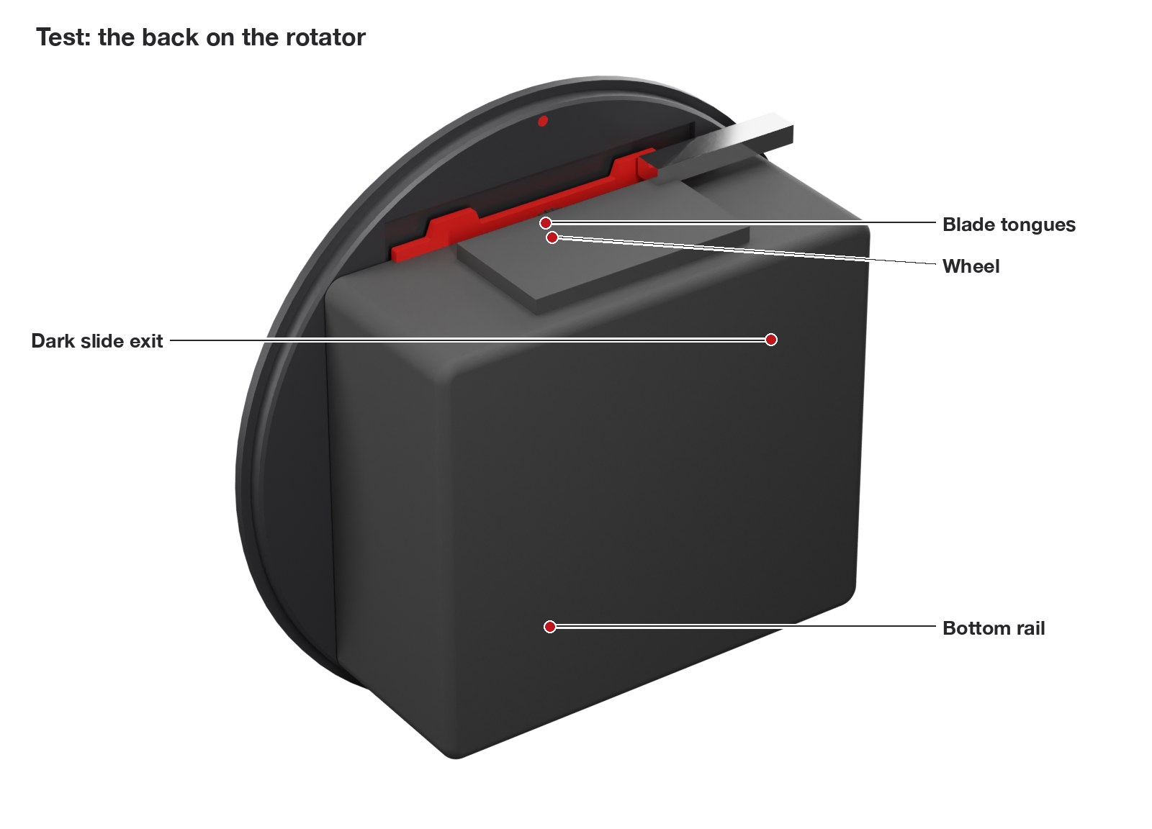
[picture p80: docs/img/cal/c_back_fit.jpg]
The back on the test rotator


1. Assemble the test rotator as in [assembly, 2a and 2b](assembly.md#2a-inserts-in-the-rotator), with its inserts: if it fits, it is the rotator you will use.
2. Lay it on the table, front face down. Cut four strips of thin paper, 1 cm wide, and lay one across the seat on each side of the gate (the seat is the floor the back's nose will sit on).
3. **Mount the back.** Turn the wheel loose and slide the red blade down. Hook the bottom lip of the back under the bottom rail of the rotator, swing the back down onto the seat, slide the blade up into the two slots on top of the back, and tighten the wheel.
4. **Look for four things:**
   - the back's raised nose (the rectangle around its opening) presses on the seat all round: pull each paper strip, all four must be held;
   - the back's top and bottom lips sit in the cut-outs of the rotator without touching;
   - both tongues of the blade are inside the back's slots;
   - pushing the back with your hand, it does not move.
5. **Dark slide.** With the back locked, pull the dark slide out toward the right as you look at the back. It must slide out freely. On a Pro-S back this also proves that the bottom rail releases the safety catch that otherwise locks the slide.
6. **Ground glass.** Do the same with your ground glass.

If all of it works, print the camera as it is.

If something does not fit, measure the back and change the numbers in `cad/params.py`, Graflok section (`POCKET_*`, `LIP_RELIEF_*`, `SLIDE_RELIEF_*`; `BLADE_*` and `TONGUE_X` in `parts.py`), then run `check.py` and `export.py` again. The measurements that matter, with the nose face as Z = 0 and the centre of the film frame as X/Y = 0:

<details>
<summary>The twelve measurements</summary>

| # | What | Why |
|---|---|---|
| M1 | nose: X to the closed end and to the dark-slide end, Y top and bottom, protrusion over the rim | pocket |
| M2 | light-trap ridge: X position, width, height | groove in the seat |
| M3 | top and bottom lips: inner and outer Y, X extent, gap from the nose face | lip reliefs |
| M4 | Graflok slots in the top lip: X centres, width, depth, walls from the nose face | blade tongues |
| M5 | dark-slide handle: hook Y band, protrusion ahead of the nose face, handle X and thickness, full slide length | dark-slide relief |
| M6 | dark-slide safety catch (Pro-S, Pro-SD): X, Y, diameter, protrusion, release depth | bottom rail |
| M7 | wind-stop release receptor: X, Y, diameter, stroke | future coupling |
| M8 | film advance lever: hub position, lever length, height above the top, swing | top handle clearance |
| M9 | overall outline including the lever | |
| M10 | same as M5 to M7 for a Pro-SD | |
| M11 | ground glass: outline, nose, ridge, slots | |
| M12 | nose face to the inner film rails, where the emulsion lies (Graflok standard: 4.75 mm) | registration |

</details>

### Do the dovetails slide?

The test plate has ten 40 mm slices of the real dovetail ways. They tell you in five minutes whether the movements will slide on your printer.

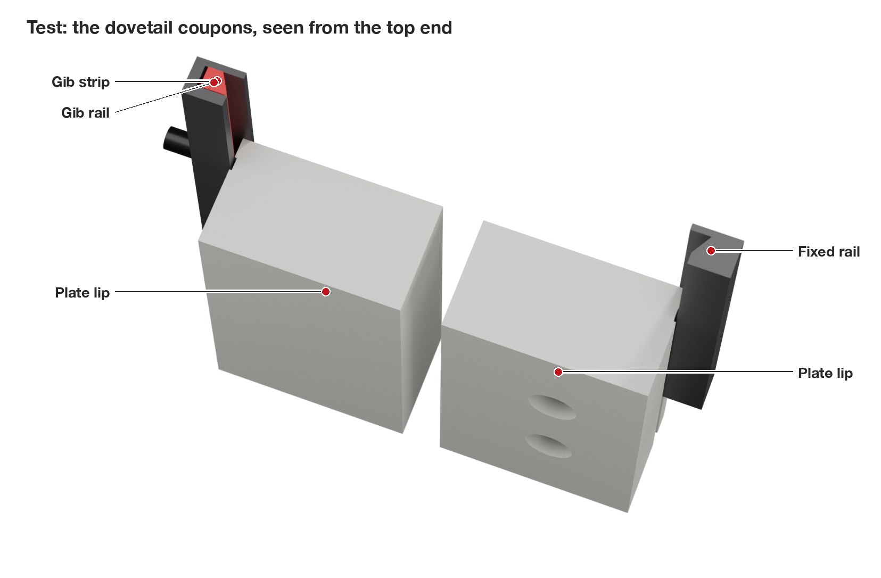
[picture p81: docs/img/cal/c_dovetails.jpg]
The dovetail coupons


1. **Fixed side.** Stand `coupon_way_y_fixed` on its base on the table and slide `coupon_lip_y_left` along it, its slanted edge under the rail's slanted edge and its back resting on the rail's thin flange. It must slide by hand with a light, even drag, and must not rock up or down.
2. **Gib side.** Stand `coupon_way_y_gib` on its base, lay `coupon_gib_y` in its pocket (dimple outward), slide `coupon_lip_y_right` in, and turn one M3 x 6 grub screw into the middle hole until the play is gone. It must still slide.
3. **Horizontal ways.** Repeat with the `x` coupons.

| What you feel | Cause | What to change |
|---|---|---|
| slides with a light, even drag, no rocking | right | nothing |
| the fixed side is tight or scrapes | the print is oversize | check the shrinkage; then raise `FLANK_C` in `params.py` by 0.05 |
| the fixed side rocks | the print is undersize | lower `FLANK_C` by 0.05 |
| the gib side cannot take up the play | gib strip too thin | raise `GIB_T` for that stage by 0.2 |

A light coat of dry PTFE on the flanks makes any fit smoother; file off a layer that sticks out before judging.

### Do the metal parts fit the printed ones?

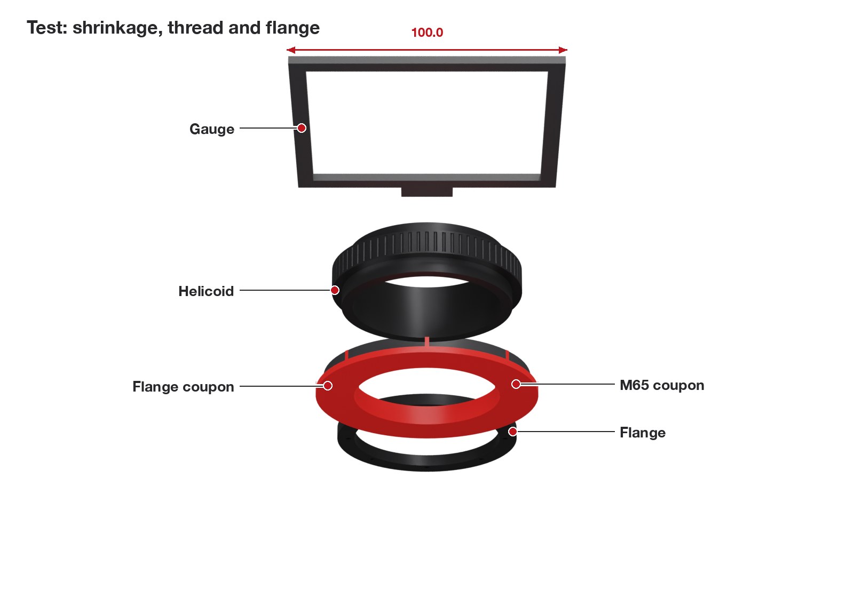
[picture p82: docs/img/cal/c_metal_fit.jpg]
Shrinkage, thread and flange


- **M65 coupon** (printed at 0.12 mm, like the adapter). It must screw into the front of your helicoid by hand, with no wobble and no forcing. Tight: lower `M65` in `params.py` by 0.1. Loose: raise it by 0.1.
- **Flange coupon.** The RafCamera metal flange must drop into the pocket and sit flush, with its four threaded holes over the four countersunk holes. If it does not go in, check the shrinkage setting before changing anything else.
- **Shrinkage gauge.** It must measure 100.0 mm, plus or minus 0.1, on both sides.

### Measure your helicoid

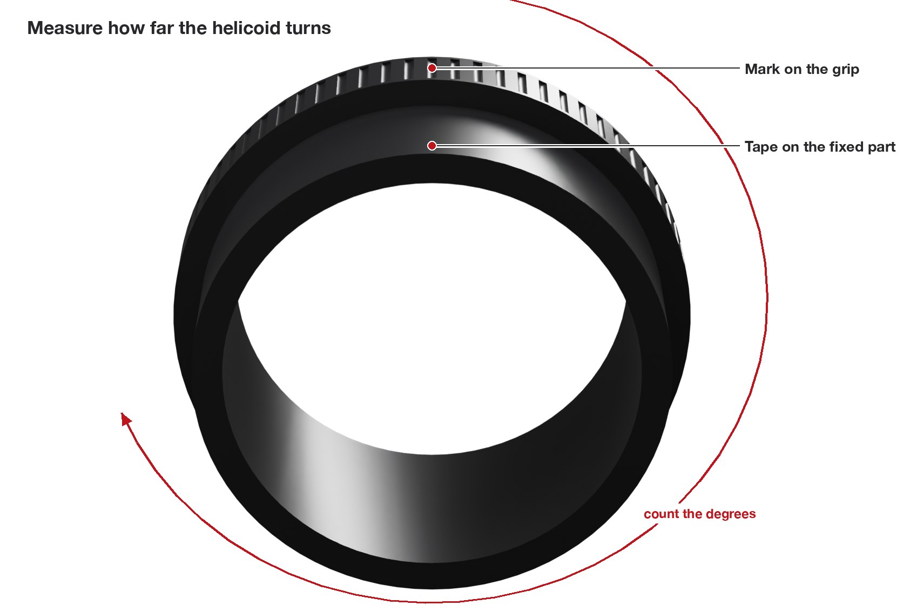
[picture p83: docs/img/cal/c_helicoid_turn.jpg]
How far the helicoid turns


1. **How far does it turn?** Screw it fully in, put a piece of tape on the fixed part and a mark on the grip, and count the degrees (or turns) to fully out. Chinese M65 17-31 helicoids turn anywhere from about 170 to 310 degrees. Write the value in `HELI_ROT` in `params.py` and the turning direction in `FOCUS_DIR`, then export the focus ring again: the distance dots move with it.
2. **Rear thread length.** Measure the male thread at the back: 5 mm or less, or it will not seat in the metal flange.
3. **Does the front rotate?** Hold the rear, turn the grip: the front must move in and out without turning. If it turns, the lens would turn with it; return the helicoid.

## 2. Light test

A single pinhole of light ruins a roll. This test takes ten minutes and finds it before you waste film.

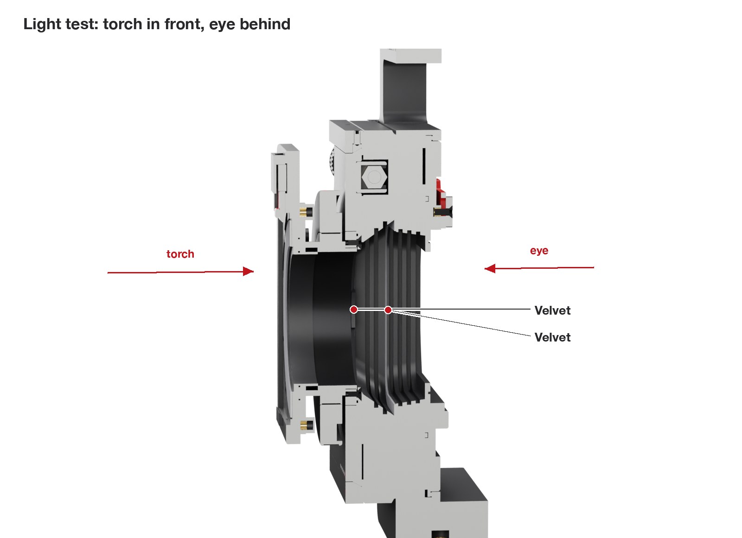
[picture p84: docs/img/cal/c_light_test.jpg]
Light test


1. **From inside.** In a dark room, remove the lens board. Wait two minutes for your eyes to adapt. Shine a strong torch into the camera through the lens opening, and look from behind through the window of the body (no back mounted). You should see the torch only through the window, never around the plates.
2. **From outside.** Put a white sheet of paper behind the body window and move the torch around every edge and gap of the plates, the knobs and the rear frame, where the rotator turns. The paper must stay black.
3. **Repeat at the four corners of the movements:** both knobs at +25 and at -25 mm, in the four combinations. Then turn the back to portrait and do the rear frame again.
4. **Film test.** Load a roll, put the lens cap on, leave the camera in the sun for ten minutes at maximum shift, then develop. The film must come out clear.

**If there is a leak:** it is almost always a velvet edge that lifts, a velvet disc missing over a rise-turret screw, or an insert standing proud. Press the velvet down, put the disc back, or file the insert flush.

## 3. Infinity: teach the camera where infinity is

**What you are doing.** You focus the lens on something very far away, looking at the ground glass, and then fix the focus ring on the helicoid at the angle where its hidden stop rests on the pin of the lens panel. After that, turning the ring to its stop always gives infinity, its red dot faces the red index, and the white distance dots are correct.

Focus ring and lens panel marks

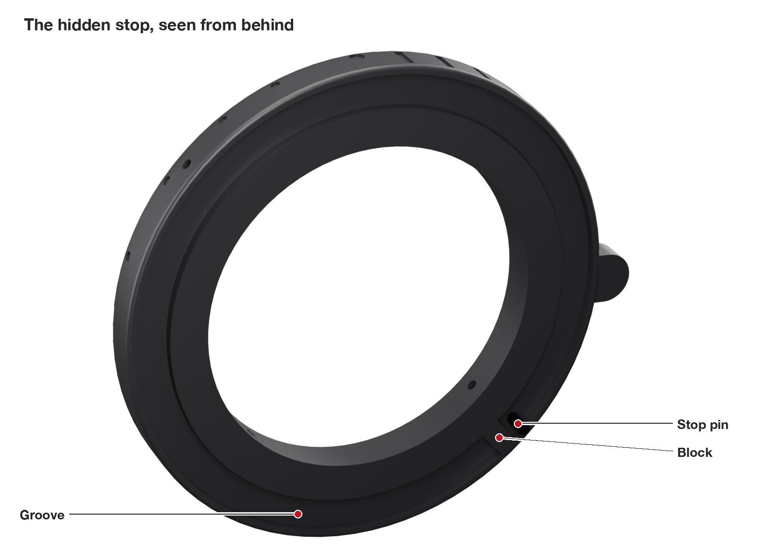
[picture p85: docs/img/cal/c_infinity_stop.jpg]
The hidden stop


**You need:** the ground glass, a loupe, a dark cloth (or a dark jacket), a 1.5 mm hex key for the grub screws, and a day with something at least 200 m away (a church tower, a crane, a mountain).

1. **Set up.** Camera on a tripod, the ground glass on, the lens board in. Both movements at zero (the knobs click).
2. **Open the shutter.** On the shutter, set the speed dial to **T** or **B** and fire, or push the small *press focus* lever if your shutter has one: the blades must stay open. Turn the aperture to its largest opening (smallest number).
3. **Free the focus ring.** Loosen the four grub screws of the ring (A in [step 7](assembly.md#7-helicoid-and-focus-ring)) half a turn, so the ring turns freely on the helicoid.
4. **Focus.** Put the cloth over your head and the camera, and look at the ground glass: aim at the distant object, and put the loupe flat on the glass over it. Turn the **helicoid's own grip** (not the printed ring) in the direction that makes the helicoid shorter, until the object is sharp. Go a little past, then come back, and stop where it is sharpest.
5. **Set the ring.** Without moving the helicoid, turn the printed ring toward infinity until it stops: its hidden block now rests on the stop pin, and its big red dot faces the red dot on the top of the lens panel. Tighten the four grub screws a little at a time, in a cross.
6. **Check** in the loupe that the object is still sharp. If it moved, repeat from step 4.
7. **Close the shutter** (set the speed back from T or B and fire, or release the press-focus lever).

**If infinity cannot be reached** (the helicoid is fully in and the far object is still not sharp), the lens sits too far forward. Reprint the adapter ring thinner: `ADAPTER_T` in `params.py`; 0.5 mm less gives 0.5 mm more. That is what the printed adapter ring is for.

**If the object is sharp with the helicoid far from fully in,** that is fine: the helicoid has 14 mm of travel, and you only need about 7 mm to focus down to 70 cm.

**Reading the ring afterwards.** The white dots on the ring are distances: 5, 3, 2, 1.5, 1 and 0.7 m, read against the red dot on the lens panel. Either side of that red dot are two pairs of white dots: the small pair is f/11, the big pair f/22. After focusing, everything whose distance dot falls between the pair for your aperture is sharp. This is how you can focus without the ground glass.

## 4. More lenses: one stop for all of them

With one lens, section 3 is all you need. A second lens will usually reach infinity at a slightly different place, because every lens has its own distance from the board to the film. You have two choices.

- **Easy way:** always focus on the ground glass (you do anyway for architecture), and ignore the stop with the second lens. Nothing to do.
- **Quick-change way:** make every board reach infinity at the same stop, with a printed **shim**: a thin ring under the shutter that moves that lens forward. Then any lens goes on in ten seconds and is ready at infinity. A shim can only move a lens forward, so the lens that needs the helicoid shortest sets the stop, and the others get a shim.

The shims are on `print/plates/plate_07_shims_0.2mm_layers.3mf`: 0.4, 0.6, 0.8, 1.0 and 1.2 mm. Print them with 0.2 mm layers (the plate says so). The notches on the rim tell the thickness: count them and multiply by 0.2 mm.

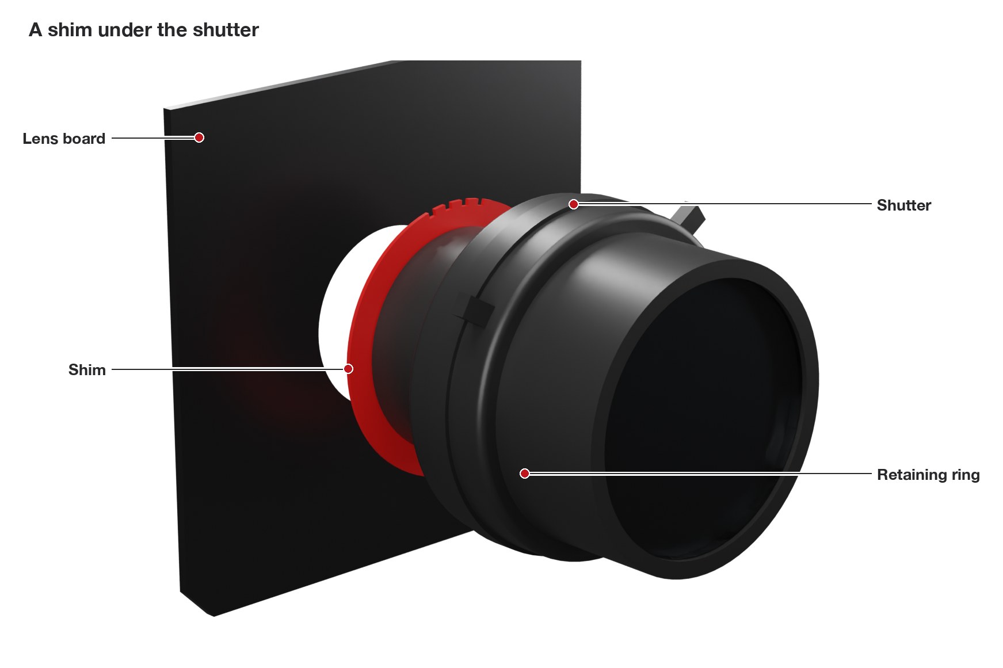
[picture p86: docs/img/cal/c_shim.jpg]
A shim under the shutter


Measure h

1. **Measure lens 1.** With the first lens at infinity (ring on its stop), measure with the depth rod of the caliper from the front face of the lens panel to the front face of the board holder, at the top left corner. Write it down: h1.
2. **Measure lens 2.** Put the second board in. Loosen the ring's grub screws, so the stop does not hold you, and focus at infinity on the ground glass with the helicoid grip, as in section 3. Measure the same way: h2.
3. **Compare.**
   - **h2 larger than h1:** lens 2 needs the helicoid longer than lens 1 does. Shim lens 2 by h2 - h1; lens 1 keeps setting the stop.
   - **h2 smaller than h1:** the other way round. Shim lens 1 by h1 - h2, and set the stop with lens 2 from now on.
4. **Fit the shim.** Unscrew the lens's retaining ring from behind the board, pull the lens out, put the shim on the rear of the shutter, and put the lens back through the board. The shim sits between the shutter and the front of the board. Tighten the retaining ring.
5. **Set the ring** with the lens that has no shim (section 3), then check the other lens at infinity: it should be sharp on the stop.

Round the shim to the nearest 0.2 mm and stack two if needed. The rounding does not matter: at f/11 the film can be 0.6 mm out of place before anything looks soft. For a difference bigger than about 3 mm, add a thicker value to `SHIM_STEPS` in `cad/parts.py` and export again.

Write the shim on a strip of tape on the back of the board.

## 5. Ground glass against film

The frosted surface of the ground glass must sit exactly where the film sits, or what is sharp on the glass is soft on film. The Graflok standard takes care of it, but glasses and backs vary.

The tape measure test

**Simple test (no tools).** Put a tape measure on a table at 45 degrees to the camera, 1 m away. Focus on the 100 cm mark at the widest aperture on the ground glass, then take a picture on film at the widest aperture: the depth of field is then smallest, so the test is sharpest. On the negative, the sharpest mark must be the 100 cm one. If it is clearly closer or further, the glass and the film disagree.

Film and ground glass at the same depth

**Measured test.** With the depth rod of the caliper, measure from the back's nose face to the frosted surface of the glass at five points (centre and four corners), then from the nose face of the film back to its inner film rails (where the emulsion lies, not the outer rails that carry the backing paper). The two must agree within 0.05 mm.

If they do not, shim the ground glass rather than the back: Mercury sells its glasses at RS-0, RS-20 and RS-30 depths for this.

## 6. Lens panel parallel to the film

If the lens is not parallel to the film, one side of the picture is sharper than the other.

Lens board parallel to the film

1. With the caliper's depth rod, measure from the rear face of the rear frame to the front face of the lens board, at the four corners of the board.
2. The four readings must agree within 0.1 mm.
3. Repeat at the four corners of the movements.

If one corner is always off, check the plates for flatness with the straightedge and the gib strips for play before anything else.

## 7. First roll

1. **A wall.** Photograph a flat brick wall at f/8, with the camera square to it, at zero and at maximum rise. Look at the four corners of the negatives with the loupe: they must be as sharp as the centre, apart from the natural softening of the lens.
2. **A ruler.** Repeat the tape measure test of section 5.
3. **Shift.** Photograph a building from close with the camera level, using rise to fit the top in. The verticals must stay vertical.

## 8. If something is wrong

| What you see | Most likely cause | What to do |
|---|---|---|
| A fogged streak on the film, always in the same place | a light leak | section 2; look at the velvet edges, the two velvet discs over the rise-turret screws, and the flange's unused holes (black paint) |
| The whole film is grey | dark slide pulled with the back loose, or a leak at the Graflok | lock the back before pulling the slide; check the nose sits all round (section 1) |
| Nothing is sharp at infinity | the helicoid cannot go far enough in | thinner adapter ring (section 3) |
| Sharp on the ground glass, soft on film | glass and film planes disagree | section 5 |
| One side soft | panel not parallel | section 6 |
| Dark corners at big shifts | beyond the lens's image circle | see the limits below |
| A knob is stiff | O-ring squeezed too much | loosen the grub, back the knob off a quarter turn, lock again |
| A plate moves by itself | O-ring too loose | screw the knob down a quarter turn |
| A plate rocks or clicks when pushed | gib too loose | turn its three grub screws in a little, evenly |
| A plate is hard to move over part of its travel | gib too tight, or a layer sticking out on a flank | back the grubs off an eighth of a turn; file the flank and add dry PTFE |
| The board rattles | latch not down | pull the latch and let it snap down; check the spring |
| The back turns too easily or does not click | the rotator's ball plunger is not pressing enough | it sits under the Y plate: take the front standard off (step 6 backwards), screw the plunger in a quarter turn, and put it back |
| The back is hard to turn | velvet ring V5 too thick, or the rear frame screwed down unevenly | loosen the four frame screws and tighten them again in a cross; if still hard, a thinner ring |

## 9. Limits worth knowing

The camera's own openings were checked with a ray trace (`cad/optics_check.py`) from the lens to the four corners of the 6x7 frame:

Shift limits

- **One movement at a time.** At infinity, rise, fall or shift up to the full 25 mm leave the corners clean at f/22 and at f/8, with the back in landscape or in portrait. Focusing closer moves the lens forward, and the movement along the long side of the frame suffers first. In landscape, rise and fall stay clean to 25 mm down to about 0.9 m, 24 mm at 0.7 m (the closest mark on the ring) and 18 mm at the closest focus (0.47 m); shift stays clean to 24 mm at 0.9 m, 20 mm at 0.7 m and 16 mm at 0.47 m. In portrait the two swap.
- **Rise and shift together.** In both orientations, up to 19 + 19 mm are clean at infinity at f/22, and 17 + 17 at f/8. Focusing closer, the limit drops to 14 + 14 at about 0.9 m, 13 + 13 at 0.7 m and 9 + 9 at the closest focus (0.47 m). The opening that cuts the far corner is the 61 mm bore of the helicoid's rear stub, just behind the lens panel, so large combined movements are an infinity setting. The ground glass shows it: look into each corner from a hand's width away, toward the lens. If you see the whole round aperture, the corner is covered.
- **The lens's image circle.** The Super-Angulon 65/8 (153.5 mm) would cover about 22 + 22 mm, and the Nikkor-SW 65/4 and Grandagon-N 65/4.5 (170 mm) even more: with all three, the camera's own openings (19 + 19 at infinity) are the tighter limit. Measure a lens's rear cell before buying. The adapter and the board holder leave a 59 mm bore: the Nikkor-SW's 54 mm rear cell clears it by 2.5 mm all round. A cell wider than about 58 mm, or longer than about 33 mm behind the shutter flange, can touch the openings at big shifts.
- **Flange focal distance.** The camera is drawn for 70.5 mm from the shutter flange to the film at infinity (the Super-Angulon 65/8). A lens that needs more, such as a Nikkor-SW quoted at 70.8 to 71 mm, simply runs the helicoid out a little further: 14 mm of travel, about 7 used to focus at 0.7 m. A lens that needs up to 1 mm less uses the helicoid's margin; beyond that, reprint the adapter ring thinner (section 3).
- **Fall.** At full fall the Y plate clears a 65 mm clamp's jaws by about 4 mm.

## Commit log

2026-09-27 Calegari View 1: a 3D-printed 6x7 architecture camera
    Rigid 6x7 view camera with screw-driven rise/fall and shift on MGN9 guides,
    M65 helicoid focusing on a metal flange, Mamiya RB67 backs on a Graflok-type
    module, Linhof Technika lens boards, Arca plates for landscape and portrait.
    Parametric build123d model, automated interference, light-seal and
    printability checks, Bambu P1S plates, shopping list, assembly and
    calibration guides, project page.
    [adapter_ring.step, adapter_ring.stl, board_holder.step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]
2026-09-27 L bracket instead of the side handle, symmetric +/-25 mm movements
    - Side loop handle replaced by an L bracket printed with the body: one outline,
    R9 corners, Arca plates for landscape and portrait
    - Top handle flush with the body rear, feet flared into the body
    - Rise and fall now +/-25 mm like the lateral shift; vertical scale reads the
    right way; both guide rails are the same 134 mm
    - Board latch spring hidden under a hood; name engraved on the base
    - Docs and project page updated
    [adapter_ring.step, board_holder.step, board_holder.stl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]
2026-09-27 Export: clean output folders so no stale parts remain (removes the old side handle files)
    [adapter_ring.step, board_holder.step, body.step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]
2026-09-27 Manual for first-timers: lettered part maps, velvet templates, lens shims
    - Every printed part has a lettered map (docs/img/parts) and a table of what
    goes into each hole, with which tool, in which step
    - Velvet and felt modelled (V1 to V4) with 1:1 A4 cutting templates in
    print/templates; felt seat under the lens board deepened to 0.8 mm
    - Quick lens change: one board per lens, printed Copal 0 shims (0.4 to
    1.2 mm, notched by thickness) so every lens reaches infinity on the stop
    - New docs/using.md; calibration rewritten for people new to view cameras
    - ASA shrinkage: FIT clearances on bought-part pockets, 100 mm gauge
    - Section renders without z-fighting on the cut faces
    [adapter_ring.step, board_holder.step, board_holder.stl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]
2026-09-27 Dovetail ways instead of MGN guides, accessory shoes, Leica knobs, dovetail test coupons
    [adapter_ring.step, board_holder.step, body.step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]
2026-09-27 Hidden infinity stop, Leica focusing tab, name plate on the handle, printed grip flutes on the side leg
2026-09-27 More room between the rise knob and the top handle
    [adapter_ring.step, board_holder.step, body.step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]
2026-09-27 Y plate slides in from the top: separate nut turret, rails screwed from the front; stop and flutes follow the helicoid direction
2026-09-27 Review fixes: cap-nut rods, 6x8 bushings, bonded shift turret, front-screwed holder, working detents and Graflok wheel, bull's-eye levels, light traps, flare lobes, stricter checks, ray-trace vignett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
    [adapter_ring.step, adapter_ring.stl, board_holder.step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]
2026-09-28 Second review round: keyed shift turret, rod lengths for real cap nuts, M2.5 rail screws, working latch bosses, hood, lobes, velvet discs, detent moved, velvet-based seal sweep, pupil range in the op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
    [adapter_ring.step, adapter_ring.stl, board_holder.step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]
2026-09-28 Third review round: latch on washers, shift rod with washer, rail chamfers, faceted handle feet, clean dimples; all images, plates and docs regenerated; BOM links filled
    [adapter_ring.step, board_holder.step, board_holder.stl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]
2026-09-28 No hardware in sight: shift rod ends in a blind seat with an inner thrust nut, screwless board latch in a dovetail; assembly guide in 40 illustrated sub-steps, illustrated calibration guide
    [adapter_ring.step, board_holder.step, board_holder.stl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]
2026-09-28 All small hardware in M3: one insert size, socket heads from one kit, countersunk only where a head must sit flush, one grub size; plain M6 nut instead of the cap nut, one screw per Arca plate
    [adapter_ring.step, adapter_ring.stl, board_holder.step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]
2026-09-28 Pre-print review: shift turret open underneath so it drops over the rod and nut, Loctite kept off the bushing, board latch lifted by thumb, thicker walls at the vertical rail screws, 3 mm Graflok whe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
    [adapter_ring.step, board_holder.step, board_holder.stl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]
2026-09-28 Ray trace: model the helicoid's rear stub (61 mm bore), relieve the lens panel behind the flange; combined movements verified clean to 19 + 19 at infinity f/22, 17 + 17 at f/8, 14 + 14 at 0.9 m, 13 +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
    [adapter_ring.step, board_holder.step, body.step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]
2026-09-28 Rotating back, 170 mm square body, one Arca plate
    The film back now sits on a round rotator that turns a quarter turn in the
    body's rear face for portrait: a rear frame with four M3 holds its flange
    over a velvet ring, a labyrinth keeps light out while it turns, a POM ball
    plunger clicks at landscape and portrait and a grub in an arc groove stops
    it just past both. The L bracket, the side Arca plate and the side level
    are gone: the camera stays upright and one level serves both orientations.
    The body grows to 170 mm square around the rotator, with 12 mm window
    corners. The top handle keeps its loop shape with the rise knob on the body.
    Checks: 0 interferences in landscape, portrait and at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
    [adapter_ring.step, bezel.step, bezel.stl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]
2026-09-28 Illustrate every guide, close the audit findings
    Figures for every guide: using the camera (set up, landscape and portrait,
    back on and off, reading rise and shift, lens change), every print plate as
    export.py lays it on the bed (cad/plate_figs.py), what you buy shown in place
    for the shopping list, section and exploded views in the design notes.
    The ray trace now also checks the true closest focus (0.47 m): 16 mm of shift,
    18 of rise and 9 + 9 combined are clean there; docs and the limits diagram
    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
    [adapter_ring.step, bezel.step, board_holder.step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]
